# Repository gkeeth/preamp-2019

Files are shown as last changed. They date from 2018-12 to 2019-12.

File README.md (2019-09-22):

# preamp-2019

Balanced input & output preamplifier with volume and balance controls.

Based on preamps designed by Doug Self (see Small Signal Audio Design by Douglas Self)

The preamp is split over several PCBs, with a kicad project for each:
1. balanced_amplifier: balanced amplifier with volume/balance controls
2. power_supply: power supplies for
    - positive analog rail
    - negative analog rail
    - digital/relay rail
3. input_output_board: board with input/output jacks and relays to select the desired input
4. front_panel_board: board with input selection switch and headphone/main output switch
5. headphone_amp: a very basic headphone amplifier that converts the balanced
   output of the balanced_amplifier board to an unbalanced signal, and buffers it

This work is licensed under a [Creative Commons Attribution-ShareAlike 4.0
International License][cc-by-sa].

[][cc-by-sa]

[cc-by-sa]: http://creativecommons.org/licenses/by-sa/4.0/
[cc-by-sa-image]: https://licensebuttons.net/l/by-sa/4.0/88x31.png
[cc-by-sa-shield]: https://img.shields.io/badge/License-CC%20BY--SA%204.0-lightgrey.svg

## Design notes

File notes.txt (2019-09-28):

enclosure: consider Hammond 1441-16BK3CWW
enclosure: Hammond 1444-24
dimensions: 12" x 8" x 3"
necessary parts:
 - enclosure (1444-24)
 - bottom plate (1434-22)
 - screws (1421J6)
 - feet (1421T6CL)

transformer: Triad VPT30-830
dimensions: 74mm D x 34mm H
15VAC parallel / 30VAC series, 25VA max

power switch: consider E-switch RC1083BBLKBLKFF0
4.7mm faston/0.187"

power filter/inlet: consider Schaffner FN9260-6-06
faston 6.3mm/0.25"

input selection switch: https://www.digikey.com/product-detail/en/c-k/A10405RNCQ/CKN11161-ND/3751691
8pos, adjustable stop, 45deg throw: https://www.digikey.com/products/en?keywords=a12505rncq

input jacks: NCJ6FA-H-0
output jacks: NC3MAH

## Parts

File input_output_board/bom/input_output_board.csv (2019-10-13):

Source: | /home/graham/Projects/preamp-2019/input_output_board/input_output_board.sch
Date: | Sun 13 Oct 2019 07:21:07 PM EDT
Tool: | Eeschema 5.1.4
Generator: | /usr/share/kicad/plugins/bom_csv_grouped_by_value.py
Component Count: | 19
Individual Components:
Item | Qty | Reference(s) | Value | LibPart | Footprint | Datasheet | Distributor | Distributor PN | Manufacturer | Manufacturer PN | URL | Unit Price
 |  | D1 | MRA4004T3G | Device:D | Diode_SMD:D_SMA | http://www.onsemi.com/pub_link/Collateral/MRA4003T3-D.PDF | Digikey | MRA4004T3GOSCT-ND | On Semiconductor | MRA4004T3G | https://www.digikey.com/products/en/discrete-semiconductor-products/diodes-rectifiers-single/280?k=MRA4004T3G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 | 0.29
 |  | D2 | MRA4004T3G | Device:D | Diode_SMD:D_SMA | http://www.onsemi.com/pub_link/Collateral/MRA4003T3-D.PDF | Digikey | MRA4004T3GOSCT-ND | On Semiconductor | MRA4004T3G | https://www.digikey.com/products/en/discrete-semiconductor-products/diodes-rectifiers-single/280?k=MRA4004T3G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 | 0.29
 |  | D3 | MRA4004T3G | Device:D | Diode_SMD:D_SMA | http://www.onsemi.com/pub_link/Collateral/MRA4003T3-D.PDF | Digikey | MRA4004T3GOSCT-ND | On Semiconductor | MRA4004T3G | https://www.digikey.com/products/en/discrete-semiconductor-products/diodes-rectifiers-single/280?k=MRA4004T3G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 | 0.29
 |  | D4 | MRA4004T3G | Device:D | Diode_SMD:D_SMA | http://www.onsemi.com/pub_link/Collateral/MRA4003T3-D.PDF | Digikey | MRA4004T3GOSCT-ND | On Semiconductor | MRA4004T3G | https://www.digikey.com/products/en/discrete-semiconductor-products/diodes-rectifiers-single/280?k=MRA4004T3G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 | 0.29
 |  | D5 | MRA4004T3G | Device:D | Diode_SMD:D_SMA | http://www.onsemi.com/pub_link/Collateral/MRA4003T3-D.PDF | Digikey | MRA4004T3GOSCT-ND | On Semiconductor | MRA4004T3G | https://www.digikey.com/products/en/discrete-semiconductor-products/diodes-rectifiers-single/280?k=MRA4004T3G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 | 0.29
 |  | J1 | Neutrik_NCJ6FA-H-0 | Connector_gkeeth:Neutrik_NCJ6FA-H-0 | Connector_Audio_project:Jack_XLR-6.35mm_Neutrik_NCJ6FA-H-0_Horizontal | https://www.neutrik.us/en-us/product/ncj6fa-h-0 | Mouser | 568-NCJ6FA-H-0 | Neutrik | NCJ6FA-H-0 | https://www.mouser.com/ProductDetail/Neutrik/NCJ6FA-H-0?qs=sGAEpiMZZMv0W4pxf2HiVz0kF5fvPbmUN84Qkb8AgIM%3D | 2.14
 |  | J2 | Neutrik_NCJ6FA-H-0 | Connector_gkeeth:Neutrik_NCJ6FA-H-0 | Connector_Audio_project:Jack_XLR-6.35mm_Neutrik_NCJ6FA-H-0_Horizontal | https://www.neutrik.us/en-us/product/ncj6fa-h-0 | Mouser | 568-NCJ6FA-H-0 | Neutrik | NCJ6FA-H-0 | https://www.mouser.com/ProductDetail/Neutrik/NCJ6FA-H-0?qs=sGAEpiMZZMv0W4pxf2HiVz0kF5fvPbmUN84Qkb8AgIM%3D | 2.14
 |  | J3 | Neutrik_NCJ6FA-H-0 | Connector_gkeeth:Neutrik_NCJ6FA-H-0 | Connector_Audio_project:Jack_XLR-6.35mm_Neutrik_NCJ6FA-H-0_Horizontal | https://www.neutrik.us/en-us/product/ncj6fa-h-0 | Mouser | 568-NCJ6FA-H-0 | Neutrik | NCJ6FA-H-0 | https://www.mouser.com/ProductDetail/Neutrik/NCJ6FA-H-0?qs=sGAEpiMZZMv0W4pxf2HiVz0kF5fvPbmUN84Qkb8AgIM%3D | 2.14
 |  | J4 | Neutrik_NCJ6FA-H-0 | Connector_gkeeth:Neutrik_NCJ6FA-H-0 | Connector_Audio_project:Jack_XLR-6.35mm_Neutrik_NCJ6FA-H-0_Horizontal | https://www.neutrik.us/en-us/product/ncj6fa-h-0 | Mouser | 568-NCJ6FA-H-0 | Neutrik | NCJ6FA-H-0 | https://www.mouser.com/ProductDetail/Neutrik/NCJ6FA-H-0?qs=sGAEpiMZZMv0W4pxf2HiVz0kF5fvPbmUN84Qkb8AgIM%3D | 2.14
 |  | J5 | Neutrik_NC3MAH | Connector_gkeeth:Neutrik_NC3MAH | Connector_Audio_project:Jack_XLR_Neutrik_NC3MAH_Horizontal | https://www.neutrik.us/en-us/product/nc3mah | Mouser | 568-NC3MAH | Neutrik | NC3MAH | https://www.mouser.com/ProductDetail/Neutrik/NC3MAH | 1.25
 |  | J6 | Conn_02x05_Odd_Even | Connector_Generic:Conn_02x05_Odd_Even | Connector_Molex_C-Grid:Molex_C-Grid_70246-1001_2x05_P2.54mm_Vertical | https://www.molex.com/pdm_docs/sd/702461001_sd.pdf | Digikey | WM9219-ND | Molex | 0702461001 | https://www.digikey.com/products/en?keywords=70246-1001 | 1.70
 |  | J7 | Molex_SL_01x02_Male | Connector_gkeeth:Molex_SL_01x02_Male | Connector_Molex_SL:Molex_SL_A-70553-0001_1x02_P2.54mm_Horizontal | https://www.molex.com/pdm_docs/sd/705430001_sd.pdf | Digikey | WM4900-ND | Molex | 0705430001 | https://www.digikey.com/products/en?keywords=70553-0001 | 0.74
 |  | J8 | Molex_SL_01x02_Male | Connector_gkeeth:Molex_SL_01x02_Male | Connector_Molex_SL:Molex_SL_A-70553-0001_1x02_P2.54mm_Horizontal | https://www.molex.com/pdm_docs/sd/705430001_sd.pdf | Digikey | WM4900-ND | Molex | 0705430001 | https://www.digikey.com/products/en?keywords=70553-0001 | 0.74
 |  | J9 | Molex_SL_01x02_Male | Connector_gkeeth:Molex_SL_01x02_Male | Connector_Molex_SL:Molex_SL_A-70553-0001_1x02_P2.54mm_Horizontal | https://www.molex.com/pdm_docs/sd/705430001_sd.pdf | Digikey | WM4900-ND | Molex | 0705430001 | https://www.digikey.com/products/en?keywords=70553-0001 | 0.74
 |  | K1 | G6S-2 | Relay:G6S-2 | Relay_SMD:Relay_DPDT_Omron_G6S-2F | http://omronfs.omron.com/en_US/ecb/products/pdf/en-g6s.pdf | Digikey | Z889-ND | Omron | G6S-2F DC12 | https://www.digikey.com/product-detail/en/omron-electronics-inc-emc-div/G6S-2F-DC12/Z889-ND/27491 | 3.64
 |  | K2 | G6S-2 | Relay:G6S-2 | Relay_SMD:Relay_DPDT_Omron_G6S-2F | http://omronfs.omron.com/en_US/ecb/products/pdf/en-g6s.pdf | Digikey | Z889-ND | Omron | G6S-2F DC12 | https://www.digikey.com/product-detail/en/omron-electronics-inc-emc-div/G6S-2F-DC12/Z889-ND/27491 | 3.64
 |  | K3 | G6S-2 | Relay:G6S-2 | Relay_SMD:Relay_DPDT_Omron_G6S-2F | http://omronfs.omron.com/en_US/ecb/products/pdf/en-g6s.pdf | Digikey | Z889-ND | Omron | G6S-2F DC12 | https://www.digikey.com/product-detail/en/omron-electronics-inc-emc-div/G6S-2F-DC12/Z889-ND/27491 | 3.64
 |  | K4 | G6S-2 | Relay:G6S-2 | Relay_SMD:Relay_DPDT_Omron_G6S-2F | http://omronfs.omron.com/en_US/ecb/products/pdf/en-g6s.pdf | Digikey | Z889-ND | Omron | G6S-2F DC12 | https://www.digikey.com/product-detail/en/omron-electronics-inc-emc-div/G6S-2F-DC12/Z889-ND/27491 | 3.64
 |  | K5 | G6S-2 | Relay:G6S-2 | Relay_SMD:Relay_DPDT_Omron_G6S-2F | http://omronfs.omron.com/en_US/ecb/products/pdf/en-g6s.pdf | Digikey | Z889-ND | Omron | G6S-2F DC12 | https://www.digikey.com/product-detail/en/omron-electronics-inc-emc-div/G6S-2F-DC12/Z889-ND/27491 | 3.64
Collated Components:
Item | Qty | Reference(s) | Value | LibPart | Footprint | Datasheet | Distributor | Distributor PN | Manufacturer | Manufacturer PN | URL | Unit Price
1 | 5 | D1, D2, D3, D4, D5 | MRA4004T3G | Device:D | Diode_SMD:D_SMA | http://www.onsemi.com/pub_link/Collateral/MRA4003T3-D.PDF | Digikey | MRA4004T3GOSCT-ND | On Semiconductor | MRA4004T3G | https://www.digikey.com/products/en/discrete-semiconductor-products/diodes-rectifiers-single/280?k=MRA4004T3G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 | 0.29
2 | 4 | J1, J2, J3, J4 | Neutrik_NCJ6FA-H-0 | Connector_gkeeth:Neutrik_NCJ6FA-H-0 | Connector_Audio_project:Jack_XLR-6.35mm_Neutrik_NCJ6FA-H-0_Horizontal | https://www.neutrik.us/en-us/product/ncj6fa-h-0 | Mouser | 568-NCJ6FA-H-0 | Neutrik | NCJ6FA-H-0 | https://www.mouser.com/ProductDetail/Neutrik/NCJ6FA-H-0?qs=sGAEpiMZZMv0W4pxf2HiVz0kF5fvPbmUN84Qkb8AgIM%3D | 2.14
3 | 1 | J5 | Neutrik_NC3MAH | Connector_gkeeth:Neutrik_NC3MAH | Connector_Audio_project:Jack_XLR_Neutrik_NC3MAH_Horizontal | https://www.neutrik.us/en-us/product/nc3mah | Mouser | 568-NC3MAH | Neutrik | NC3MAH | https://www.mouser.com/ProductDetail/Neutrik/NC3MAH | 1.25
4 | 1 | J6 | Conn_02x05_Odd_Even | Connector_Generic:Conn_02x05_Odd_Even | Connector_Molex_C-Grid:Molex_C-Grid_70246-1001_2x05_P2.54mm_Vertical | https://www.molex.com/pdm_docs/sd/702461001_sd.pdf | Digikey | WM9219-ND | Molex | 0702461001 | https://www.digikey.com/products/en?keywords=70246-1001 | 1.70
5 | 3 | J7, J8, J9 | Molex_SL_01x02_Male | Connector_gkeeth:Molex_SL_01x02_Male | Connector_Molex_SL:Molex_SL_A-70553-0001_1x02_P2.54mm_Horizontal | https://www.molex.com/pdm_docs/sd/705430001_sd.pdf | Digikey | WM4900-ND | Molex | 0705430001 | https://www.digikey.com/products/en?keywords=70553-0001 | 0.74
6 | 5 | K1, K2, K3, K4, K5 | G6S-2 | Relay:G6S-2 | Relay_SMD:Relay_DPDT_Omron_G6S-2F | http://omronfs.omron.com/en_US/ecb/products/pdf/en-g6s.pdf | Digikey | Z889-ND | Omron | G6S-2F DC12 | https://www.digikey.com/product-detail/en/omron-electronics-inc-emc-div/G6S-2F-DC12/Z889-ND/27491 | 3.64

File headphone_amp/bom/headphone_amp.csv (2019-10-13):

Source: | /home/graham/Projects/preamp-2019/headphone_amp/headphone_amp.sch
Date: | Sun 13 Oct 2019 07:17:30 PM EDT
Tool: | Eeschema 5.1.4
Generator: | /usr/share/kicad/plugins/bom_csv_grouped_by_value.py
Component Count: | 41
Individual Components:
Item | Qty | Reference(s) | Value | LibPart | Footprint | Datasheet | Dielectric | Distributor | Distributor PN | Manufacturer | Manufacturer PN | URL | Unit Price | Voltage Rating
 |  | C1 | 22p | Device:C | Capacitor_SMD:C_0603_1608Metric_Pad1.05x0.95mm_HandSolder | ~ | C0G/NP0 | Mouser | 80-C0603C220J5G7411 | KEMET | C0603C220J5GAC7411 | https://www.mouser.com/ProductDetail/80-C0603C220J5G7411 | 0.23
 |  | C2 | 22p | Device:C | Capacitor_SMD:C_0603_1608Metric_Pad1.05x0.95mm_HandSolder | ~ | C0G/NP0 | Mouser | 80-C0603C220J5G7411 | KEMET | C0603C220J5GAC7411 | https://www.mouser.com/ProductDetail/80-C0603C220J5G7411 | 0.23
 |  | C3 | 220u | Device:C | Capacitor_THT:C_Radial_D12.5mm_H20.0mm_P5.00mm | http://nichicon-us.com/english/products/pdfs/e-uvp.pdf | Nonpolarized Electrolytic | Digikey | 493-16138-ND | Nichicon | UVP1V221MHD | https://www.digikey.com/product-detail/en/nichicon/UVP1V221MHD/493-16138-ND/2539596 | 0.87 | 35V
 |  | C4 | 22p | Device:C | Capacitor_SMD:C_0603_1608Metric_Pad1.05x0.95mm_HandSolder | ~ | C0G/NP0 | Mouser | 80-C0603C220J5G7411 | KEMET | C0603C220J5GAC7411 | https://www.mouser.com/ProductDetail/80-C0603C220J5G7411 | 0.23
 |  | C5 | 22p | Device:C | Capacitor_SMD:C_0603_1608Metric_Pad1.05x0.95mm_HandSolder | ~ | C0G/NP0 | Mouser | 80-C0603C220J5G7411 | KEMET | C0603C220J5GAC7411 | https://www.mouser.com/ProductDetail/80-C0603C220J5G7411 | 0.23
 |  | C6 | 220u | Device:C | Capacitor_THT:C_Radial_D12.5mm_H20.0mm_P5.00mm | http://nichicon-us.com/english/products/pdfs/e-uvp.pdf | Nonpolarized Electrolytic | Digikey | 493-16138-ND | Nichicon | UVP1V221MHD | https://www.digikey.com/product-detail/en/nichicon/UVP1V221MHD/493-16138-ND/2539596 | 0.87 | 35V
 |  | C7 | 100n | Device:C | Capacitor_SMD:C_0805_2012Metric_Pad1.15x1.40mm_HandSolder | https://psearch.en.murata.com/capacitor/product/GCM21BR72A104KA37%23.pdf | X7R | Digikey | 490-8051-1-ND | Murata | GCM21BR72A104KA37K | https://www.digikey.com/product-detail/en/murata-electronics-north-america/GCM21BR72A104KA37K/490-8051-1-ND/4380336 | 0.43
 |  | C8 | 100u | Device:CP1 | Capacitor_THT:CP_Radial_D6.3mm_P2.50mm | http://nichicon-us.com/english/products/pdfs/e-uvr.pdf | Electrolytic | Digikey | 493-1081-ND | Nichicon | UVR1V101MED | https://www.digikey.com/product-detail/en/nichicon/UVR1V101MED/493-1081-ND/588822 | 0.26 | 35V
 |  | C9 | 100u | Device:CP1 | Capacitor_THT:CP_Radial_D6.3mm_P2.50mm | http://nichicon-us.com/english/products/pdfs/e-uvr.pdf | Electrolytic | Digikey | 493-1081-ND | Nichicon | UVR1V101MED | https://www.digikey.com/product-detail/en/nichicon/UVR1V101MED/493-1081-ND/588822 | 0.26 | 35V
 |  | D1 | 1N4148WS | Diode:1N4148WS | Diode_SMD:D_SOD-323 | https://www.vishay.com/docs/85751/1n4148ws.pdf |  | Mouser | 512-1N4148WS | ON Semiconductor | 1N4148WS | https://www.mouser.com/ProductDetail/512-1N4148WS | 0.15
 |  | D2 | 1N4148WS | Diode:1N4148WS | Diode_SMD:D_SOD-323 | https://www.vishay.com/docs/85751/1n4148ws.pdf |  | Mouser | 512-1N4148WS | ON Semiconductor | 1N4148WS | https://www.mouser.com/ProductDetail/512-1N4148WS | 0.15
 |  | D3 | 1N4148WS | Diode:1N4148WS | Diode_SMD:D_SOD-323 | https://www.vishay.com/docs/85751/1n4148ws.pdf |  | Mouser | 512-1N4148WS | ON Semiconductor | 1N4148WS | https://www.mouser.com/ProductDetail/512-1N4148WS | 0.15
 |  | D4 | 1N4148WS | Diode:1N4148WS | Diode_SMD:D_SOD-323 | https://www.vishay.com/docs/85751/1n4148ws.pdf |  | Mouser | 512-1N4148WS | ON Semiconductor | 1N4148WS | https://www.mouser.com/ProductDetail/512-1N4148WS | 0.15
 |  | H1 | MountingHole_Pad | Mechanical:MountingHole_Pad | MountingHole:MountingHole_3.2mm_M3_Pad | ~
 |  | H2 | MountingHole_Pad | Mechanical:MountingHole_Pad | MountingHole:MountingHole_3.2mm_M3_Pad | ~
 |  | J1 | Molex_SL_01x02_Male | Connector_gkeeth:Molex_SL_01x02_Male | Connector_Molex_SL:Molex_SL_A-70553-0001_1x02_P2.54mm_Horizontal | https://www.molex.com/pdm_docs/sd/705430001_sd.pdf |  | Mouser | 538-70553-0001 | Molex | 70553-0001 | https://www.mouser.com/ProductDetail/538-70553-0001 | 0.71
 |  | J2 | Molex_SL_01x02_Male | Connector_gkeeth:Molex_SL_01x02_Male | Connector_Molex_SL:Molex_SL_A-70553-0001_1x02_P2.54mm_Horizontal | https://www.molex.com/pdm_docs/sd/705430001_sd.pdf |  | Mouser | 538-70553-0001 | Molex | 70553-0001 | https://www.mouser.com/ProductDetail/538-70553-0001 | 0.71
 |  | J3 | Molex_SL_01x03_Male | Connector_gkeeth:Molex_SL_01x03_Male | Connector_Molex_SL:Molex_SL_A-70553-0002_1x03_P2.54mm_Horizontal | https://www.molex.com/pdm_docs/sd/705430001_sd.pdf |  | Mouser | 538-70553-0002 | Molex | 70553-0002 | https://www.mouser.com/ProductDetail/538-70553-0002 | 1.12
 |  | J4 | Molex_SL_01x03_Male | Connector_gkeeth:Molex_SL_01x03_Male | Connector_Molex_SL:Molex_SL_A-70553-0002_1x03_P2.54mm_Horizontal | https://www.molex.com/pdm_docs/sd/705430001_sd.pdf |  | Mouser | 538-70553-0002 | Molex | 70553-0002 | https://www.mouser.com/ProductDetail/538-70553-0002 | 1.12
 |  | NT1 | Net-Tie_2 | Device:Net-Tie_2 | NetTie:NetTie-2_SMD_Pad2.0mm | ~
 |  | Q1 | PZTA42 | Transistor_BJT:PZTA42 | Package_TO_SOT_SMD:SOT-223-3_TabPin2 | https://www.onsemi.com/pub/Collateral/PZTA42T1-D.PDF |  | Digikey | PZTA42T1GOSCT-ND | ON Semiconductor | PZTA42T1G | https://www.digikey.com/product-detail/en/on-semiconductor/PZTA42T1G/PZTA42T1GOSCT-ND/1139989 | 0.43
 |  | Q2 | PZTA92 | Transistor_BJT:PZTA92 | Package_TO_SOT_SMD:SOT-223-3_TabPin2 | https://www.onsemi.com/pub/Collateral/PZTA92T1-D.PDF |  | Digikey | PZTA92T1GOSCT-ND | ON Semiconductor | PZTA92T1G | https://www.digikey.com/product-detail/en/on-semiconductor/PZTA92T1G/PZTA92T1GOSCT-ND/920290 | 0.44
 |  | Q3 | PZTA42 | Transistor_BJT:PZTA42 | Package_TO_SOT_SMD:SOT-223-3_TabPin2 | https://www.onsemi.com/pub/Collateral/PZTA42T1-D.PDF |  | Digikey | PZTA42T1GOSCT-ND | ON Semiconductor | PZTA42T1G | https://www.digikey.com/product-detail/en/on-semiconductor/PZTA42T1G/PZTA42T1GOSCT-ND/1139989 | 0.43
 |  | Q4 | PZTA92 | Transistor_BJT:PZTA92 | Package_TO_SOT_SMD:SOT-223-3_TabPin2 | https://www.onsemi.com/pub/Collateral/PZTA92T1-D.PDF |  | Digikey | PZTA92T1GOSCT-ND | ON Semiconductor | PZTA92T1G | https://www.digikey.com/product-detail/en/on-semiconductor/PZTA92T1G/PZTA92T1GOSCT-ND/920290 | 0.44
 |  | R1 | 10k | Device:R | Resistor_SMD:R_0603_1608Metric_Pad1.05x0.95mm_HandSolder | http://www.yageo.com/documents/recent/PYu-RT_1-to-0.01_RoHS_L_11.pdf |  | Digikey | YAG2321CT-ND | Yageo | RT0603FRE0710KL | https://www.digikey.com/product-detail/en/yageo/RT0603FRE0710KL/YAG2321CT-ND/5252435 | 0.10
 |  | R2 | 22k | Device:R | Resistor_SMD:R_0603_1608Metric_Pad1.05x0.95mm_HandSolder | http://www.yageo.com/documents/recent/PYu-RT_1-to-0.01_RoHS_L_11.pdf |  | Mouser | 603-RT0603FRE1322KL | Yageo | RT0603FRE1322KL | https://www.mouser.com/ProductDetail/603-RT0603FRE1322KL | 0.19
 |  | R3 | 10k | Device:R | Resistor_SMD:R_0603_1608Metric_Pad1.05x0.95mm_HandSolder | http://www.yageo.com/documents/recent/PYu-RT_1-to-0.01_RoHS_L_11.pdf |  | Digikey | YAG2321CT-ND | Yageo | RT0603FRE0710KL | https://www.digikey.com/product-detail/en/yageo/RT0603FRE0710KL/YAG2321CT-ND/5252435 | 0.10
 |  | R4 | 22k | Device:R | Resistor_SMD:R_0603_1608Metric_Pad1.05x0.95mm_HandSolder | http://www.yageo.com/documents/recent/PYu-RT_1-to-0.01_RoHS_L_11.pdf |  | Mouser | 603-RT0603FRE1322KL | Yageo | RT0603FRE1322KL | https://www.mouser.com/ProductDetail/603-RT0603FRE1322KL | 0.19
 |  | R5 | 4.7k | Device:R | Resistor_SMD:R_0603_1608Metric_Pad1.05x0.95mm_HandSolder | http://www.yageo.com/documents/recent/PYu-RT_1-to-0.01_RoHS_L_11.pdf |  | Mouser | 603-RT0603FRE074K7L | Yageo | RT0603FRE074K7L | https://www.mouser.com/ProductDetail/603-RT0603FRE074K7L | 0.10
 |  | R6 | 10 | Device:R | Resistor_SMD:R_0603_1608Metric_Pad1.05x0.95mm_HandSolder | https://www.seielect.com/Catalog/SEI-rncp.pdf |  | Digikey | RNCP0603FTD10R0CT-ND | Stackpole | RNCP0603FTD10R0 | https://www.digikey.com/product-detail/en/stackpole-electronics-inc/RNCP0603FTD10R0/RNCP0603FTD10R0CT-ND/2240413 | 0.10
 |  | R7 | 10 | Device:R | Resistor_SMD:R_0603_1608Metric_Pad1.05x0.95mm_HandSolder | https://www.seielect.com/Catalog/SEI-rncp.pdf |  | Digikey | RNCP0603FTD10R0CT-ND | Stackpole | RNCP0603FTD10R0 | https://www.digikey.com/product-detail/en/stackpole-electronics-inc/RNCP0603FTD10R0/RNCP0603FTD10R0CT-ND/2240413 | 0.10
 |  | R8 | 22k | Device:R | Resistor_SMD:R_0603_1608Metric_Pad1.05x0.95mm_HandSolder | http://www.yageo.com/documents/recent/PYu-RT_1-to-0.01_RoHS_L_11.pdf |  | Mouser | 603-RT0603FRE1322KL | Yageo | RT0603FRE1322KL | https://www.mouser.com/ProductDetail/603-RT0603FRE1322KL | 0.19
 |  | R9 | 10k | Device:R | Resistor_SMD:R_0603_1608Metric_Pad1.05x0.95mm_HandSolder | http://www.yageo.com/documents/recent/PYu-RT_1-to-0.01_RoHS_L_11.pdf |  | Digikey | YAG2321CT-ND | Yageo | RT0603FRE0710KL | https://www.digikey.com/product-detail/en/yageo/RT0603FRE0710KL/YAG2321CT-ND/5252435 | 0.10
 |  | R10 | 22k | Device:R | Resistor_SMD:R_0603_1608Metric_Pad1.05x0.95mm_HandSolder | http://www.yageo.com/documents/recent/PYu-RT_1-to-0.01_RoHS_L_11.pdf |  | Mouser | 603-RT0603FRE1322KL | Yageo | RT0603FRE1322KL | https://www.mouser.com/ProductDetail/603-RT0603FRE1322KL | 0.19
 |  | R11 | 10k | Device:R | Resistor_SMD:R_0603_1608Metric_Pad1.05x0.95mm_HandSolder | http://www.yageo.com/documents/recent/PYu-RT_1-to-0.01_RoHS_L_11.pdf |  | Digikey | YAG2321CT-ND | Yageo | RT0603FRE0710KL | https://www.digikey.com/product-detail/en/yageo/RT0603FRE0710KL/YAG2321CT-ND/5252435 | 0.10
 |  | R12 | 22k | Device:R | Resistor_SMD:R_0603_1608Metric_Pad1.05x0.95mm_HandSolder | http://www.yageo.com/documents/recent/PYu-RT_1-to-0.01_RoHS_L_11.pdf |  | Mouser | 603-RT0603FRE1322KL | Yageo | RT0603FRE1322KL | https://www.mouser.com/ProductDetail/603-RT0603FRE1322KL | 0.19
 |  | R13 | 4.7k | Device:R | Resistor_SMD:R_0603_1608Metric_Pad1.05x0.95mm_HandSolder | http://www.yageo.com/documents/recent/PYu-RT_1-to-0.01_RoHS_L_11.pdf |  | Mouser | 603-RT0603FRE074K7L | Yageo | RT0603FRE074K7L | https://www.mouser.com/ProductDetail/603-RT0603FRE074K7L | 0.10
 |  | R14 | 10 | Device:R | Resistor_SMD:R_0603_1608Metric_Pad1.05x0.95mm_HandSolder | https://www.seielect.com/Catalog/SEI-rncp.pdf |  | Digikey | RNCP0603FTD10R0CT-ND | Stackpole | RNCP0603FTD10R0 | https://www.digikey.com/product-detail/en/stackpole-electronics-inc/RNCP0603FTD10R0/RNCP0603FTD10R0CT-ND/2240413 | 0.10
 |  | R15 | 10 | Device:R | Resistor_SMD:R_0603_1608Metric_Pad1.05x0.95mm_HandSolder | https://www.seielect.com/Catalog/SEI-rncp.pdf |  | Digikey | RNCP0603FTD10R0CT-ND | Stackpole | RNCP0603FTD10R0 | https://www.digikey.com/product-detail/en/stackpole-electronics-inc/RNCP0603FTD10R0/RNCP0603FTD10R0CT-ND/2240413 | 0.10
 |  | R16 | 22k | Device:R | Resistor_SMD:R_0603_1608Metric_Pad1.05x0.95mm_HandSolder | http://www.yageo.com/documents/recent/PYu-RT_1-to-0.01_RoHS_L_11.pdf |  | Mouser | 603-RT0603FRE1322KL | Yageo | RT0603FRE1322KL | https://www.mouser.com/ProductDetail/603-RT0603FRE1322KL | 0.19
 |  | U1 | NE5532 | Amplifier_Operational:NE5532 | Package_SO:SOIC-8_3.9x4.9mm_P1.27mm | http://www.ti.com/lit/ds/symlink/ne5532.pdf |  | Digikey | NE5532AD8R2GOSCT-ND | ON Semiconductor | NE5532AD8R2G | https://www.digikey.com/products/en?keywords=NE5532AD8R2GOSCT-ND | 0.90
Collated Components:
Item | Qty | Reference(s) | Value | LibPart | Footprint | Datasheet | Dielectric | Distributor | Distributor PN | Manufacturer | Manufacturer PN | URL | Unit Price | Voltage Rating
1 | 4 | C1, C2, C4, C5 | 22p | Device:C | Capacitor_SMD:C_0603_1608Metric_Pad1.05x0.95mm_HandSolder | ~ | C0G/NP0 | Mouser | 80-C0603C220J5G7411 | KEMET | C0603C220J5GAC7411 | https://www.mouser.com/ProductDetail/80-C0603C220J5G7411 | 0.23
2 | 2 | C3, C6 | 220u | Device:C | Capacitor_THT:C_Radial_D12.5mm_H20.0mm_P5.00mm | http://nichicon-us.com/english/products/pdfs/e-uvp.pdf | Nonpolarized Electrolytic | Digikey | 493-16138-ND | Nichicon | UVP1V221MHD | https://www.digikey.com/product-detail/en/nichicon/UVP1V221MHD/493-16138-ND/2539596 | 0.87 | 35V
3 | 1 | C7 | 100n | Device:C | Capacitor_SMD:C_0805_2012Metric_Pad1.15x1.40mm_HandSolder | https://psearch.en.murata.com/capacitor/product/GCM21BR72A104KA37%23.pdf | X7R | Digikey | 490-8051-1-ND | Murata | GCM21BR72A104KA37K | https://www.digikey.com/product-detail/en/murata-electronics-north-america/GCM21BR72A104KA37K/490-8051-1-ND/4380336 | 0.43
4 | 2 | C8, C9 | 100u | Device:CP1 | Capacitor_THT:CP_Radial_D6.3mm_P2.50mm | http://nichicon-us.com/english/products/pdfs/e-uvr.pdf | Electrolytic | Digikey | 493-1081-ND | Nichicon | UVR1V101MED | https://www.digikey.com/product-detail/en/nichicon/UVR1V101MED/493-1081-ND/588822 | 0.26 | 35V
5 | 4 | D1, D2, D3, D4 | 1N4148WS | Diode:1N4148WS | Diode_SMD:D_SOD-323 | https://www.vishay.com/docs/85751/1n4148ws.pdf |  | Mouser | 512-1N4148WS | ON Semiconductor | 1N4148WS | https://www.mouser.com/ProductDetail/512-1N4148WS | 0.15
6 | 2 | H1, H2 | MountingHole_Pad | Mechanical:MountingHole_Pad | MountingHole:MountingHole_3.2mm_M3_Pad | ~
7 | 2 | J1, J2 | Molex_SL_01x02_Male | Connector_gkeeth:Molex_SL_01x02_Male | Connector_Molex_SL:Molex_SL_A-70553-0001_1x02_P2.54mm_Horizontal | https://www.molex.com/pdm_docs/sd/705430001_sd.pdf |  | Mouser | 538-70553-0001 | Molex | 70553-0001 | https://www.mouser.com/ProductDetail/538-70553-0001 | 0.71
8 | 2 | J3, J4 | Molex_SL_01x03_Male | Connector_gkeeth:Molex_SL_01x03_Male | Connector_Molex_SL:Molex_SL_A-70553-0002_1x03_P2.54mm_Horizontal | https://www.molex.com/pdm_docs/sd/705430001_sd.pdf |  | Mouser | 538-70553-0002 | Molex | 70553-0002 | https://www.mouser.com/ProductDetail/538-70553-0002 | 1.12
9 | 1 | NT1 | Net-Tie_2 | Device:Net-Tie_2 | NetTie:NetTie-2_SMD_Pad2.0mm | ~
10 | 2 | Q1, Q3 | PZTA42 | Transistor_BJT:PZTA42 | Package_TO_SOT_SMD:SOT-223-3_TabPin2 | https://www.onsemi.com/pub/Collateral/PZTA42T1-D.PDF |  | Digikey | PZTA42T1GOSCT-ND | ON Semiconductor | PZTA42T1G | https://www.digikey.com/product-detail/en/on-semiconductor/PZTA42T1G/PZTA42T1GOSCT-ND/1139989 | 0.43
11 | 2 | Q2, Q4 | PZTA92 | Transistor_BJT:PZTA92 | Package_TO_SOT_SMD:SOT-223-3_TabPin2 | https://www.onsemi.com/pub/Collateral/PZTA92T1-D.PDF |  | Digikey | PZTA92T1GOSCT-ND | ON Semiconductor | PZTA92T1G | https://www.digikey.com/product-detail/en/on-semiconductor/PZTA92T1G/PZTA92T1GOSCT-ND/920290 | 0.44
12 | 4 | R1, R3, R9, R11 | 10k | Device:R | Resistor_SMD:R_0603_1608Metric_Pad1.05x0.95mm_HandSolder | http://www.yageo.com/documents/recent/PYu-RT_1-to-0.01_RoHS_L_11.pdf |  | Digikey | YAG2321CT-ND | Yageo | RT0603FRE0710KL | https://www.digikey.com/product-detail/en/yageo/RT0603FRE0710KL/YAG2321CT-ND/5252435 | 0.10
13 | 6 | R2, R4, R8, R10, R12, R16 | 22k | Device:R | Resistor_SMD:R_0603_1608Metric_Pad1.05x0.95mm_HandSolder | http://www.yageo.com/documents/recent/PYu-RT_1-to-0.01_RoHS_L_11.pdf |  | Mouser | 603-RT0603FRE1322KL | Yageo | RT0603FRE1322KL | https://www.mouser.com/ProductDetail/603-RT0603FRE1322KL | 0.19
14 | 2 | R5, R13 | 4.7k | Device:R | Resistor_SMD:R_0603_1608Metric_Pad1.05x0.95mm_HandSolder | http://www.yageo.com/documents/recent/PYu-RT_1-to-0.01_RoHS_L_11.pdf |  | Mouser | 603-RT0603FRE074K7L | Yageo | RT0603FRE074K7L | https://www.mouser.com/ProductDetail/603-RT0603FRE074K7L | 0.10
15 | 4 | R6, R7, R14, R15 | 10 | Device:R | Resistor_SMD:R_0603_1608Metric_Pad1.05x0.95mm_HandSolder | https://www.seielect.com/Catalog/SEI-rncp.pdf |  | Digikey | RNCP0603FTD10R0CT-ND | Stackpole | RNCP0603FTD10R0 | https://www.digikey.com/product-detail/en/stackpole-electronics-inc/RNCP0603FTD10R0/RNCP0603FTD10R0CT-ND/2240413 | 0.10
16 | 1 | U1 | NE5532 | Amplifier_Operational:NE5532 | Package_SO:SOIC-8_3.9x4.9mm_P1.27mm | http://www.ti.com/lit/ds/symlink/ne5532.pdf |  | Digikey | NE5532AD8R2GOSCT-ND | ON Semiconductor | NE5532AD8R2G | https://www.digikey.com/products/en?keywords=NE5532AD8R2GOSCT-ND | 0.90

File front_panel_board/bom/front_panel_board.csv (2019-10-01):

Source: | /home/graham/Projects/preamp-2019/front_panel_board/front_panel_board.sch
Date: | Tue 01 Oct 2019 08:37:29 AM EDT
Tool: | Eeschema 5.1.4
Generator: | /usr/share/kicad/plugins/bom_csv_grouped_by_value.py
Component Count: | 10
Individual Components:
Item | Qty | Reference(s) | Value | LibPart | Footprint | Datasheet | Distributor | Distributor PN | Manufacturer | Manufacturer PN | URL | Unit Price
 |  | D1 | LED_ALT | Device:LED_ALT | LED_THT:LED_D5.0mm | http://www.kingbrightusa.com/images/catalog/SPEC/WP7113LGD.pdf | Digikey | 754-1265-ND | Kingbright | WP7113LGD | https://www.digikey.com/product-detail/en/kingbright/WP7113LGD/754-1265-ND/1747664 | 0.48
 |  | J1 | Molex_SL_01x02_Male | Connector_gkeeth:Molex_SL_01x02_Male | Connector_Molex_SL:Molex_SL_A-70543-0001_1x02_P2.54mm_Vertical | https://www.molex.com/pdm_docs/sd/705430001_sd.pdf | Digikey | WM4800-ND | Molex | 0705430001 | https://www.molex.com/pdm_docs/sd/705430001_sd.pdf | 0.84
 |  | J2 | Conn_02x05_Odd_Even | Connector_Generic:Conn_02x05_Odd_Even | Connector_Molex_C-Grid:Molex_C-Grid_70246-1001_2x05_P2.54mm_Vertical | https://www.molex.com/pdm_docs/sd/702461001_sd.pdf | Digikey | WM9219-ND | Molex | 0702461001 | https://www.digikey.com/products/en?keywords=70246-1001 | 1.70
 |  | J3 | Conn_02x05_Odd_Even | Connector_Generic:Conn_02x05_Odd_Even | Connector_Molex_C-Grid:Molex_C-Grid_70246-1001_2x05_P2.54mm_Vertical | https://www.molex.com/pdm_docs/sd/702461001_sd.pdf | Digikey | WM9219-ND | Molex | 0702461001 | https://www.digikey.com/products/en?keywords=70246-1001 | 1.70
 |  | J4 | Molex_SL_01x02_Male | Connector_gkeeth:Molex_SL_01x02_Male | Connector_Molex_SL:Molex_SL_A-70543-0001_1x02_P2.54mm_Vertical | https://www.molex.com/pdm_docs/sd/705430001_sd.pdf | Digikey | WM4800-ND | Molex | 0705430001 | https://www.molex.com/pdm_docs/sd/705430001_sd.pdf | 0.84
 |  | R1 | 270 | Device:R | Resistor_SMD:R_0805_2012Metric_Pad1.15x1.40mm_HandSolder | https://www.mouser.com/datasheet/2/447/PYu-RT_1-to-0.01_RoHS_L_9-1222720.pdf | Mouser | 603-RT0805FRE07270RL | Yageo | RT0805FRE07270RL | https://www.mouser.com/ProductDetail/603-RT0805FRE07270RL | 0.12
 |  | R2 | 270 | Device:R | Resistor_SMD:R_0805_2012Metric_Pad1.15x1.40mm_HandSolder | https://www.mouser.com/datasheet/2/447/PYu-RT_1-to-0.01_RoHS_L_9-1222720.pdf | Mouser | 603-RT0805FRE07270RL | Yageo | RT0805FRE07270RL | https://www.mouser.com/ProductDetail/603-RT0805FRE07270RL | 0.12
 |  | R3 | 6.8k | Device:R | Resistor_SMD:R_0603_1608Metric_Pad1.05x0.95mm_HandSolder | http://www.yageo.com/documents/recent/PYu-RT_1-to-0.01_RoHS_L_9.pdf | Digikey | YAG5968CT-ND | Yageo | YAG5968CT-ND | https://www.digikey.com/product-detail/en/yageo/RT0603FRE076K8L/YAG5968CT-ND/9370998 | 0.10
 |  | SW1 | SW_Rotary8_CK_A125xxxxCxx | Switch_gkeeth:SW_Rotary8_CK_A125xxxxCxx | Button_Switch_THT_gkeeth:SW_Rotary8_CK_A125xxxxCxx | https://www.ckswitches.com/media/1349/arotary.pdf | Mouser | 611-A12505RNCQ | C&K | A12505RNCQ | https://www.mouser.com/ProductDetail/611-A12505RNCQ | 8.05
 |  | SW2 | SW_SPDT | Switch:SW_SPDT | Button_Switch_THT_gkeeth:SW_Toggle_SPDT_NKK_M201xxxx03 | http://www.nkkswitches.com/pdf/MtogglesBushing.pdf | Digikey | 360-1802-ND | NKK | M2012SS1W03 | https://www.digikey.com/product-detail/en/nkk-switches/M2012SS1W03/360-1802-ND/1006881 | 4.75
Collated Components:
Item | Qty | Reference(s) | Value | LibPart | Footprint | Datasheet | Distributor | Distributor PN | Manufacturer | Manufacturer PN | URL | Unit Price
1 | 1 | D1 | LED_ALT | Device:LED_ALT | LED_THT:LED_D5.0mm | http://www.kingbrightusa.com/images/catalog/SPEC/WP7113LGD.pdf | Digikey | 754-1265-ND | Kingbright | WP7113LGD | https://www.digikey.com/product-detail/en/kingbright/WP7113LGD/754-1265-ND/1747664 | 0.48
2 | 2 | J1, J4 | Molex_SL_01x02_Male | Connector_gkeeth:Molex_SL_01x02_Male | Connector_Molex_SL:Molex_SL_A-70543-0001_1x02_P2.54mm_Vertical | https://www.molex.com/pdm_docs/sd/705430001_sd.pdf | Digikey | WM4800-ND | Molex | 0705430001 | https://www.molex.com/pdm_docs/sd/705430001_sd.pdf | 0.84
3 | 2 | J2, J3 | Conn_02x05_Odd_Even | Connector_Generic:Conn_02x05_Odd_Even | Connector_Molex_C-Grid:Molex_C-Grid_70246-1001_2x05_P2.54mm_Vertical | https://www.molex.com/pdm_docs/sd/702461001_sd.pdf | Digikey | WM9219-ND | Molex | 0702461001 | https://www.digikey.com/products/en?keywords=70246-1001 | 1.70
4 | 2 | R1, R2 | 270 | Device:R | Resistor_SMD:R_0805_2012Metric_Pad1.15x1.40mm_HandSolder | https://www.mouser.com/datasheet/2/447/PYu-RT_1-to-0.01_RoHS_L_9-1222720.pdf | Mouser | 603-RT0805FRE07270RL | Yageo | RT0805FRE07270RL | https://www.mouser.com/ProductDetail/603-RT0805FRE07270RL | 0.12
5 | 1 | R3 | 6.8k | Device:R | Resistor_SMD:R_0603_1608Metric_Pad1.05x0.95mm_HandSolder | http://www.yageo.com/documents/recent/PYu-RT_1-to-0.01_RoHS_L_9.pdf | Digikey | YAG5968CT-ND | Yageo | YAG5968CT-ND | https://www.digikey.com/product-detail/en/yageo/RT0603FRE076K8L/YAG5968CT-ND/9370998 | 0.10
6 | 1 | SW1 | SW_Rotary8_CK_A125xxxxCxx | Switch_gkeeth:SW_Rotary8_CK_A125xxxxCxx | Button_Switch_THT_gkeeth:SW_Rotary8_CK_A125xxxxCxx | https://www.ckswitches.com/media/1349/arotary.pdf | Mouser | 611-A12505RNCQ | C&K | A12505RNCQ | https://www.mouser.com/ProductDetail/611-A12505RNCQ | 8.05
7 | 1 | SW2 | SW_SPDT | Switch:SW_SPDT | Button_Switch_THT_gkeeth:SW_Toggle_SPDT_NKK_M201xxxx03 | http://www.nkkswitches.com/pdf/MtogglesBushing.pdf | Digikey | 360-1802-ND | NKK | M2012SS1W03 | https://www.digikey.com/product-detail/en/nkk-switches/M2012SS1W03/360-1802-ND/1006881 | 4.75

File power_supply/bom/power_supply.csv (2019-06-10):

Source: | /home/graham/Projects/preamp-2019/power_supply/power_supply.sch
Date: | Mon 10 Jun 2019 08:08:48 AM EDT
Tool: | Eeschema 5.1.2
Generator: | /usr/share/kicad/plugins/bom_csv_grouped_by_value.py
Component Count: | 56
Individual Components:
Item | Qty | Reference(s) | Value | LibPart | Footprint | Datasheet | Distributor | Distributor PN | Manufacturer | Manufacturer PN | URL | Unit Price
 |  | C1 | 10n | Device:C | Capacitor_THT:C_Rect_L7.2mm_W2.5mm_P5.00mm_FKS2_FKP2_MKS2_MKP2 | https://www.tdk-electronics.tdk.com/inf/20/20/db/fc_2009/B32520_529.pdf | Digikey | 495-1180-ND | EPCOS | B32529C3103J000 | https://www.digikey.com/product-detail/en/B32529C3103J000/495-1180-ND/592757/?itemSeq=288794392 | 0.31
 |  | C2 | 150n | Device:C | Capacitor_THT:C_Rect_L7.5mm_W6.5mm_P5.00mm | https://www.tdk-electronics.tdk.com/inf/20/20/db/fc_2009/B32520_529.pdf | Digikey | 495-2535-ND | EPCOS | B32529C3154K000 | https://www.digikey.com/product-detail/en/B32529C3154K000/495-2535-ND/1089815/?itemSeq=288794403 | 0.63
 |  | C3 | 1000u | Device:CP1 | Capacitor_THT:CP_Radial_D12.5mm_P5.00mm | http://nichicon-us.com/english/products/pdfs/e-uhe.pdf | Digikey | 493-1621-ND | Nichicon | UHE1H102MHD | https://www.digikey.com/product-detail/en/nichicon/UHE1H102MHD/493-1621-ND/589362 | 1.47
 |  | C4 | 1000u | Device:CP1 | Capacitor_THT:CP_Radial_D12.5mm_P5.00mm | http://nichicon-us.com/english/products/pdfs/e-uhe.pdf | Digikey | 493-1621-ND | Nichicon | UHE1H102MHD | https://www.digikey.com/product-detail/en/nichicon/UHE1H102MHD/493-1621-ND/589362 | 1.47
 |  | C5 | 330n | Device:C | Capacitor_SMD:C_0805_2012Metric_Pad1.15x1.40mm_HandSolder | http://www.samsungsem.com/kr/support/product-search/mlcc/CL21B334KBFNNNE.jsp | Digikey | 1276-1123-1-ND | Samsung | CL21B334KBFNNNE | https://www.digikey.com/product-detail/en/samsung-electro-mechanics/CL21B334KBFNNNE/1276-1123-1-ND/3889209 | 0.19
 |  | C6 | 22u | Device:CP1 | Capacitor_THT:CP_Radial_D5.0mm_P2.00mm | http://nichicon-us.com/english/products/pdfs/e-uhe.pdf | Digikey | 493-1603-ND | Nichicon | UHE1H220MDD | https://www.digikey.com/product-detail/en/nichicon/UHE1H220MDD/493-1603-ND/589344 | 0.33
 |  | C7 | 100n | Device:C | Capacitor_SMD:C_0805_2012Metric_Pad1.15x1.40mm_HandSolder | ~
 |  | C8 | 1u | Device:CP1 | Capacitor_THT:CP_Radial_D4.0mm_P1.50mm | http://nichicon-us.com/english/products/pdfs/e-umt.pdf | Digikey | 493-10286-1-ND | Nichicon | UMT1H010MDD1TP | https://www.digikey.com/product-detail/en/nichicon/UMT1H010MDD1TP/493-10286-1-ND/4312545 | 0.27
 |  | C9 | 100u | Device:CP1 | Capacitor_THT:CP_Radial_D6.3mm_P2.50mm | http://nichicon-us.com/english/products/pdfs/e-uvz.pdf | Digikey | 493-13488-1-ND | Nichicon | UVZ1V101MED1TD | https://www.digikey.com/product-detail/en/nichicon/UVZ1V101MED1TD/493-13488-1-ND/4342199 | 0.33
 |  | C10 | 100u | Device:CP1 | Capacitor_THT:CP_Radial_D6.3mm_P2.50mm | http://nichicon-us.com/english/products/pdfs/e-uvz.pdf | Digikey | 493-13488-1-ND | Nichicon | UVZ1V101MED1TD | https://www.digikey.com/product-detail/en/nichicon/UVZ1V101MED1TD/493-13488-1-ND/4342199 | 0.33
 |  | C11 | 330n | Device:C | Capacitor_SMD:C_0805_2012Metric_Pad1.15x1.40mm_HandSolder | http://www.samsungsem.com/kr/support/product-search/mlcc/CL21B334KBFNNNE.jsp | Digikey | 1276-1123-1-ND | Samsung | CL21B334KBFNNNE | https://www.digikey.com/product-detail/en/samsung-electro-mechanics/CL21B334KBFNNNE/1276-1123-1-ND/3889209 | 0.19
 |  | C12 | 100n | Device:C | Capacitor_SMD:C_0805_2012Metric_Pad1.15x1.40mm_HandSolder | ~
 |  | C13 | 100u | Device:CP1 | Capacitor_THT:CP_Radial_D6.3mm_P2.50mm | http://nichicon-us.com/english/products/pdfs/e-uvz.pdf | Digikey | 493-13488-1-ND | Nichicon | UVZ1V101MED1TD | https://www.digikey.com/product-detail/en/nichicon/UVZ1V101MED1TD/493-13488-1-ND/4342199 | 0.33
 |  | D1 | MRA4004T3G | Diode:MRA4004T3G | Diode_SMD:D_SMA | http://www.onsemi.com/pub_link/Collateral/MRA4003T3-D.PDF | Digikey | MRA4004T3GOSCT-ND | On Semiconductor | MRA4004T3G | https://www.digikey.com/products/en/discrete-semiconductor-products/diodes-rectifiers-single/280?k=MRA4004T3G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 | 0.29
 |  | D2 | MRA4004T3G | Diode:MRA4004T3G | Diode_SMD:D_SMA | http://www.onsemi.com/pub_link/Collateral/MRA4003T3-D.PDF | Digikey | MRA4004T3GOSCT-ND | On Semiconductor | MRA4004T3G | https://www.digikey.com/products/en/discrete-semiconductor-products/diodes-rectifiers-single/280?k=MRA4004T3G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 | 0.29
 |  | D3 | MRA4004T3G | Diode:MRA4004T3G | Diode_SMD:D_SMA | http://www.onsemi.com/pub_link/Collateral/MRA4003T3-D.PDF | Digikey | MRA4004T3GOSCT-ND | On Semiconductor | MRA4004T3G | https://www.digikey.com/products/en/discrete-semiconductor-products/diodes-rectifiers-single/280?k=MRA4004T3G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 | 0.29
 |  | D4 | MRA4004T3G | Diode:MRA4004T3G | Diode_SMD:D_SMA | http://www.onsemi.com/pub_link/Collateral/MRA4003T3-D.PDF | Digikey | MRA4004T3GOSCT-ND | On Semiconductor | MRA4004T3G | https://www.digikey.com/products/en/discrete-semiconductor-products/diodes-rectifiers-single/280?k=MRA4004T3G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 | 0.29
 |  | D5 | MRA4004T3G | Diode:MRA4004T3G | Diode_SMD:D_SMA | http://www.onsemi.com/pub_link/Collateral/MRA4003T3-D.PDF | Digikey | MRA4004T3GOSCT-ND | On Semiconductor | MRA4004T3G | https://www.digikey.com/products/en/discrete-semiconductor-products/diodes-rectifiers-single/280?k=MRA4004T3G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 | 0.29
 |  | D6 | MRA4004T3G | Diode:MRA4004T3G | Diode_SMD:D_SMA | http://www.onsemi.com/pub_link/Collateral/MRA4003T3-D.PDF | Digikey | MRA4004T3GOSCT-ND | On Semiconductor | MRA4004T3G | https://www.digikey.com/products/en/discrete-semiconductor-products/diodes-rectifiers-single/280?k=MRA4004T3G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 | 0.29
 |  | D7 | MRA4004T3G | Diode:MRA4004T3G | Diode_SMD:D_SMA | http://www.onsemi.com/pub_link/Collateral/MRA4003T3-D.PDF | Digikey | MRA4004T3GOSCT-ND | On Semiconductor | MRA4004T3G | https://www.digikey.com/products/en/discrete-semiconductor-products/diodes-rectifiers-single/280?k=MRA4004T3G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 | 0.29
 |  | D8 | MRA4004T3G | Diode:MRA4004T3G | Diode_SMD:D_SMA | http://www.onsemi.com/pub_link/Collateral/MRA4003T3-D.PDF | Digikey | MRA4004T3GOSCT-ND | On Semiconductor | MRA4004T3G | https://www.digikey.com/products/en/discrete-semiconductor-products/diodes-rectifiers-single/280?k=MRA4004T3G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 | 0.29
 |  | D9 | LED | Device:LED_ALT | LED_SMD:LED_0603_1608Metric | http://optoelectronics.liteon.com/upload/download/DS22-2000-223/LTST-C191KRKT.PDF | Digikey | 160-1447-1-ND | Lite-On | LTST-C191KRKT | https://www.digikey.com/product-detail/en/lite-on-inc/LTST-C191KRKT/160-1447-1-ND/386836 | 0.29
 |  | D10 | LED | Device:LED_ALT | LED_SMD:LED_0603_1608Metric | http://optoelectronics.liteon.com/upload/download/DS22-2000-223/LTST-C191KRKT.PDF | Digikey | 160-1447-1-ND | Lite-On | LTST-C191KRKT | https://www.digikey.com/product-detail/en/lite-on-inc/LTST-C191KRKT/160-1447-1-ND/386836 | 0.29
 |  | D11 | MRA4004T3G | Diode:MRA4004T3G | Diode_SMD:D_SMA | http://www.onsemi.com/pub_link/Collateral/MRA4003T3-D.PDF | Digikey | MRA4004T3GOSCT-ND | On Semiconductor | MRA4004T3G | https://www.digikey.com/products/en/discrete-semiconductor-products/diodes-rectifiers-single/280?k=MRA4004T3G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 | 0.29
 |  | D12 | MRA4004T3G | Diode:MRA4004T3G | Diode_SMD:D_SMA | http://www.onsemi.com/pub_link/Collateral/MRA4003T3-D.PDF | Digikey | MRA4004T3GOSCT-ND | On Semiconductor | MRA4004T3G | https://www.digikey.com/products/en/discrete-semiconductor-products/diodes-rectifiers-single/280?k=MRA4004T3G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 | 0.29
 |  | F1 | 300mA | Device:Fuse | Fuse:Fuseholder_Cylinder-5x20mm_Schurter_0031_8201_Horizontal_Open | ~
 |  | F2 | 300mA | Device:Fuse | Fuse:Fuseholder_Cylinder-5x20mm_Schurter_0031_8201_Horizontal_Open | ~
 |  | H1 | MountingHole_Pad | Mechanical:MountingHole_Pad | MountingHole:MountingHole_4.5mm_Pad | ~
 |  | H2 | MountingHole_Pad | Mechanical:MountingHole_Pad | MountingHole:MountingHole_4.5mm_Pad | ~
 |  | H3 | MountingHole_Pad | Mechanical:MountingHole_Pad | MountingHole:MountingHole_4.5mm_Pad | ~
 |  | H4 | MountingHole_Pad | Mechanical:MountingHole_Pad | MountingHole:MountingHole_4.5mm_Pad | ~
 |  | HS1 | Wakefield-Vette 287-1AB | Mechanical:Heatsink_Pad | Heatsink_gkeeth:Heatsink_Wakefield-Vette_287-1AB_T0-220_Vertical | ~
 |  | HS2 | Wakefield-Vette 287-1AB | Mechanical:Heatsink_Pad | Heatsink_gkeeth:Heatsink_Wakefield-Vette_287-1AB_T0-220_Vertical | ~
 |  | HS3 | Wakefield-Vette 287-1AB | Mechanical:Heatsink_Pad | Heatsink_gkeeth:Heatsink_Wakefield-Vette_287-1AB_T0-220_Vertical | ~
 |  | J1 | Conn_01x04_Male | Connector:Conn_01x04_Male | Connector_Molex_KK-396:Molex_KK-396_A-41791-0004_1x04_P3.96mm_Vertical | ~
 |  | J2 | Conn_01x03_Male | Connector:Conn_01x03_Male | Connector_Molex_SL:Molex_SL_A-70543-0002_1x03_P2.54mm_Vertical | ~
 |  | J3 | Conn_01x03_Male | Connector:Conn_01x03_Male | Connector_Molex_SL:Molex_SL_A-70543-0002_1x03_P2.54mm_Vertical | ~
 |  | J4 | Conn_01x03_Male | Connector:Conn_01x03_Male | Connector_Molex_SL:Molex_SL_A-70543-0002_1x03_P2.54mm_Vertical | ~
 |  | J5 | Conn_01x02_Male | Connector:Conn_01x02_Male | Connector_Molex_SL:Molex_SL_A-70543-0001_1x02_P2.54mm_Vertical | ~
 |  | J6 | Conn_01x02_Male | Connector:Conn_01x02_Male | Connector_Molex_SL:Molex_SL_A-70543-0001_1x02_P2.54mm_Vertical | ~
 |  | JP1 | Jumper_NC_Small | Device:Jumper_NC_Small | Connector_PinHeader_2.54mm:PinHeader_1x02_P2.54mm_Vertical | ~
 |  | JP2 | Jumper_NC_Small | Device:Jumper_NC_Small | Connector_PinHeader_2.54mm:PinHeader_1x02_P2.54mm_Vertical | ~
 |  | JP3 | Jumper_NC_Small | Device:Jumper_NC_Small | Connector_PinHeader_2.54mm:PinHeader_1x02_P2.54mm_Vertical | ~
 |  | JP4 | Jumper_NC_Small | Device:Jumper_NC_Small | Connector_PinHeader_2.54mm:PinHeader_1x02_P2.54mm_Vertical | ~
 |  | JP5 | Jumper_NC_Small | Device:Jumper_NC_Small | Connector_PinHeader_2.54mm:PinHeader_1x02_P2.54mm_Vertical | ~
 |  | JP6 | Jumper_NC_Small | Device:Jumper_NC_Small | Connector_PinHeader_2.54mm:PinHeader_1x02_P2.54mm_Vertical | ~
 |  | R1 | 100 | Device:R | Resistor_SMD:R_1206_3216Metric_Pad1.42x1.75mm_HandSolder | ~
 |  | R2 | 10k | Device:R | Resistor_SMD:R_0603_1608Metric_Pad1.05x0.95mm_HandSolder | ~
 |  | R3 | 10k | Device:R | Resistor_SMD:R_0603_1608Metric_Pad1.05x0.95mm_HandSolder | ~
 |  | R4 | 100k | Device:R | Capacitor_SMD:C_0603_1608Metric_Pad1.05x0.95mm_HandSolder | ~
 |  | R5 | 100k | Device:R | Capacitor_SMD:C_0603_1608Metric_Pad1.05x0.95mm_HandSolder | ~
 |  | R6 | 100k | Device:R | Capacitor_SMD:C_0603_1608Metric_Pad1.05x0.95mm_HandSolder | ~
 |  | R7 | 1k | Device:R | Resistor_SMD:R_0603_1608Metric_Pad1.05x0.95mm_HandSolder | ~
 |  | U1 | LM7815_TO220 | Regulator_Linear:LM7815_TO220 | Package_TO_SOT_THT:TO-220-3_Vertical | http://www.fairchildsemi.com/ds/LM/LM7805.pdf
 |  | U2 | LM7915_TO220 | Regulator_Linear:LM7915_TO220 | Package_TO_SOT_THT:TO-220-3_Vertical | http://www.fairchildsemi.com/ds/LM/LM7905.pdf
 |  | U3 | LM7815_TO220 | Regulator_Linear:LM7815_TO220 | Package_TO_SOT_THT:TO-220-3_Vertical | http://www.fairchildsemi.com/ds/LM/LM7805.pdf
Collated Components:
Item | Qty | Reference(s) | Value | LibPart | Footprint | Datasheet | Distributor | Distributor PN | Manufacturer | Manufacturer PN | URL | Unit Price
1 | 1 | C1 | 10n | Device:C | Capacitor_THT:C_Rect_L7.2mm_W2.5mm_P5.00mm_FKS2_FKP2_MKS2_MKP2 | https://www.tdk-electronics.tdk.com/inf/20/20/db/fc_2009/B32520_529.pdf | Digikey | 495-1180-ND | EPCOS | B32529C3103J000 | https://www.digikey.com/product-detail/en/B32529C3103J000/495-1180-ND/592757/?itemSeq=288794392 | 0.31
2 | 1 | C2 | 150n | Device:C | Capacitor_THT:C_Rect_L7.5mm_W6.5mm_P5.00mm | https://www.tdk-electronics.tdk.com/inf/20/20/db/fc_2009/B32520_529.pdf | Digikey | 495-2535-ND | EPCOS | B32529C3154K000 | https://www.digikey.com/product-detail/en/B32529C3154K000/495-2535-ND/1089815/?itemSeq=288794403 | 0.63
3 | 2 | C3, C4 | 1000u | Device:CP1 | Capacitor_THT:CP_Radial_D12.5mm_P5.00mm | http://nichicon-us.com/english/products/pdfs/e-uhe.pdf | Digikey | 493-1621-ND | Nichicon | UHE1H102MHD | https://www.digikey.com/product-detail/en/nichicon/UHE1H102MHD/493-1621-ND/589362 | 1.47
4 | 2 | C5, C11 | 330n | Device:C | Capacitor_SMD:C_0805_2012Metric_Pad1.15x1.40mm_HandSolder | http://www.samsungsem.com/kr/support/product-search/mlcc/CL21B334KBFNNNE.jsp | Digikey | 1276-1123-1-ND | Samsung | CL21B334KBFNNNE | https://www.digikey.com/product-detail/en/samsung-electro-mechanics/CL21B334KBFNNNE/1276-1123-1-ND/3889209 | 0.19
5 | 1 | C6 | 22u | Device:CP1 | Capacitor_THT:CP_Radial_D5.0mm_P2.00mm | http://nichicon-us.com/english/products/pdfs/e-uhe.pdf | Digikey | 493-1603-ND | Nichicon | UHE1H220MDD | https://www.digikey.com/product-detail/en/nichicon/UHE1H220MDD/493-1603-ND/589344 | 0.33
6 | 2 | C7, C12 | 100n | Device:C | Capacitor_SMD:C_0805_2012Metric_Pad1.15x1.40mm_HandSolder | ~
7 | 1 | C8 | 1u | Device:CP1 | Capacitor_THT:CP_Radial_D4.0mm_P1.50mm | http://nichicon-us.com/english/products/pdfs/e-umt.pdf | Digikey | 493-10286-1-ND | Nichicon | UMT1H010MDD1TP | https://www.digikey.com/product-detail/en/nichicon/UMT1H010MDD1TP/493-10286-1-ND/4312545 | 0.27
8 | 3 | C9, C10, C13 | 100u | Device:CP1 | Capacitor_THT:CP_Radial_D6.3mm_P2.50mm | http://nichicon-us.com/english/products/pdfs/e-uvz.pdf | Digikey | 493-13488-1-ND | Nichicon | UVZ1V101MED1TD | https://www.digikey.com/product-detail/en/nichicon/UVZ1V101MED1TD/493-13488-1-ND/4342199 | 0.33
9 | 10 | D1, D2, D3, D4, D5, D6, D7, D8, D11, D12 | MRA4004T3G | Diode:MRA4004T3G | Diode_SMD:D_SMA | http://www.onsemi.com/pub_link/Collateral/MRA4003T3-D.PDF | Digikey | MRA4004T3GOSCT-ND | On Semiconductor | MRA4004T3G | https://www.digikey.com/products/en/discrete-semiconductor-products/diodes-rectifiers-single/280?k=MRA4004T3G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 | 0.29
10 | 2 | D9, D10 | LED | Device:LED_ALT | LED_SMD:LED_0603_1608Metric | http://optoelectronics.liteon.com/upload/download/DS22-2000-223/LTST-C191KRKT.PDF | Digikey | 160-1447-1-ND | Lite-On | LTST-C191KRKT | https://www.digikey.com/product-detail/en/lite-on-inc/LTST-C191KRKT/160-1447-1-ND/386836 | 0.29
11 | 2 | F1, F2 | 300mA | Device:Fuse | Fuse:Fuseholder_Cylinder-5x20mm_Schurter_0031_8201_Horizontal_Open | ~
12 | 4 | H1, H2, H3, H4 | MountingHole_Pad | Mechanical:MountingHole_Pad | MountingHole:MountingHole_4.5mm_Pad | ~
13 | 3 | HS1, HS2, HS3 | Wakefield-Vette 287-1AB | Mechanical:Heatsink_Pad | Heatsink_gkeeth:Heatsink_Wakefield-Vette_287-1AB_T0-220_Vertical | ~
14 | 1 | J1 | Conn_01x04_Male | Connector:Conn_01x04_Male | Connector_Molex_KK-396:Molex_KK-396_A-41791-0004_1x04_P3.96mm_Vertical | ~
15 | 3 | J2, J3, J4 | Conn_01x03_Male | Connector:Conn_01x03_Male | Connector_Molex_SL:Molex_SL_A-70543-0002_1x03_P2.54mm_Vertical | ~
16 | 2 | J5, J6 | Conn_01x02_Male | Connector:Conn_01x02_Male | Connector_Molex_SL:Molex_SL_A-70543-0001_1x02_P2.54mm_Vertical | ~
17 | 6 | JP1, JP2, JP3, JP4, JP5, JP6 | Jumper_NC_Small | Device:Jumper_NC_Small | Connector_PinHeader_2.54mm:PinHeader_1x02_P2.54mm_Vertical | ~
18 | 1 | R1 | 100 | Device:R | Resistor_SMD:R_1206_3216Metric_Pad1.42x1.75mm_HandSolder | ~
19 | 2 | R2, R3 | 10k | Device:R | Resistor_SMD:R_0603_1608Metric_Pad1.05x0.95mm_HandSolder | ~
20 | 3 | R4, R5, R6 | 100k | Device:R | Capacitor_SMD:C_0603_1608Metric_Pad1.05x0.95mm_HandSolder | ~
21 | 1 | R7 | 1k | Device:R | Resistor_SMD:R_0603_1608Metric_Pad1.05x0.95mm_HandSolder | ~
22 | 2 | U1, U3 | LM7815_TO220 | Regulator_Linear:LM7815_TO220 | Package_TO_SOT_THT:TO-220-3_Vertical | http://www.fairchildsemi.com/ds/LM/LM7805.pdf
23 | 1 | U2 | LM7915_TO220 | Regulator_Linear:LM7915_TO220 | Package_TO_SOT_THT:TO-220-3_Vertical | http://www.fairchildsemi.com/ds/LM/LM7905.pdf

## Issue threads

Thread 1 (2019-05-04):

Doug Self Preamp

forart, 2019-05-04:
Hi there, sorry for the "issue" bu I don't know how to keep in touch with you.

This project is really interesting, even if - to me - would be great to have a tube-enabled preamp (such as [Freya by Sciit](https://www.schiit.com/products/freya))...

I do also suggest you to keep an eye on [Doug Self Preamp from Linear Audio #5](https://www.diyaudio.com/forums/analog-line-level/280458-doug-self-preamp-linear-audio-5-a.html) 3AD @ diyAudio to obtain more hints on build.

Last but not least, consider an adequate open license for your work.

Marco

gkeeth, 2019-06-06:
Hi Marco,

Thanks for reaching out! I'm really sorry it took me so long to get back to you.

Thanks for the link. I'm reading through the thread and will keep an eye out for construction ideas.

Thanks for the prodding on licensing! I planned to release it with an open source license but hadn't decided on which license to use, until you brought it up. I just decided on a CC-BY-SA license and will update the project accordingly.

Closed 2019-09-22.

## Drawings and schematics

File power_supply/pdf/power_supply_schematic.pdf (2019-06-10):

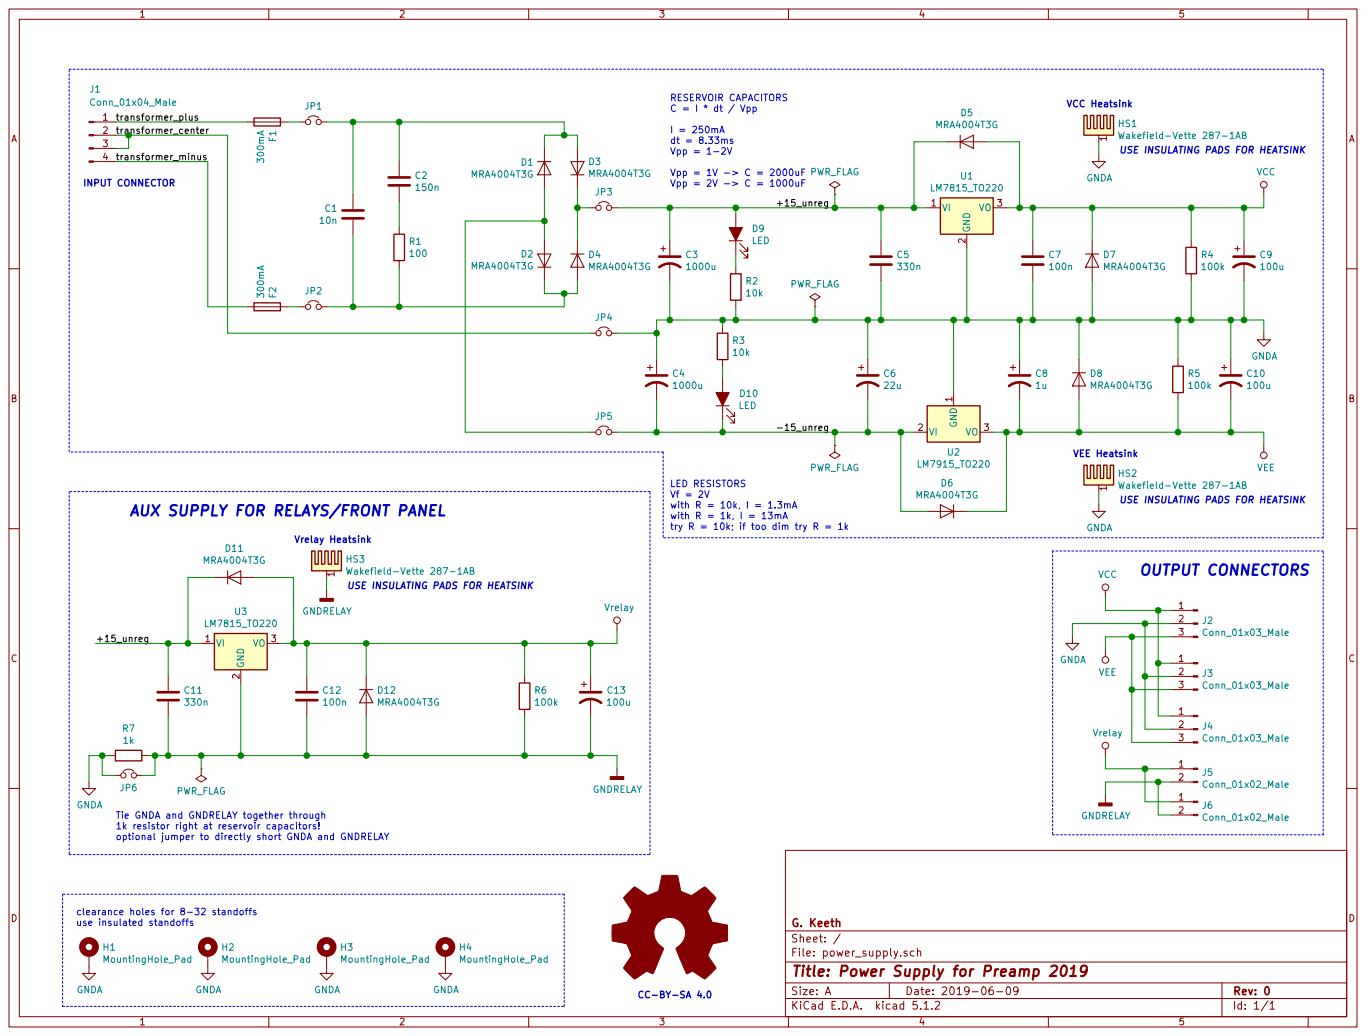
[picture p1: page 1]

RESERVOIR CAPACITORS C = I * dt / Vpp
-15_unregPWR_FLAG

VCC Heatsink VEE Heatsink Vrelay Heatsink

USE INSULATING PADS FOR HEATSINK

J5Conn_01x02_Male AUX SUPPLY FOR RELAYS/FRONT PANEL

optional jumper to directly short GNDA and GNDRELAY R7

Tie GNDA and GNDRELAY together through
1k resistor right at reservoir capacitors!

clearance holes for 8-32 standoffs use insulated standoffs

File: power_supply.sch Sheet: / G. Keeth

Id: 1/1 Title: Power Supply for Preamp 2019

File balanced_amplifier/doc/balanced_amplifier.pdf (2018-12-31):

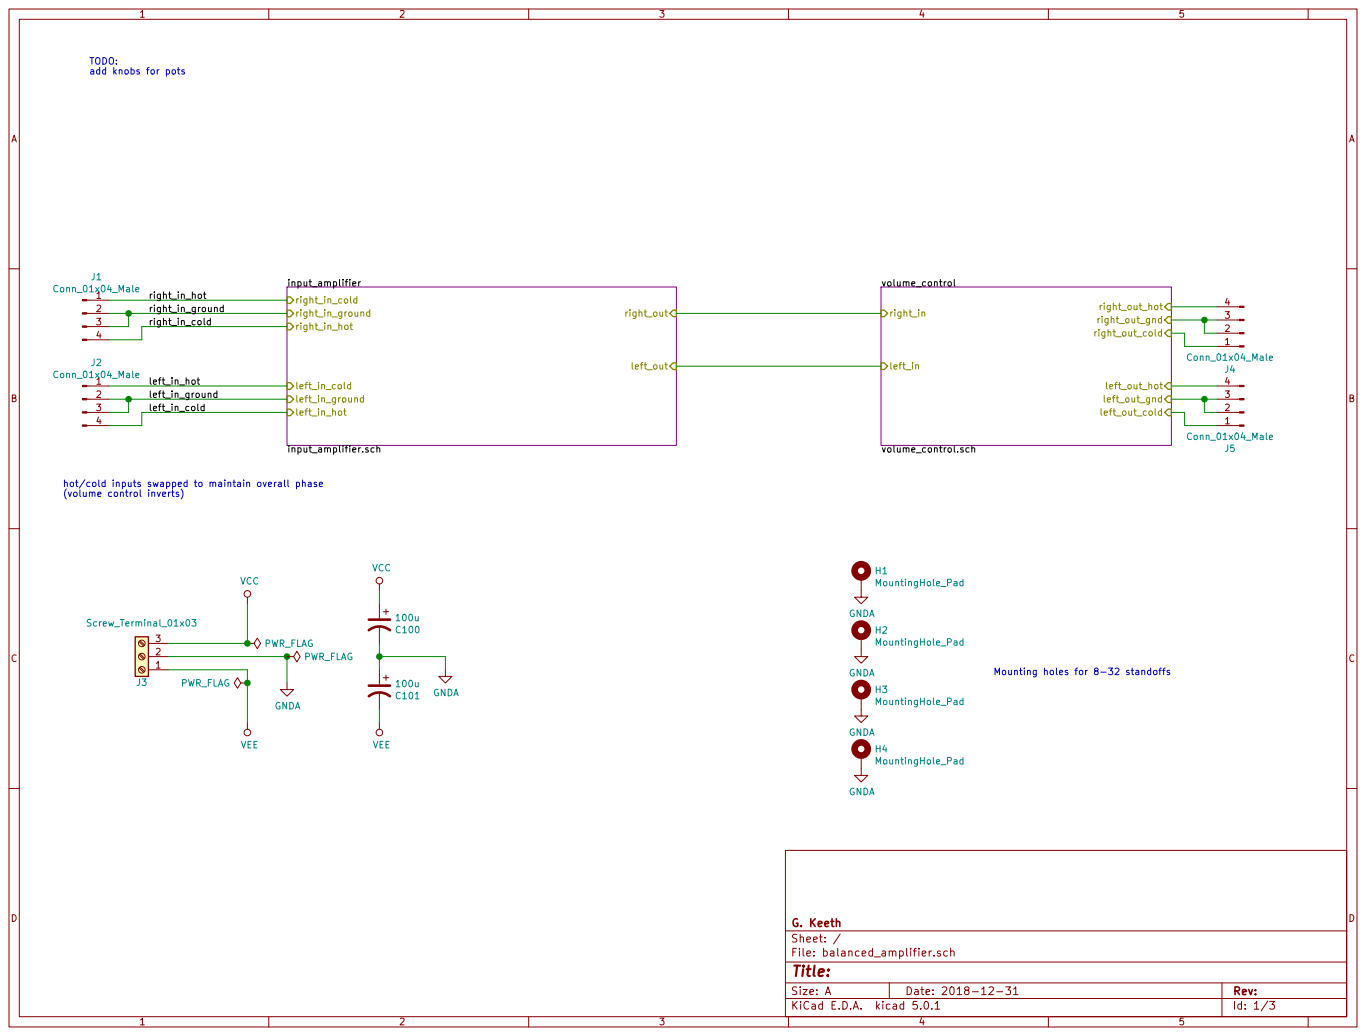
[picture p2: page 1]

TODO: add knobs for pots

hot/cold inputs swapped to maintain overall phase

File: balanced_amplifier.sch Sheet: / G. Keeth

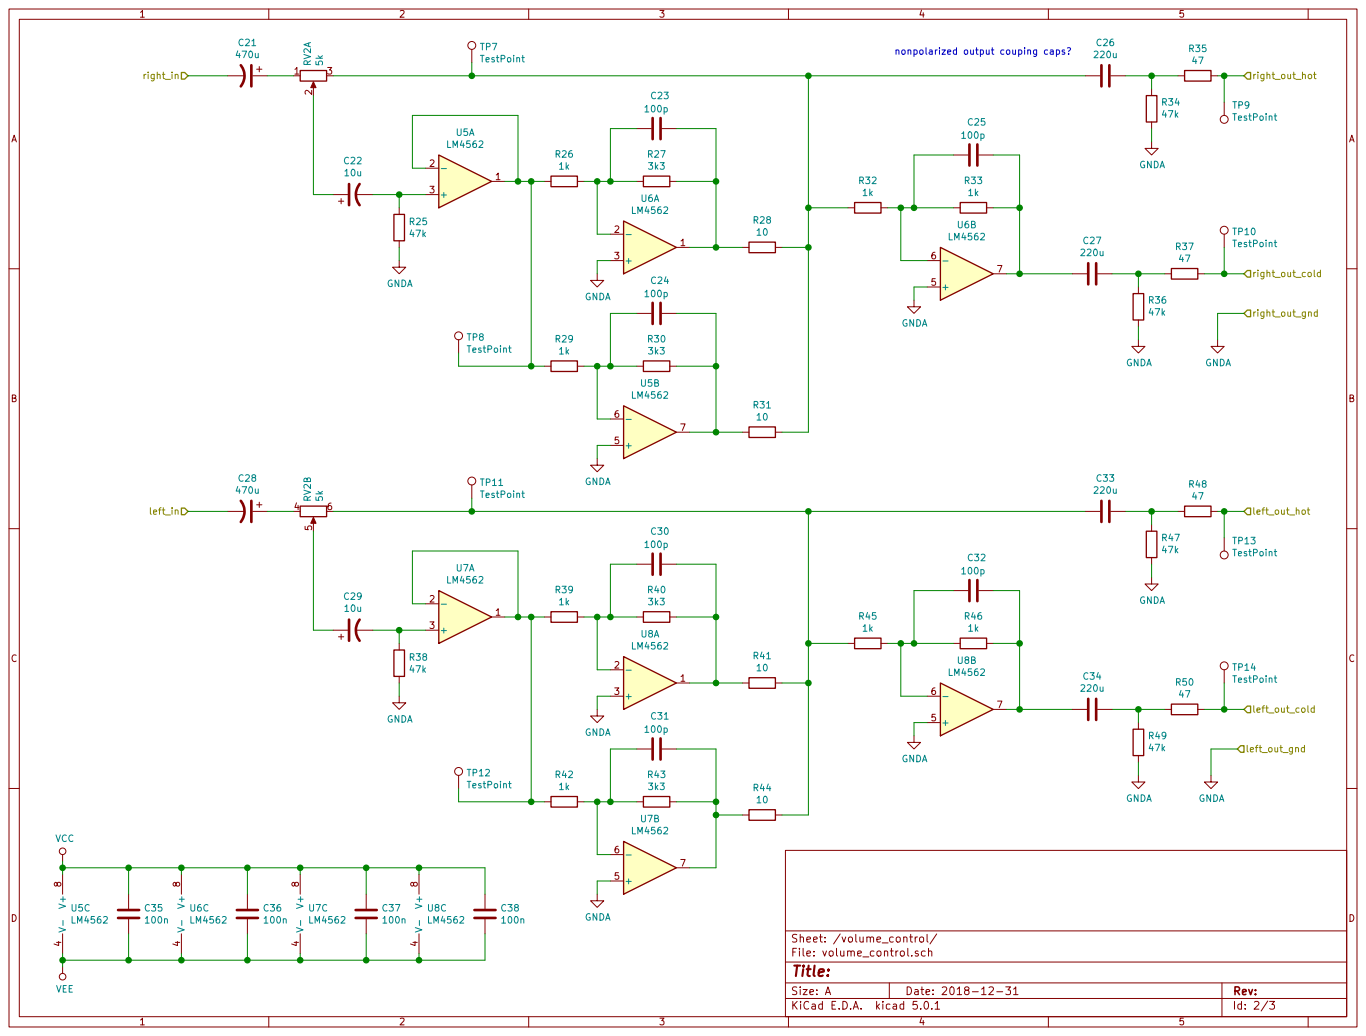
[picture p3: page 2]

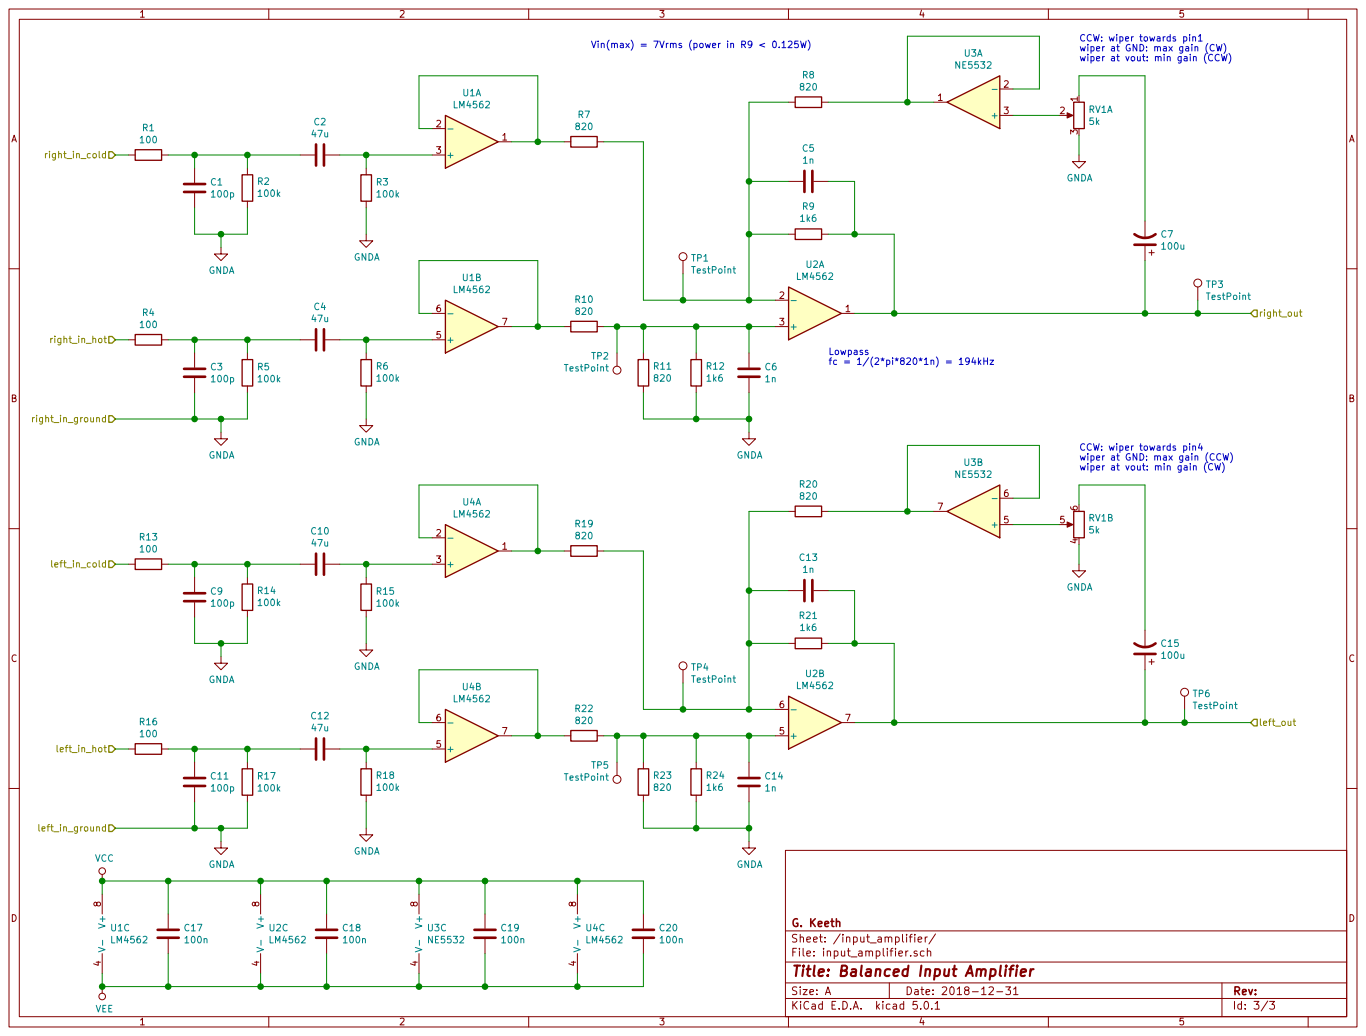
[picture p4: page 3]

TP1 TestPoint TP4 TestPoint TP2 TestPoint TP5 TestPoint

CCW: wiper towards pin1
wiper at GND: max gain (CW)
wiper at vout: min gain (CCW) GNDA CCW: wiper towards pin4

wiper at GND: max gain (CCW)
wiper at vout: min gain (CW) GNDA

File: input_amplifier.sch
Id: 3/3 Title: Balanced Input Amplifier

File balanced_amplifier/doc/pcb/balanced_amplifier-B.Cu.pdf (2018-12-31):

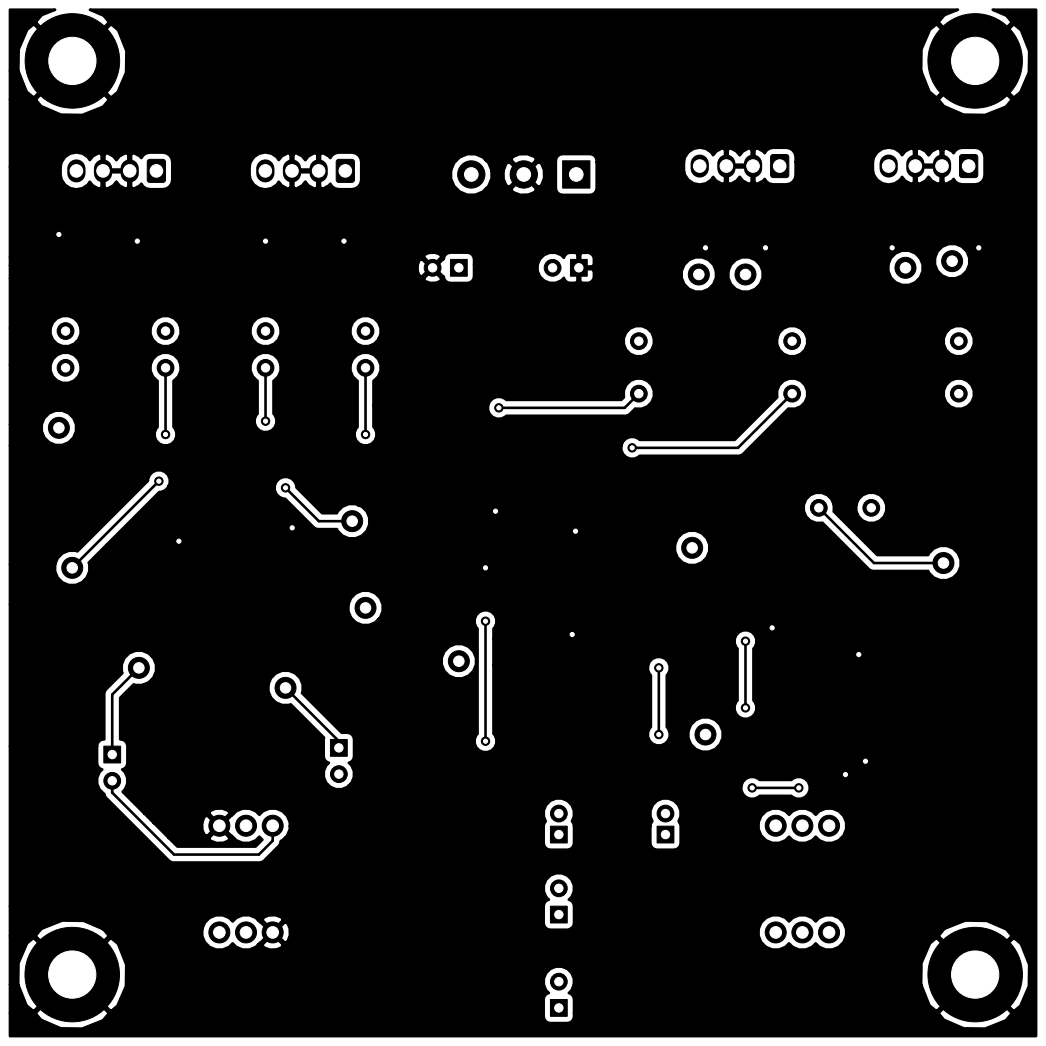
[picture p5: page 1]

File: balanced_amplifier.kicad_pcb Sheet:
Id: 1/1 Title: preamp-2019: Balanced Amplifier board

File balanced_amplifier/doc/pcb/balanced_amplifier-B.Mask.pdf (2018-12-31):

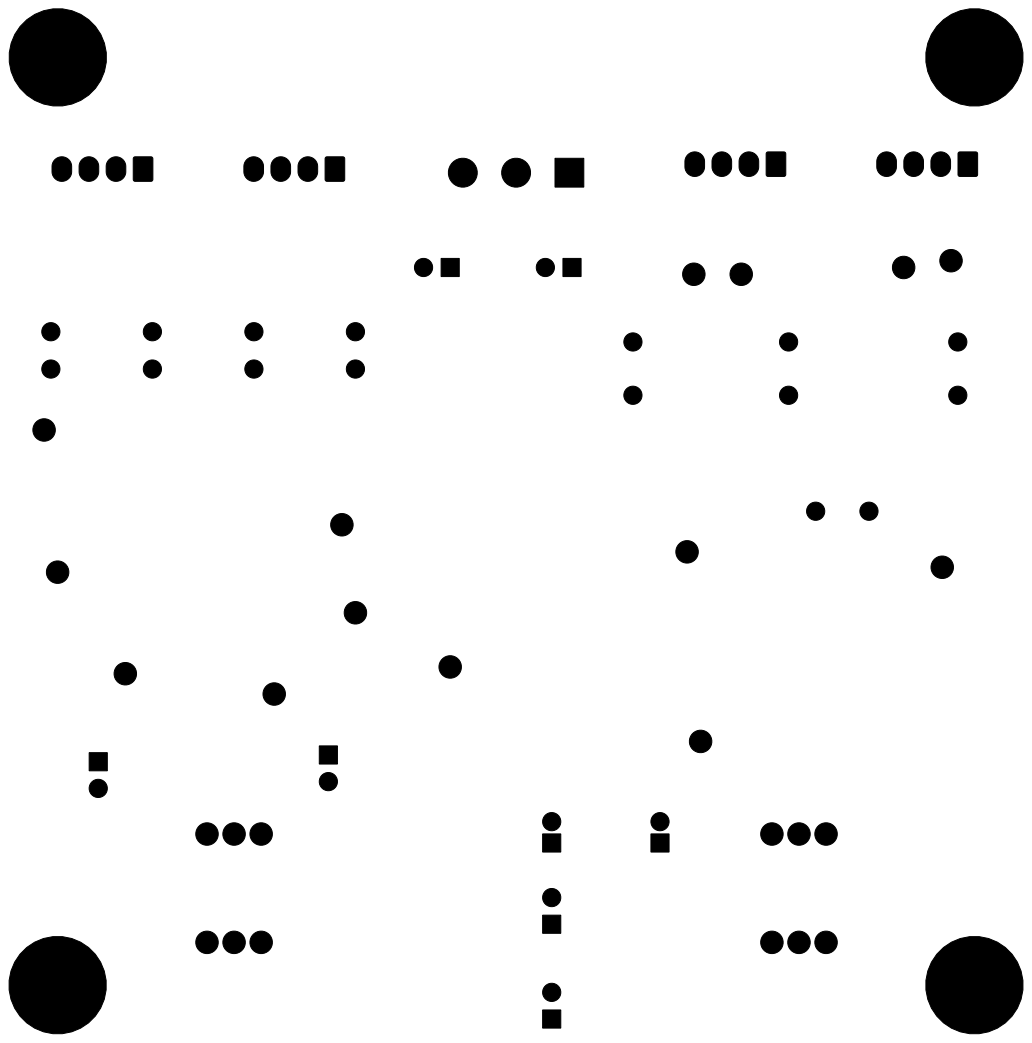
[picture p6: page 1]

File: balanced_amplifier.kicad_pcb Sheet:
Id: 1/1 Title: preamp-2019: Balanced Amplifier board

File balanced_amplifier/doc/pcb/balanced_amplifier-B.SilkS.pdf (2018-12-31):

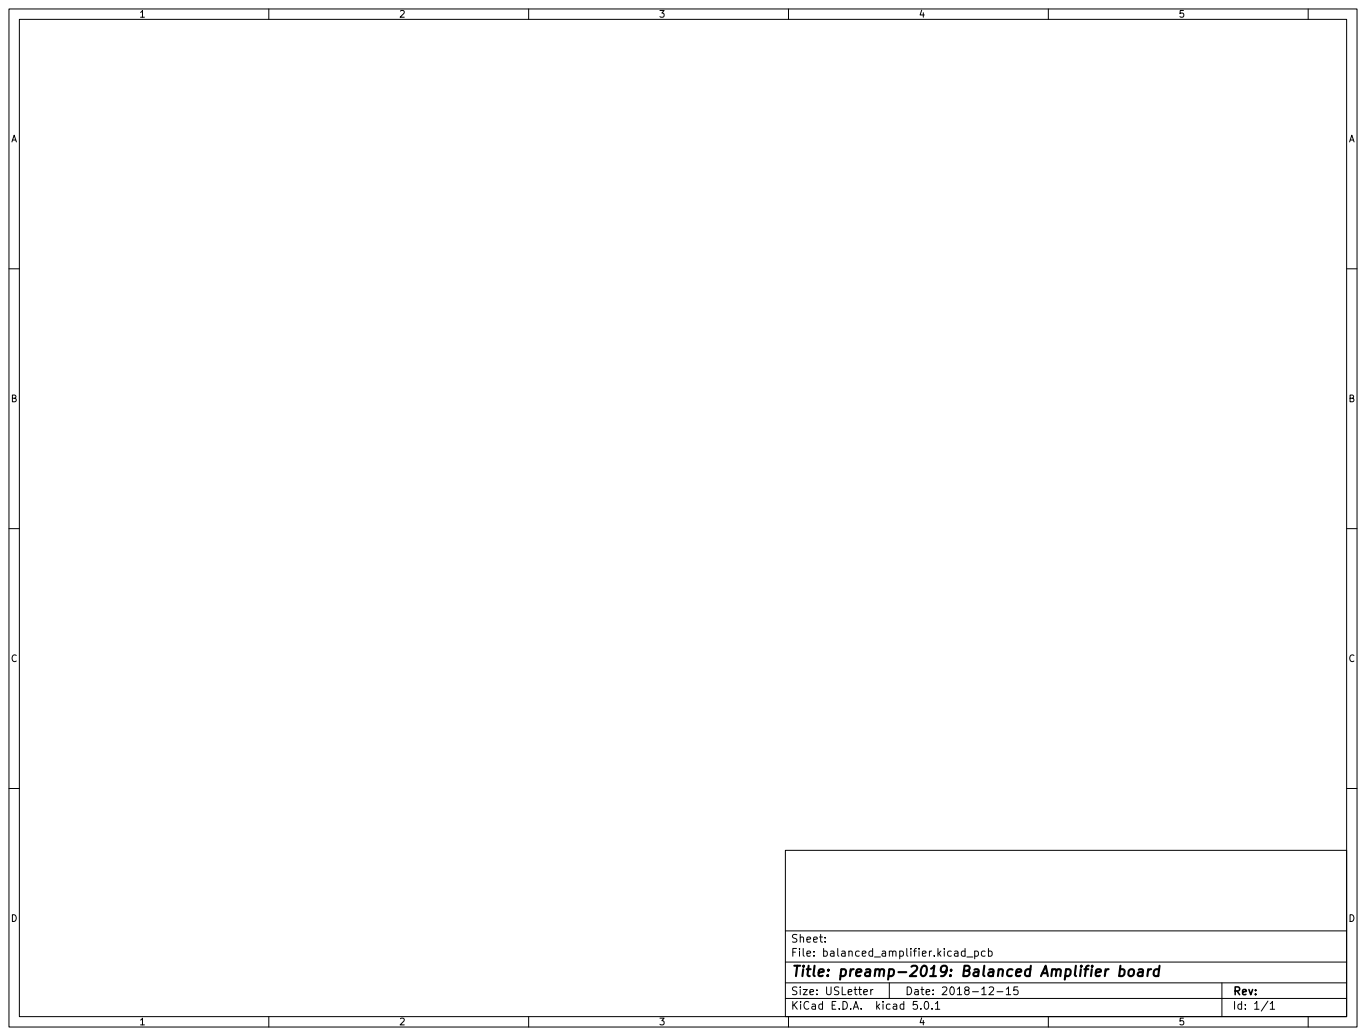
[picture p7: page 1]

File: balanced_amplifier.kicad_pcb Sheet:
Id: 1/1 Title: preamp-2019: Balanced Amplifier board

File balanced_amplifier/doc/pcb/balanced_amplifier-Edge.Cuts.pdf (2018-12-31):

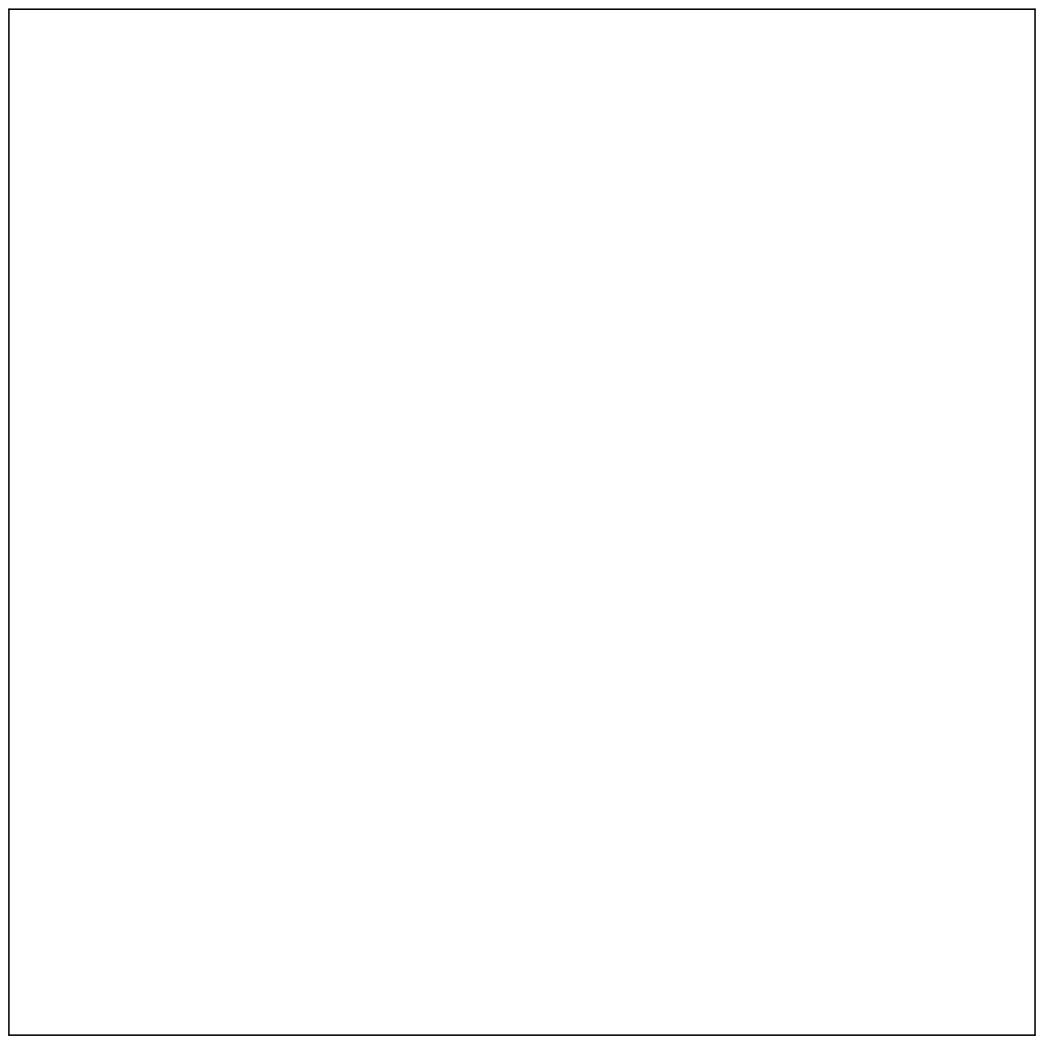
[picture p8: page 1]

File: balanced_amplifier.kicad_pcb Sheet:
Id: 1/1 Title: preamp-2019: Balanced Amplifier board

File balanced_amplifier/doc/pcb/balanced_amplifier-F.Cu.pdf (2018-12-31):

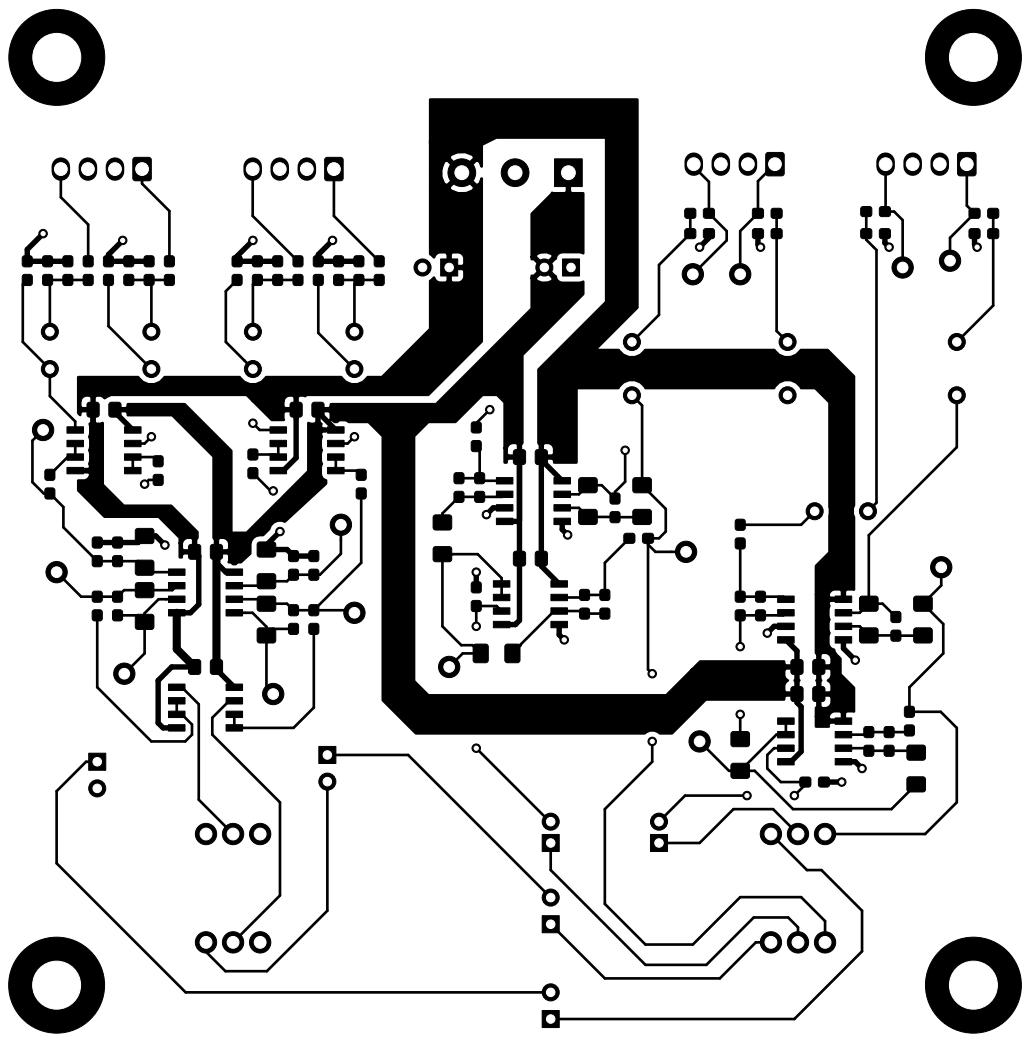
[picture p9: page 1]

File: balanced_amplifier.kicad_pcb Sheet:
Id: 1/1 Title: preamp-2019: Balanced Amplifier board

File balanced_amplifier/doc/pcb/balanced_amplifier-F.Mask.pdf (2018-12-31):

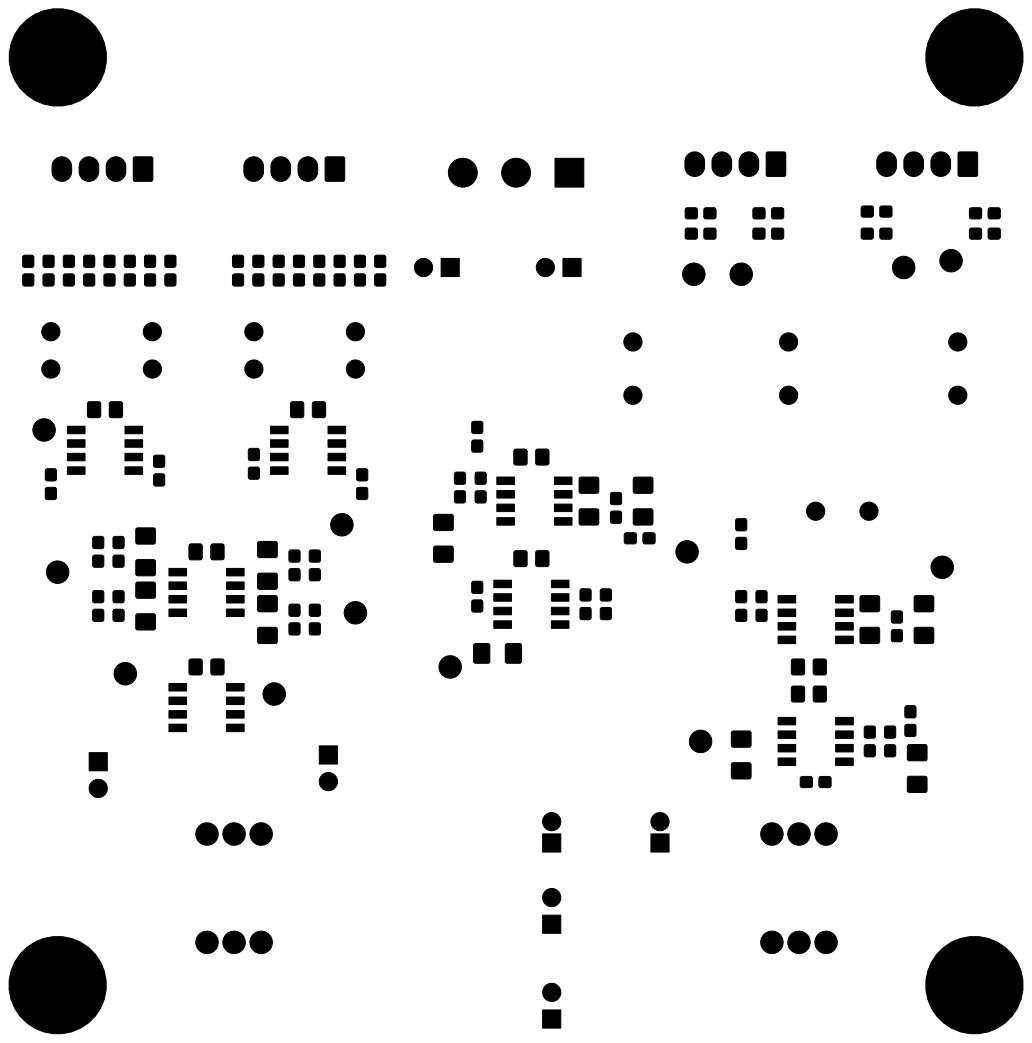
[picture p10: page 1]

File: balanced_amplifier.kicad_pcb Sheet:
Id: 1/1 Title: preamp-2019: Balanced Amplifier board

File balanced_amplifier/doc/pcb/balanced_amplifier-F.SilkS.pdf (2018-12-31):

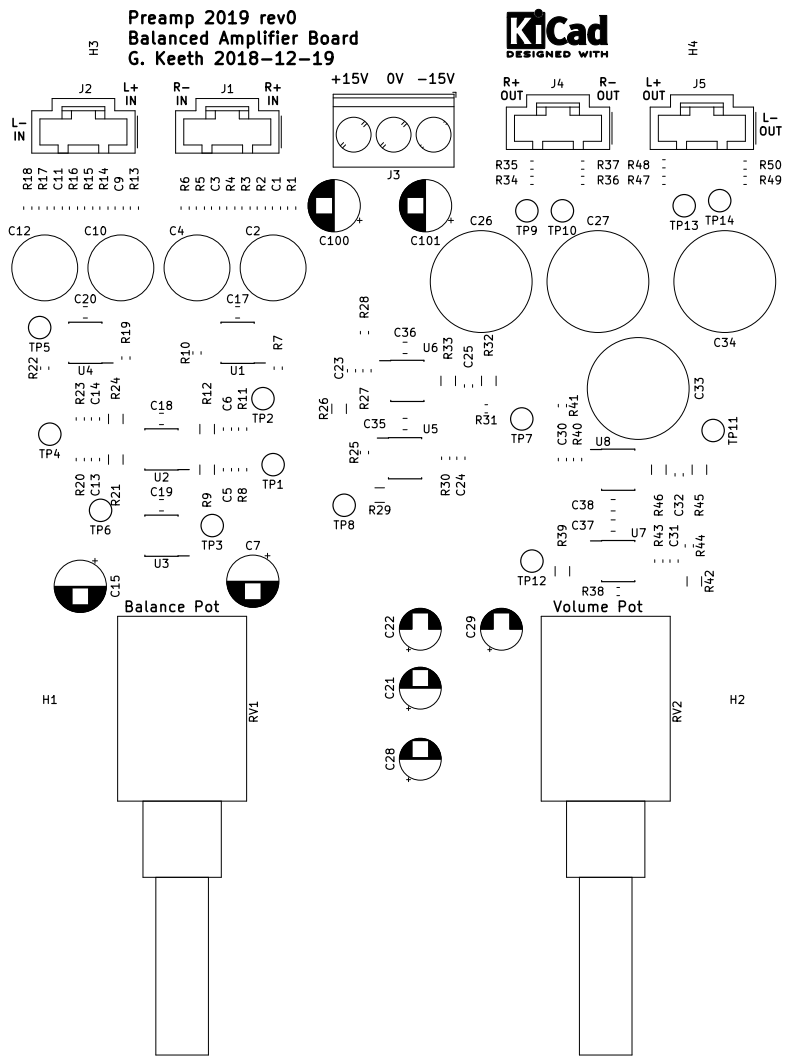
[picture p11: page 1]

Id: 1/1 Title: preamp-2019: Balanced Amplifier board

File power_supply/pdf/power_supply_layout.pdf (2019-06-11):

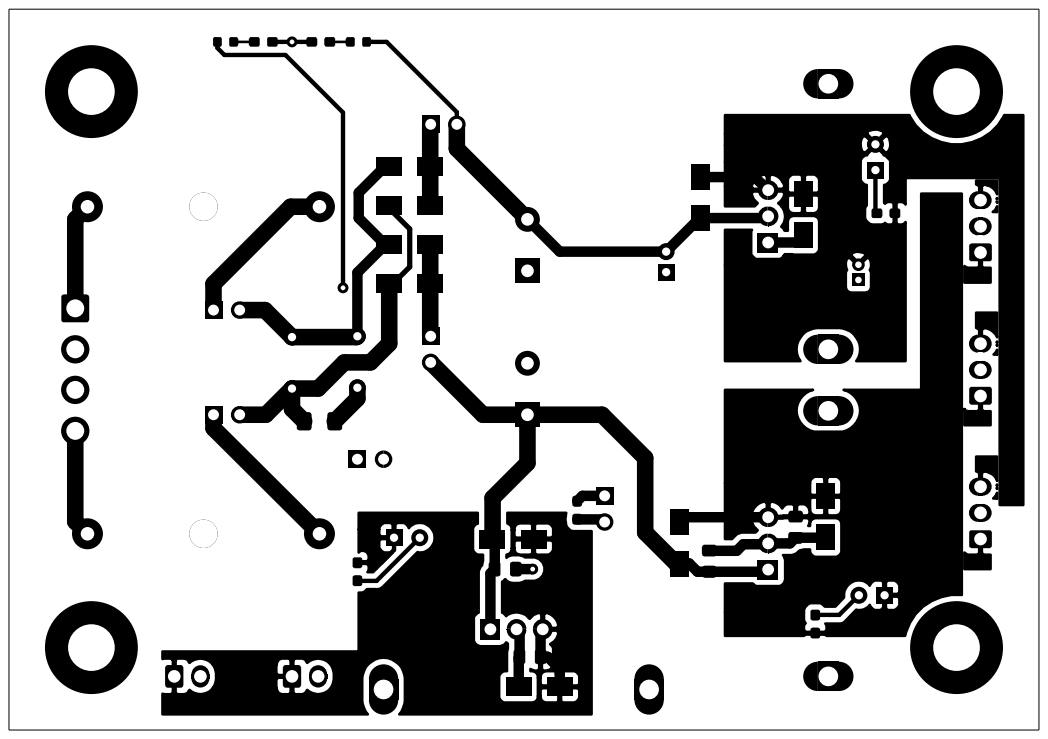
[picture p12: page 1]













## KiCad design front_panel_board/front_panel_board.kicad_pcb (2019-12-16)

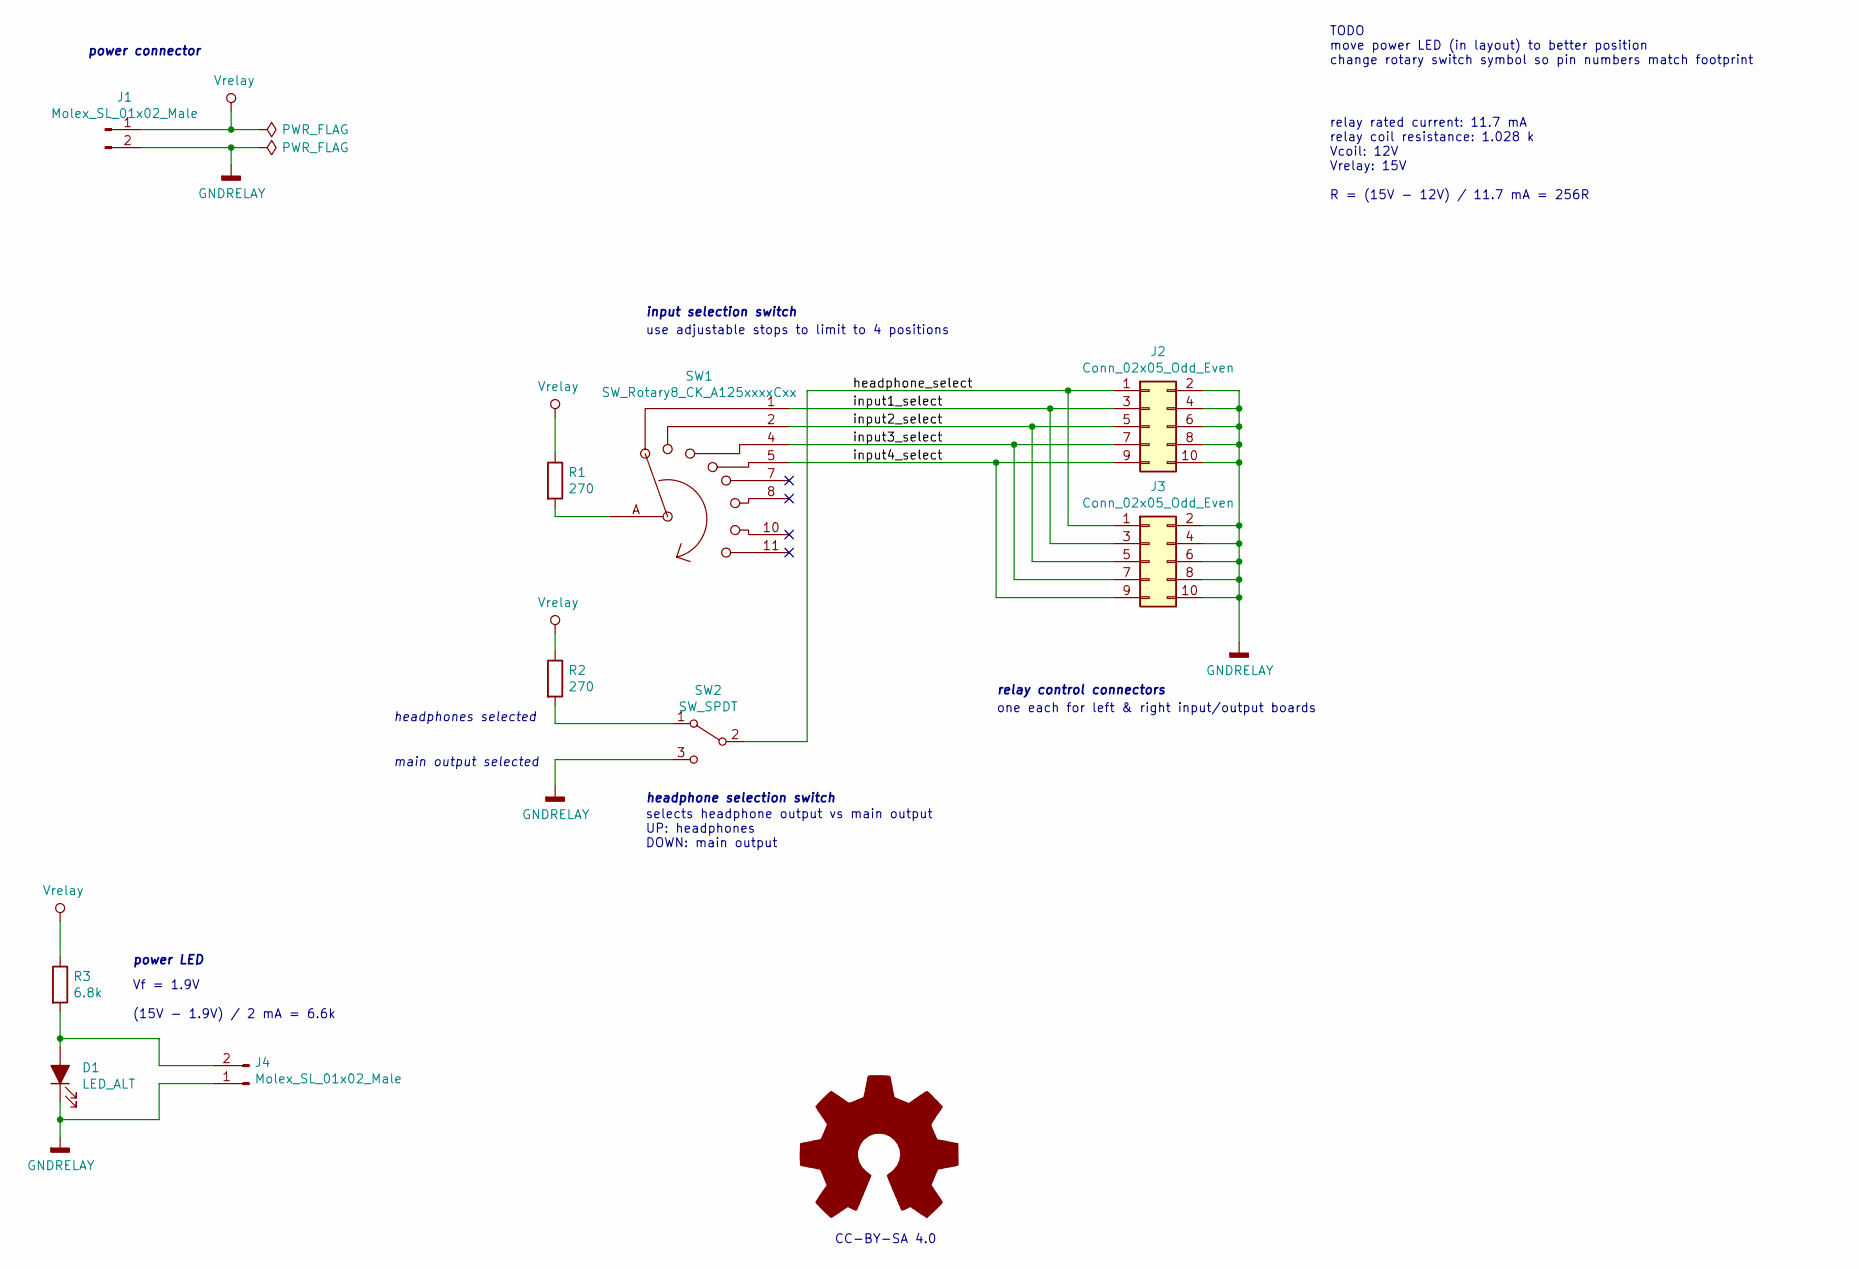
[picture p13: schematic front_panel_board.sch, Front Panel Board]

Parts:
D1: LED_ALT; LED_D5.0mm; Manufacturer PN WP7113LGD
J1, J4: Molex_SL_01x02_Male; Molex_SL_A-70543-0001_1x02_P2.54mm_Vertical; Manufacturer PN 0705430001
J2, J3: Conn_02x05_Odd_Even; Molex_C-Grid_70246-1001_2x05_P2.54mm_Vertical; Manufacturer PN 0702461001
R1, R2: 270; R_0805_2012Metric_Pad1.15x1.40mm_HandSolder; Manufacturer PN RT0805FRE07270RL
R3: 6.8k; R_0603_1608Metric_Pad1.05x0.95mm_HandSolder; Manufacturer PN YAG5968CT-ND
SW1: SW_Rotary8_CK_A125xxxxCxx; Manufacturer PN A12505RNCQ
SW2: SW_SPDT; SW_Toggle_SPDT_NKK_M201xxxx03; Manufacturer PN M2012SS1W03

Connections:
/headphone_select: J2.1, J3.1, SW2.2 (B)
/input1_select: J2.3, J3.3, SW1.1
/input2_select: J2.5, J3.5, SW1.2
/input3_select: J2.7, J3.7, SW1.4
/input4_select: J2.9, J3.9, SW1.5
GNDRELAY: D1.1 (K), J1.2, J2.2, J2.4, J2.6, J2.8, J2.10, J3.2, J3.4, J3.6, J3.8, J3.10, J4.1, SW2.3 (C)
unnamed: D1.2 (A), J4.2, R3.2
unnamed: R1.2, SW1.A
unnamed: R2.2, SW2.1 (A)
Vrelay: J1.1, R1.1, R2.1, R3.1

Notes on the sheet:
selects headphone output vs main output UP: headphones DOWN: main output
headphone selection switch
input selection switch
power connector
power LED
use adjustable stops to limit to 4 positions
relay rated current: 11.7 mA relay coil resistance: 1.028 k Vcoil: 12V Vrelay: 15V R = (15V - 12V) / 11.7 mA = 256R
Vf = 1.9V (15V - 1.9V) / 2 mA = 6.6k
TODO move power LED (in layout) to better position change rotary switch symbol so pin numbers match footprint
CC-BY-SA 4.0
relay control connectors
one each for left & right input/output boards
headphones selected
main output selected

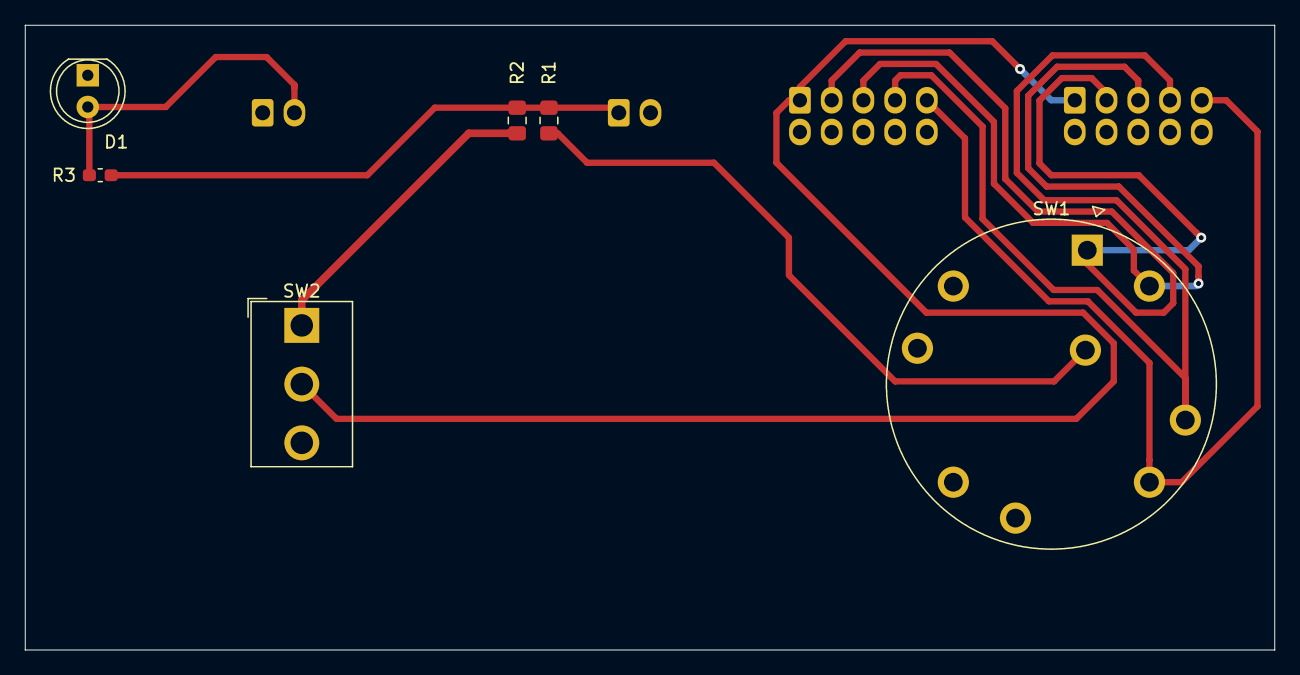
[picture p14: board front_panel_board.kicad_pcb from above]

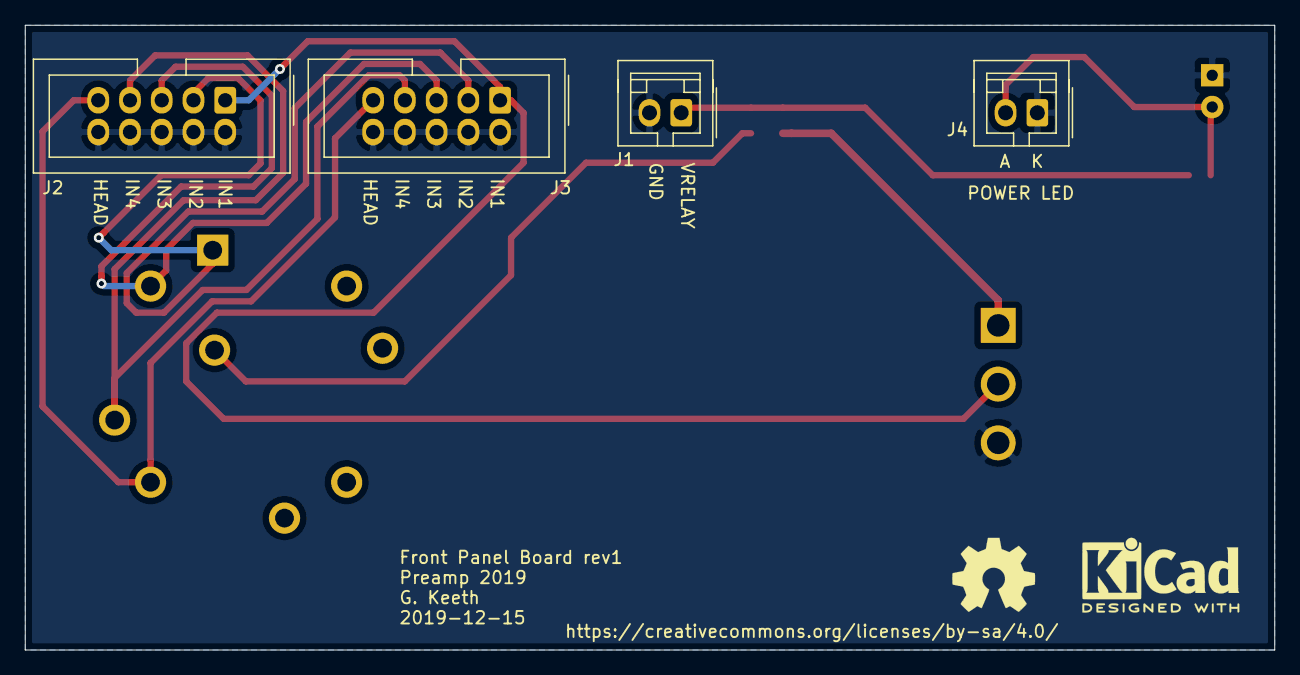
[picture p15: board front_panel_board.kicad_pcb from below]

Board: 2 copper layers, 100.0 x 50.0 mm, 10 parts (4 on the bottom side), 10 nets.

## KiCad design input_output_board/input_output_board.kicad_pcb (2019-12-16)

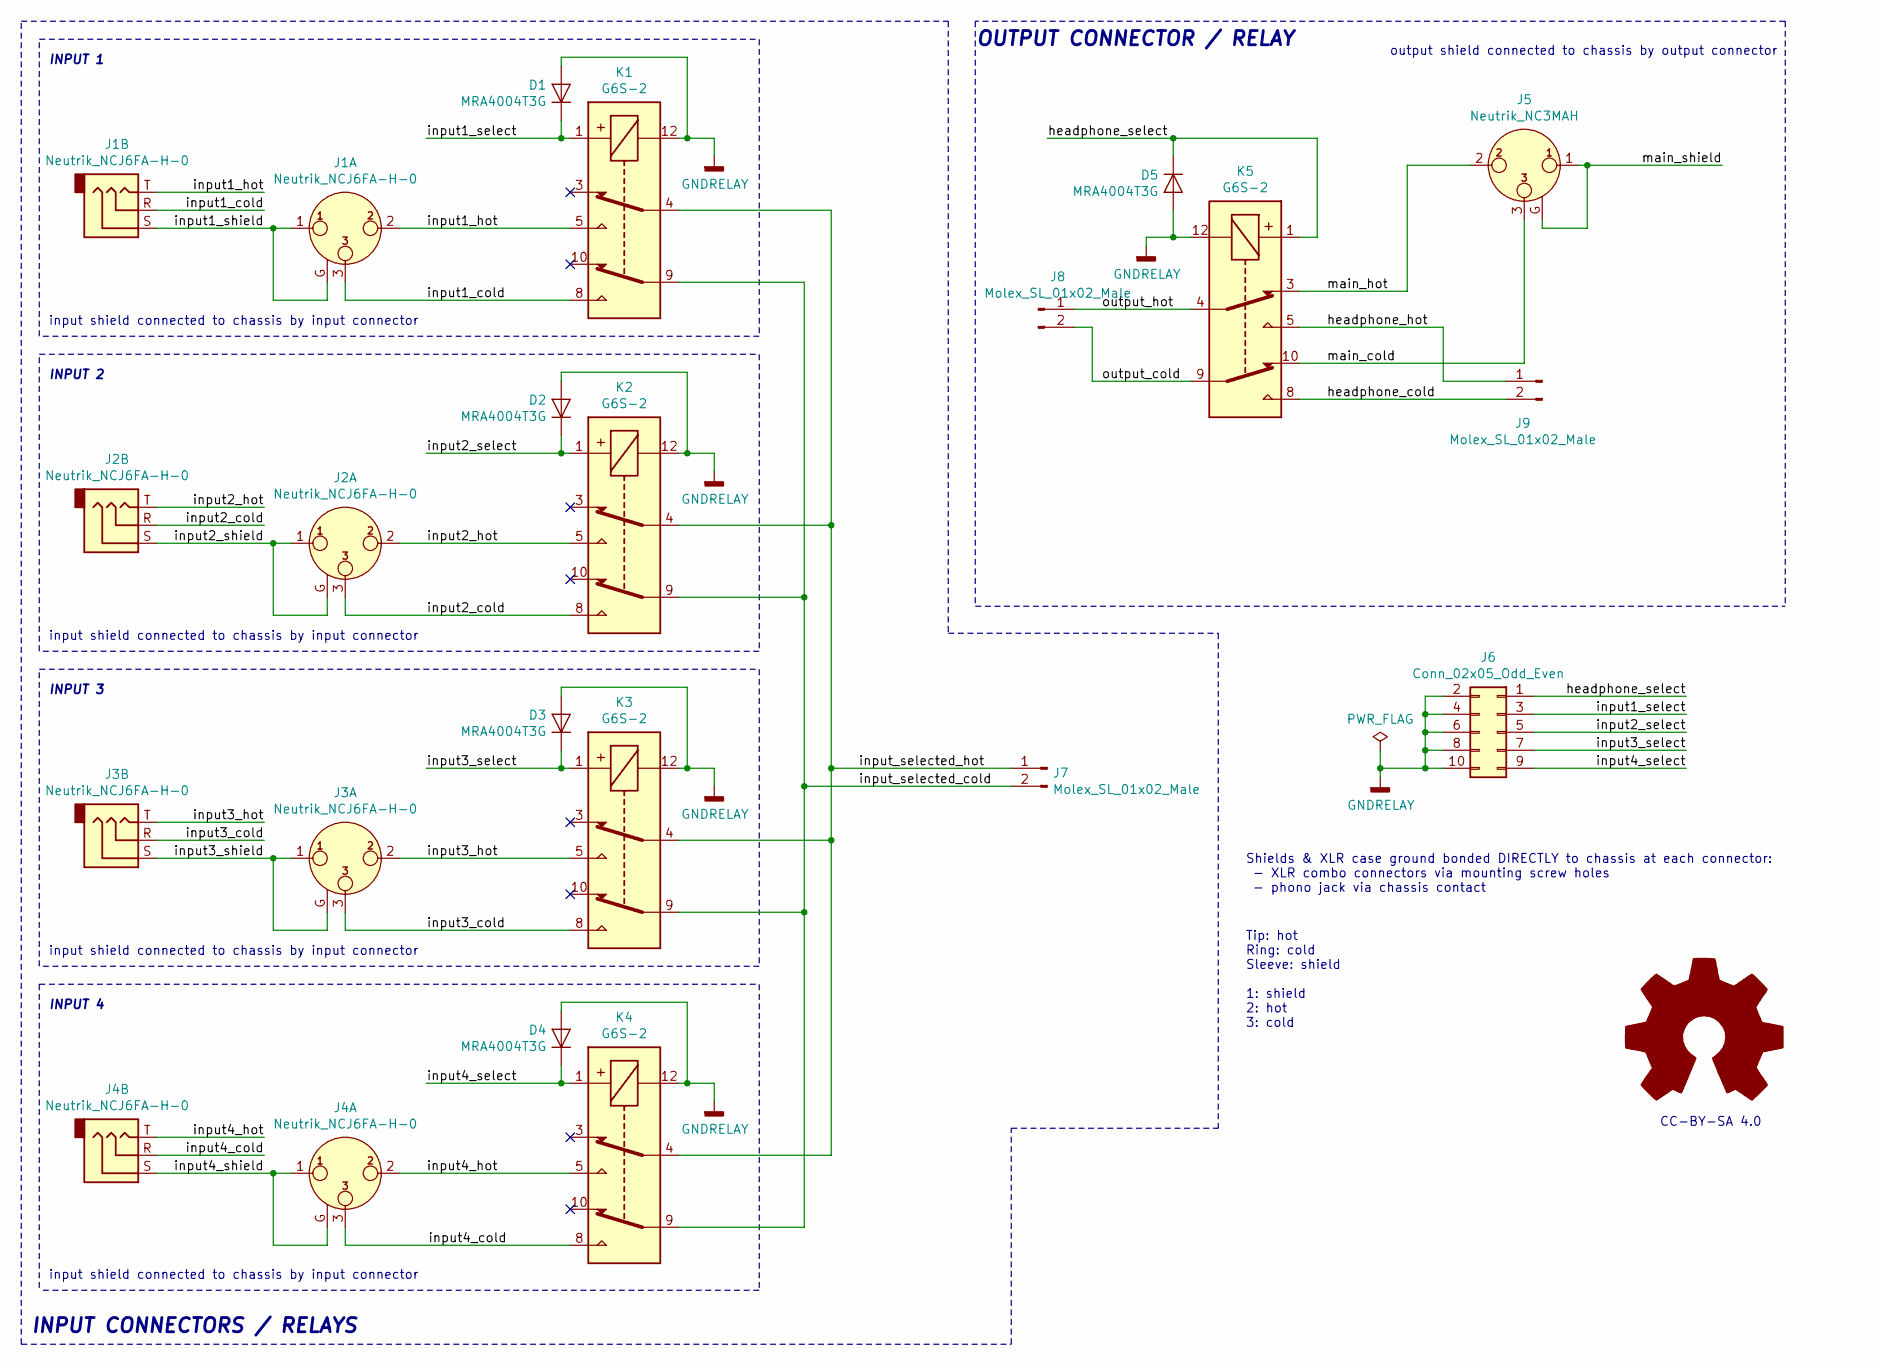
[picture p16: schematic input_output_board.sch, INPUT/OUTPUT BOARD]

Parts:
D1, D2, D3, D4, D5: MRA4004T3G; D_SMA; Manufacturer PN MRA4004T3G
J1, J2, J3, J4: Neutrik_NCJ6FA-H-0; Jack_XLR-6.35mm_Neutrik_NCJ6FA-H-0_Horizontal; Manufacturer PN NCJ6FA-H-0
J5: Neutrik_NC3MAH; Jack_XLR_Neutrik_NC3MAH_Horizontal; Manufacturer PN NC3MAH
J6: Conn_02x05_Odd_Even; Molex_C-Grid_70247-10xx_2x05_P2.54mm_Horizontal; Manufacturer PN 0702461001
J7, J8, J9: Molex_SL_01x02_Male; Molex_SL_A-70553-0001_1x02_P2.54mm_Horizontal; Manufacturer PN 0705430001
K1, K2, K3, K4, K5: G6S-2; Relay_DPDT_Omron_G6S-2F; Manufacturer PN G6S-2F DC12

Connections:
/headphone_cold: J9.2, K5.8
/headphone_hot: J9.1, K5.5
/headphone_select: D5.1 (K), J6.1, K5.1
/input1_cold: J1.3, J1.R, K1.8
/input1_hot: J1.2, J1.T, K1.5
/input1_select: D1.1 (K), J6.3, K1.1
/input1_shield: J1.1, J1.G, J1.S
/input2_cold: J2.3, J2.R, K2.8
/input2_hot: J2.2, J2.T, K2.5
/input2_select: D2.1 (K), J6.5, K2.1
/input2_shield: J2.1, J2.G, J2.S
/input3_cold: J3.3, J3.R, K3.8
/input3_hot: J3.2, J3.T, K3.5
/input3_select: D3.1 (K), J6.7, K3.1
/input3_shield: J3.1, J3.G, J3.S
/input4_cold: J4.3, J4.R, K4.8
/input4_hot: J4.2, J4.T, K4.5
/input4_select: D4.1 (K), J6.9, K4.1
/input4_shield: J4.1, J4.G, J4.S
/input_selected_cold: J7.2, K1.9, K2.9, K3.9, K4.9
/input_selected_hot: J7.1, K1.4, K2.4, K3.4, K4.4
/main_cold: J5.3, K5.10
/main_hot: J5.2, K5.3
/main_shield: J5.1, J5.G
/output_cold: J8.2, K5.9
/output_hot: J8.1, K5.4
GNDRELAY: D1.2 (A), D2.2 (A), D3.2 (A), D4.2 (A), D5.2 (A), J6.2, J6.4, J6.6, J6.8, J6.10, K1.12, K2.12, K3.12, K4.12, K5.12

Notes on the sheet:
Tip: hot Ring: cold Sleeve: shield 1: shield 2: hot 3: cold
Shields & XLR case ground bonded DIRECTLY to chassis at each connector: - XLR combo connectors via mounting screw holes - phono jack via chassis contact
INPUT CONNECTORS / RELAYS
INPUT 1
INPUT 2
INPUT 3
INPUT 4
CC-BY-SA 4.0
input shield connected to chassis by input connector
output shield connected to chassis by output connector
OUTPUT CONNECTOR / RELAY

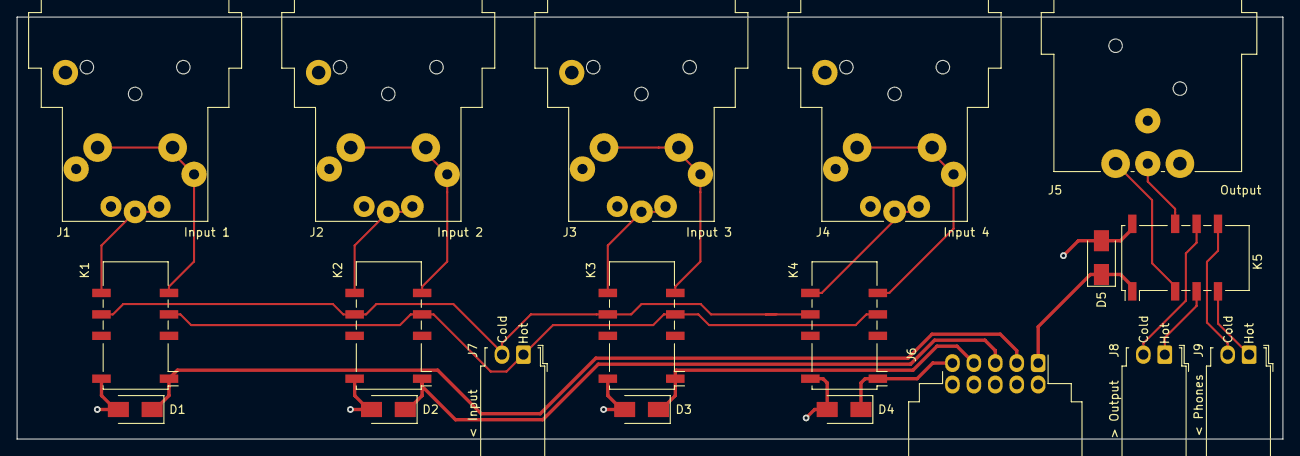
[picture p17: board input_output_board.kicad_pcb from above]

Board: 2 copper layers, 150.0 x 50.0 mm, 19 parts (0 on the bottom side), 27 nets.

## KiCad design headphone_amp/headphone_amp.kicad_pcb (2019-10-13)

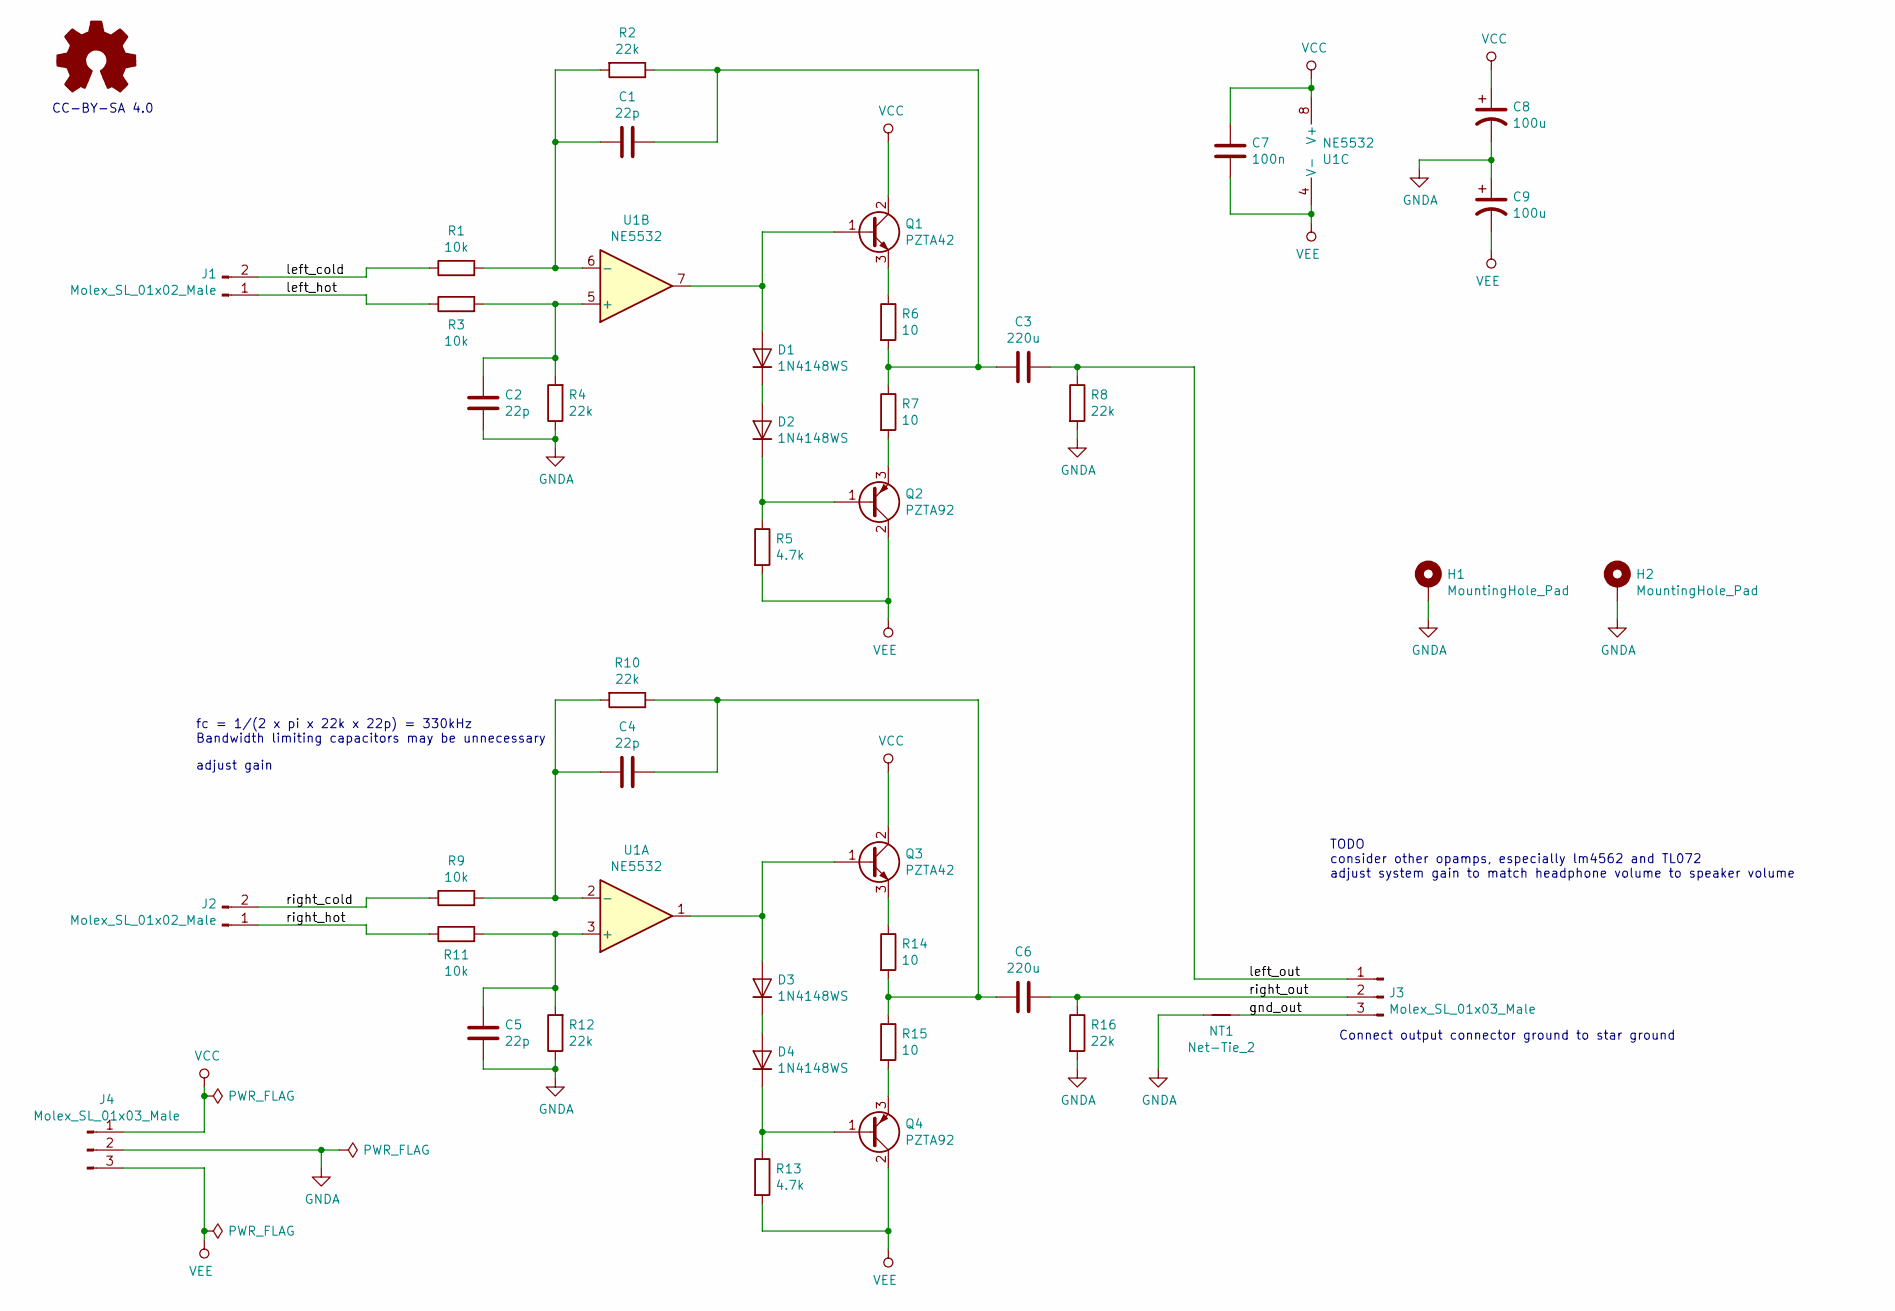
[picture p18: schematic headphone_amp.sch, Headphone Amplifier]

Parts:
C1, C2, C4, C5: 22p; C_0603_1608Metric_Pad1.05x0.95mm_HandSolder; Manufacturer PN C0603C220J5GAC7411
C3, C6: 220u; C_Radial_D12.5mm_H20.0mm_P5.00mm; Voltage Rating 35V; Manufacturer PN UVP1V221MHD
C7: 100n; C_0805_2012Metric_Pad1.15x1.40mm_HandSolder; Manufacturer PN GCM21BR72A104KA37K
C8, C9: 100u; CP_Radial_D6.3mm_P2.50mm; Voltage Rating 35V; Manufacturer PN UVR1V101MED
D1, D2, D3, D4: 1N4148WS; D_SOD-323; Manufacturer PN 1N4148WS
H1, H2: MountingHole_Pad; MountingHole_3.2mm_M3_Pad
J1, J2: Molex_SL_01x02_Male; Molex_SL_A-70553-0001_1x02_P2.54mm_Horizontal; Manufacturer PN 70553-0001
J3, J4: Molex_SL_01x03_Male; Molex_SL_A-70553-0002_1x03_P2.54mm_Horizontal; Manufacturer PN 70553-0002
NT1: Net-Tie_2; NetTie-2_SMD_Pad2.0mm
Q1, Q3: PZTA42; SOT-223-3_TabPin2; Manufacturer PN PZTA42T1G
Q2, Q4: PZTA92; SOT-223-3_TabPin2; Manufacturer PN PZTA92T1G
R1, R3, R9, R11: 10k; R_0603_1608Metric_Pad1.05x0.95mm_HandSolder; Manufacturer PN RT0603FRE0710KL
R2, R4, R8, R10, R12, R16: 22k; R_0603_1608Metric_Pad1.05x0.95mm_HandSolder; Manufacturer PN RT0603FRE1322KL
R5, R13: 4.7k; R_0603_1608Metric_Pad1.05x0.95mm_HandSolder; Manufacturer PN RT0603FRE074K7L
R6, R7, R14, R15: 10; R_0603_1608Metric_Pad1.05x0.95mm_HandSolder; Manufacturer PN RNCP0603FTD10R0
U1: NE5532; SOIC-8_3.9x4.9mm_P1.27mm; Manufacturer PN NE5532AD8R2G

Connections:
/gnd_out: J3.3, NT1.2
/left_cold: J1.2, R1.1
/left_hot: J1.1, R3.1
/left_out: C3.1, J3.1, R8.1
/right_cold: J2.2, R9.1
/right_hot: J2.1, R11.1
/right_out: C6.1, J3.2, R16.1
GNDA: C2.2, C5.2, C8.2, C9.1, H1.1, H2.1, J4.2, NT1.1, R4.1, R8.2, R12.1, R16.2
unnamed: C1.1, C3.2, R2.1, R6.2, R7.1
unnamed: C1.2, R1.2, R2.2, U1.6 (-)
unnamed: C2.1, R3.2, R4.2, U1.5 (+)
unnamed: C4.1, C6.2, R10.1, R14.2, R15.1
unnamed: C4.2, R9.2, R10.2, U1.2 (-)
unnamed: C5.1, R11.2, R12.2, U1.3 (+)
unnamed: D1.1 (K), D2.2 (A)
unnamed: D1.2 (A), Q1.1 (B), U1.7
unnamed: D2.1 (K), Q2.1 (B), R5.1
unnamed: D3.1 (K), D4.2 (A)
unnamed: D3.2 (A), Q3.1 (B), U1.1
unnamed: D4.1 (K), Q4.1 (B), R13.1
unnamed: Q1.3 (E), R6.1
unnamed: Q2.3 (E), R7.2
unnamed: Q3.3 (E), R14.1
unnamed: Q4.3 (E), R15.2
VCC: C7.1, C8.1, J4.1, Q1.2 (C), Q3.2 (C), U1.8 (V+)
VEE: C7.2, C9.2, J4.3, Q2.2 (C), Q4.2 (C), R5.2, R13.2, U1.4 (V-)

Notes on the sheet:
TODO consider other opamps, especially lm4562 and TL072 adjust system gain to match headphone volume to speaker volume
CC-BY-SA 4.0
fc = 1/(2 x pi x 22k x 22p) = 330kHz Bandwidth limiting capacitors may be unnecessary
Connect output connector ground to star ground
adjust gain

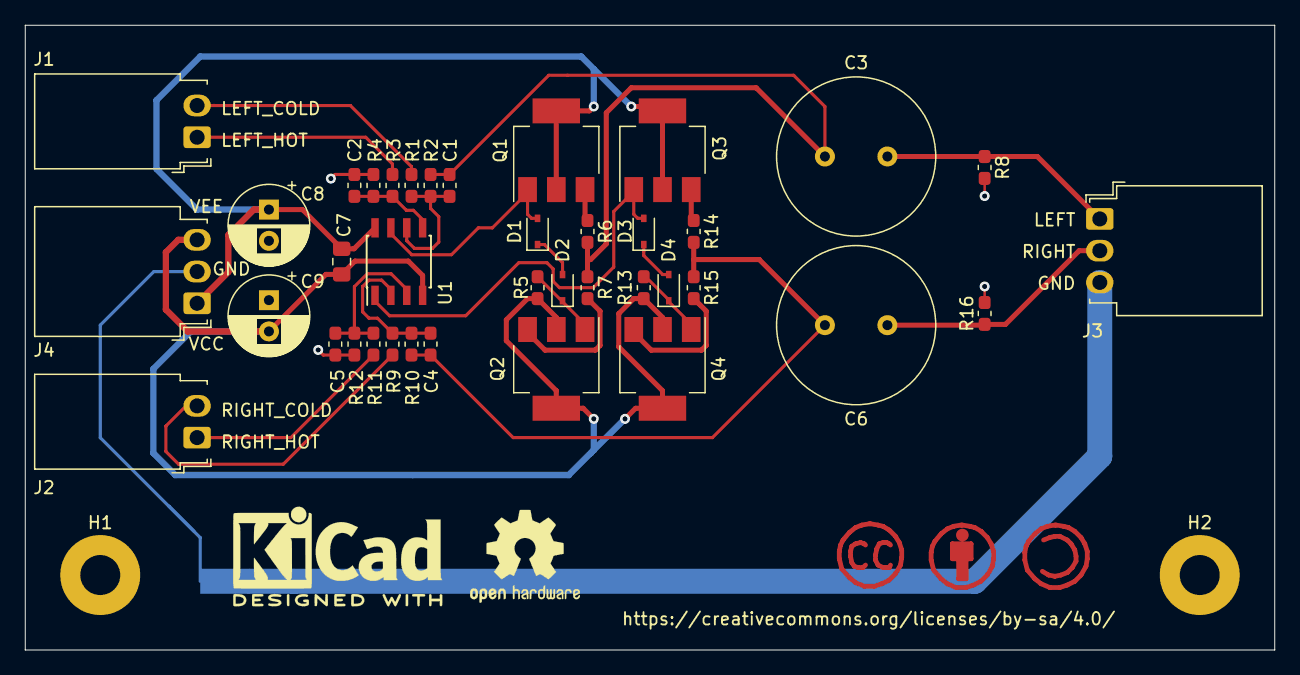
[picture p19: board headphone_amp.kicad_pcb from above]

Board: 2 copper layers, 100.0 x 50.0 mm, 41 parts (1 on the bottom side), 26 nets.

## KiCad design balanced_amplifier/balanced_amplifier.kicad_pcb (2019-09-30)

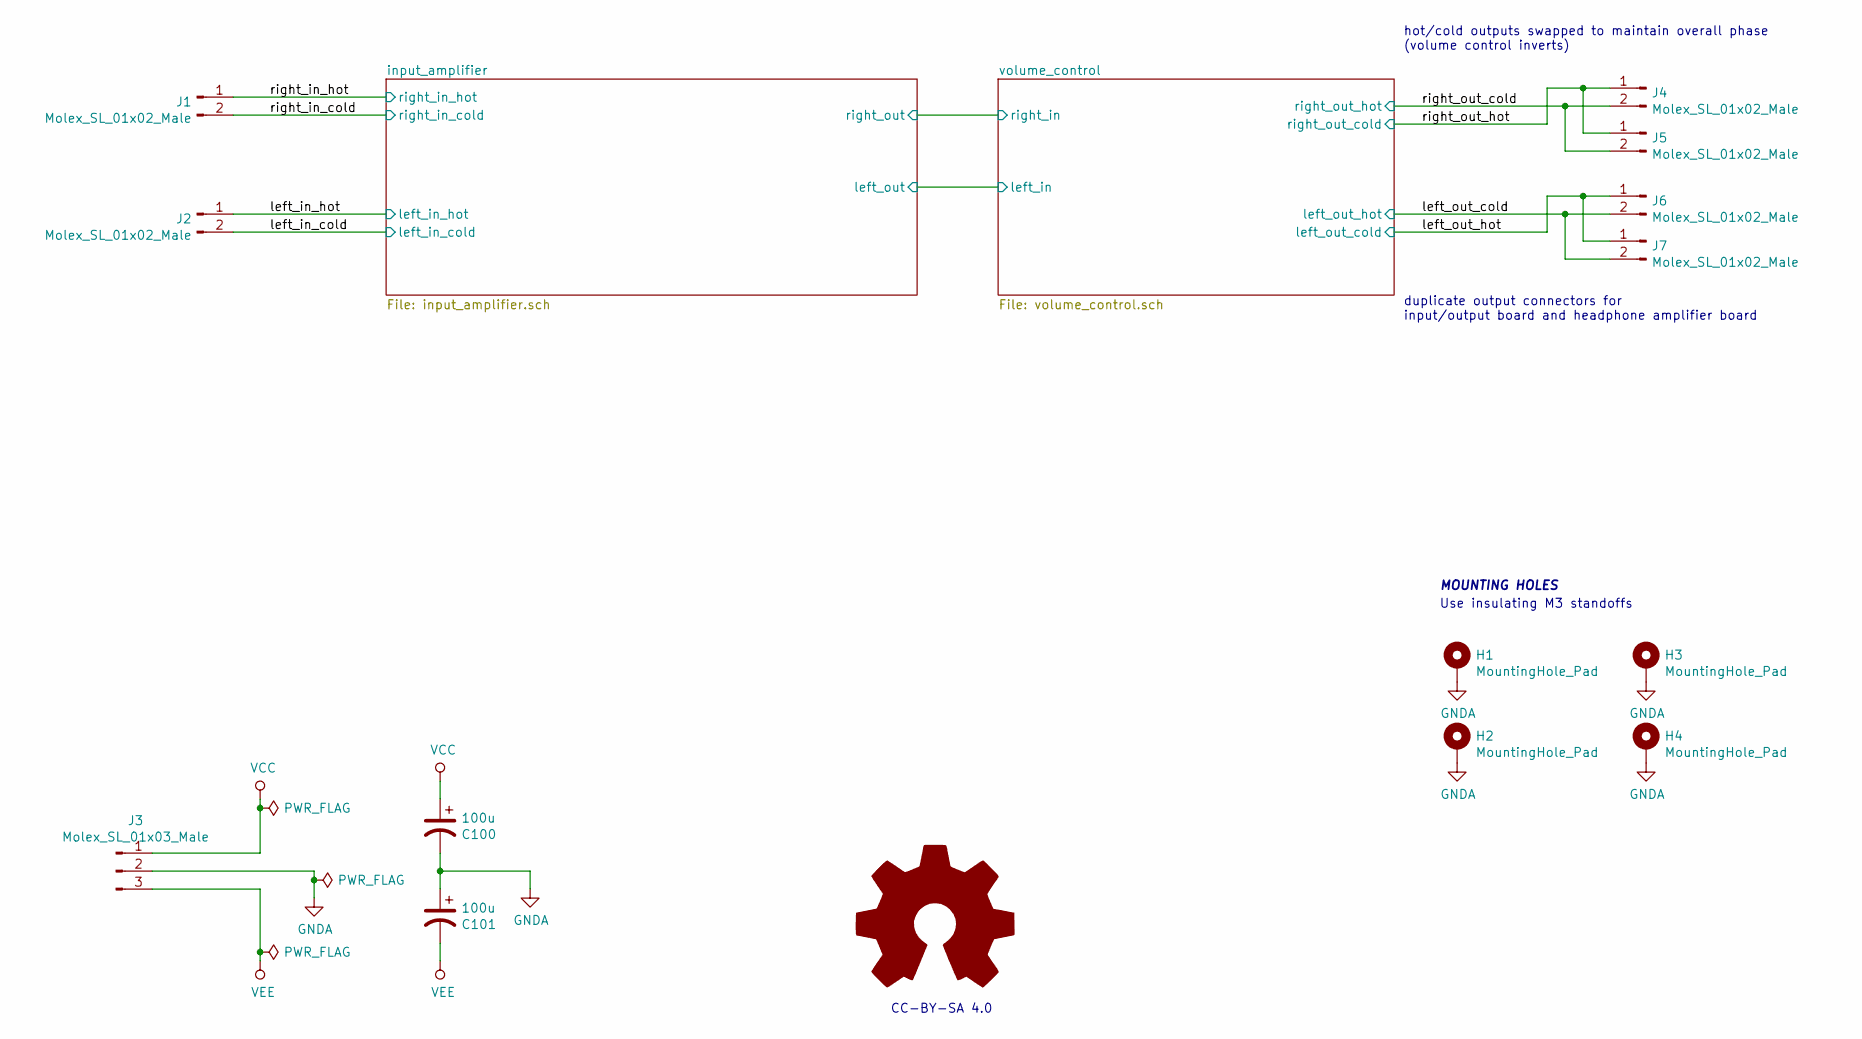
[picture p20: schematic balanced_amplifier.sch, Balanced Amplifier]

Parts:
C100, C101: 100u; CP_Radial_D6.3mm_P2.50mm; Voltage Rating 35V; Manufacturer PN UVR1V101MED
H1, H2, H3, H4: MountingHole_Pad; MountingHole_3.2mm_M3_Pad
J1, J2, J4, J5, J6, J7: Molex_SL_01x02_Male; Molex_SL_A-70543-0001_1x02_P2.54mm_Vertical; Manufacturer PN 0705430001
J3: Molex_SL_01x03_Male; Molex_SL_A-70543-0002_1x03_P2.54mm_Vertical; Manufacturer PN 0705430002

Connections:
/left_in_cold: J2.2; also elsewhere on the board
/left_in_hot: J2.1; also elsewhere on the board
/left_out_cold: J6.2, J7.2; also elsewhere on the board
/left_out_hot: J6.1, J7.1; also elsewhere on the board
/right_in_cold: J1.2; also elsewhere on the board
/right_in_hot: J1.1; also elsewhere on the board
/right_out_cold: J4.2, J5.2; also elsewhere on the board
/right_out_hot: J4.1, J5.1; also elsewhere on the board
GNDA: C100.2, C101.1, H1.1, H2.1, H3.1, H4.1, J3.2; also elsewhere on the board
VCC: C100.1, J3.1; also elsewhere on the board
VEE: C101.2, J3.3; also elsewhere on the board

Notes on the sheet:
hot/cold outputs swapped to maintain overall phase (volume control inverts)
Use insulating M3 standoffs
duplicate output connectors for input/output board and headphone amplifier board
MOUNTING HOLES
CC-BY-SA 4.0

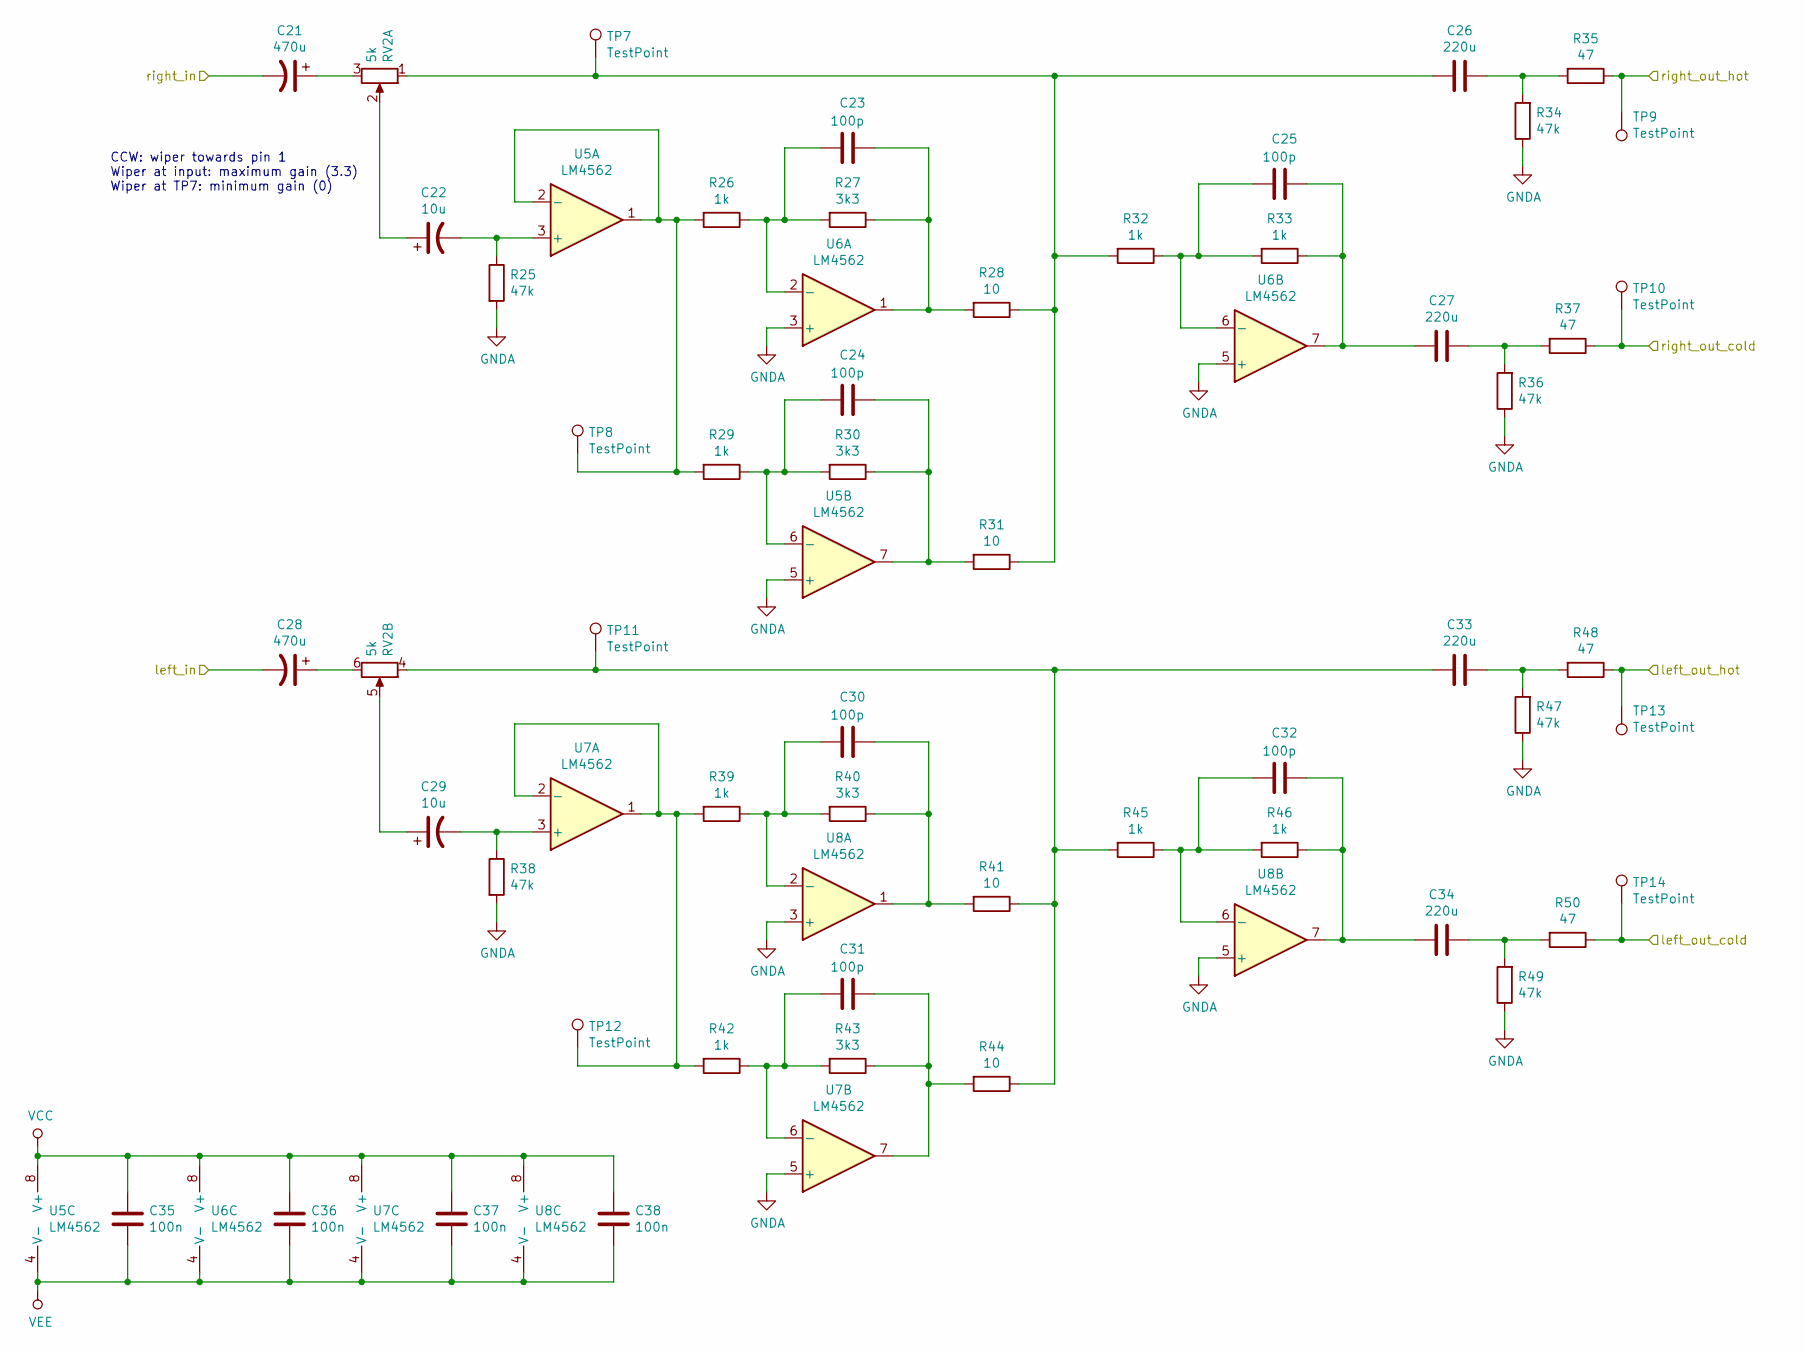
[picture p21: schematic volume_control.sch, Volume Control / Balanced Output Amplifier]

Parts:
C21, C28: 470u; CP_Radial_D10.0mm_P5.00mm; Voltage Rating 35V; Manufacturer PN UVR1V471MPD
C22, C29: 10u; CP_Radial_D5.0mm_P2.00mm; Voltage Rating 35V; Manufacturer PN UVR1V100MDD
C23, C24, C25, C30, C31, C32: 100p; C_0603_1608Metric_Pad1.05x0.95mm_HandSolder; Manufacturer PN CC0603JRNPO9BN101
C26, C27, C33, C34: 220u; C_Radial_D12.5mm_H20.0mm_P5.00mm; Voltage Rating 35V; Manufacturer PN UVP1V221MHD
C35, C36, C37, C38: 100n; C_0805_2012Metric_Pad1.15x1.40mm_HandSolder; Manufacturer PN GCM21BR72A104KA37K
R25, R34, R36, R38, R47, R49: 47k; R_0603_1608Metric_Pad1.05x0.95mm_HandSolder; Manufacturer PN RT0603FRE0747KL
R26, R29, R32, R33, R39, R42, R45, R46: 1k; R_1206_3216Metric_Pad1.42x1.75mm_HandSolder; Manufacturer PN RT1206FRE071KL
R27, R30, R40, R43: 3k3; R_0603_1608Metric_Pad1.05x0.95mm_HandSolder; Manufacturer PN RT0603FRE073K3L
R28, R31, R41, R44: 10; R_0603_1608Metric_Pad1.05x0.95mm_HandSolder; Manufacturer PN RNCP0603FTD10R0
R35, R37, R48, R50: 47; R_0603_1608Metric_Pad1.05x0.95mm_HandSolder; Manufacturer PN RT0603DRE0747RL
RV2: 5k; Potentiometer_Bourns_91A2x-x28-xxx_Dual_Horizontal; Manufacturer PN 91A2A-B28-B13/B13L
TP7, TP8, TP9, TP10, TP11, TP12, TP13, TP14: TestPoint; TestPoint_Keystone_5000-5004_Miniature; Manufacturer PN 5002
U5, U6, U7, U8: LM4562; SOIC-8_3.9x4.9mm_P1.27mm; Manufacturer PN LM4562MAX/NOPB

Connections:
/left_out_cold: R48.1, TP13.1; also elsewhere on the board
/left_out_hot: R50.1, TP14.1; also elsewhere on the board
/right_out_cold: R35.1, TP9.1; also elsewhere on the board
/right_out_hot: R37.1, TP10.1; also elsewhere on the board
/volume_control/left_in: C28.2; also elsewhere on the board
/volume_control/right_in: C21.2; also elsewhere on the board
GNDA: R25.2, R34.1, R36.1, R38.2, R47.1, R49.1, U5.5 (+), U6.3 (+), U6.5 (+), U7.5 (+), U8.3 (+), U8.5 (+); also elsewhere on the board
unnamed: C21.1, RV2.3
unnamed: C22.1, RV2.2
unnamed: C22.2, R25.1, U5.3 (+)
unnamed: C23.1, R27.1, R28.2, U6.1
unnamed: C23.2, R26.1, R27.2, U6.2 (-)
unnamed: C24.1, R30.1, R31.2, U5.7
unnamed: C24.2, R29.1, R30.2, U5.6 (-)
unnamed: C25.1, C27.2, R33.1, U6.7
unnamed: C25.2, R32.1, R33.2, U6.6 (-)
unnamed: C26.1, R34.2, R35.2
unnamed: C26.2, R28.1, R31.1, R32.2, RV2.1, TP7.1
unnamed: C27.1, R36.2, R37.2
unnamed: C28.1, RV2.6
unnamed: C29.1, RV2.5
unnamed: C29.2, R38.1, U7.3 (+)
unnamed: C30.1, R40.1, R41.2, U8.1
unnamed: C30.2, R39.1, R40.2, U8.2 (-)
unnamed: C31.1, R43.1, R44.2, U7.7
unnamed: C31.2, R42.1, R43.2, U7.6 (-)
unnamed: C32.1, C34.2, R46.1, U8.7
unnamed: C32.2, R45.1, R46.2, U8.6 (-)
unnamed: C33.1, R47.2, R48.2
unnamed: C33.2, R41.1, R44.1, R45.2, RV2.4, TP11.1
unnamed: C34.1, R49.2, R50.2
unnamed: R26.2, R29.2, TP8.1, U5.1, U5.2 (-)
unnamed: R39.2, R42.2, TP12.1, U7.1, U7.2 (-)
VCC: C35.1, C36.1, C37.1, C38.1, U5.8 (V+), U6.8 (V+), U7.8 (V+), U8.8 (V+); also elsewhere on the board
VEE: C35.2, C36.2, C37.2, C38.2, U5.4 (V-), U6.4 (V-), U7.4 (V-), U8.4 (V-); also elsewhere on the board

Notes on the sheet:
CCW: wiper towards pin 1 Wiper at input: maximum gain (3.3) Wiper at TP7: minimum gain (0)

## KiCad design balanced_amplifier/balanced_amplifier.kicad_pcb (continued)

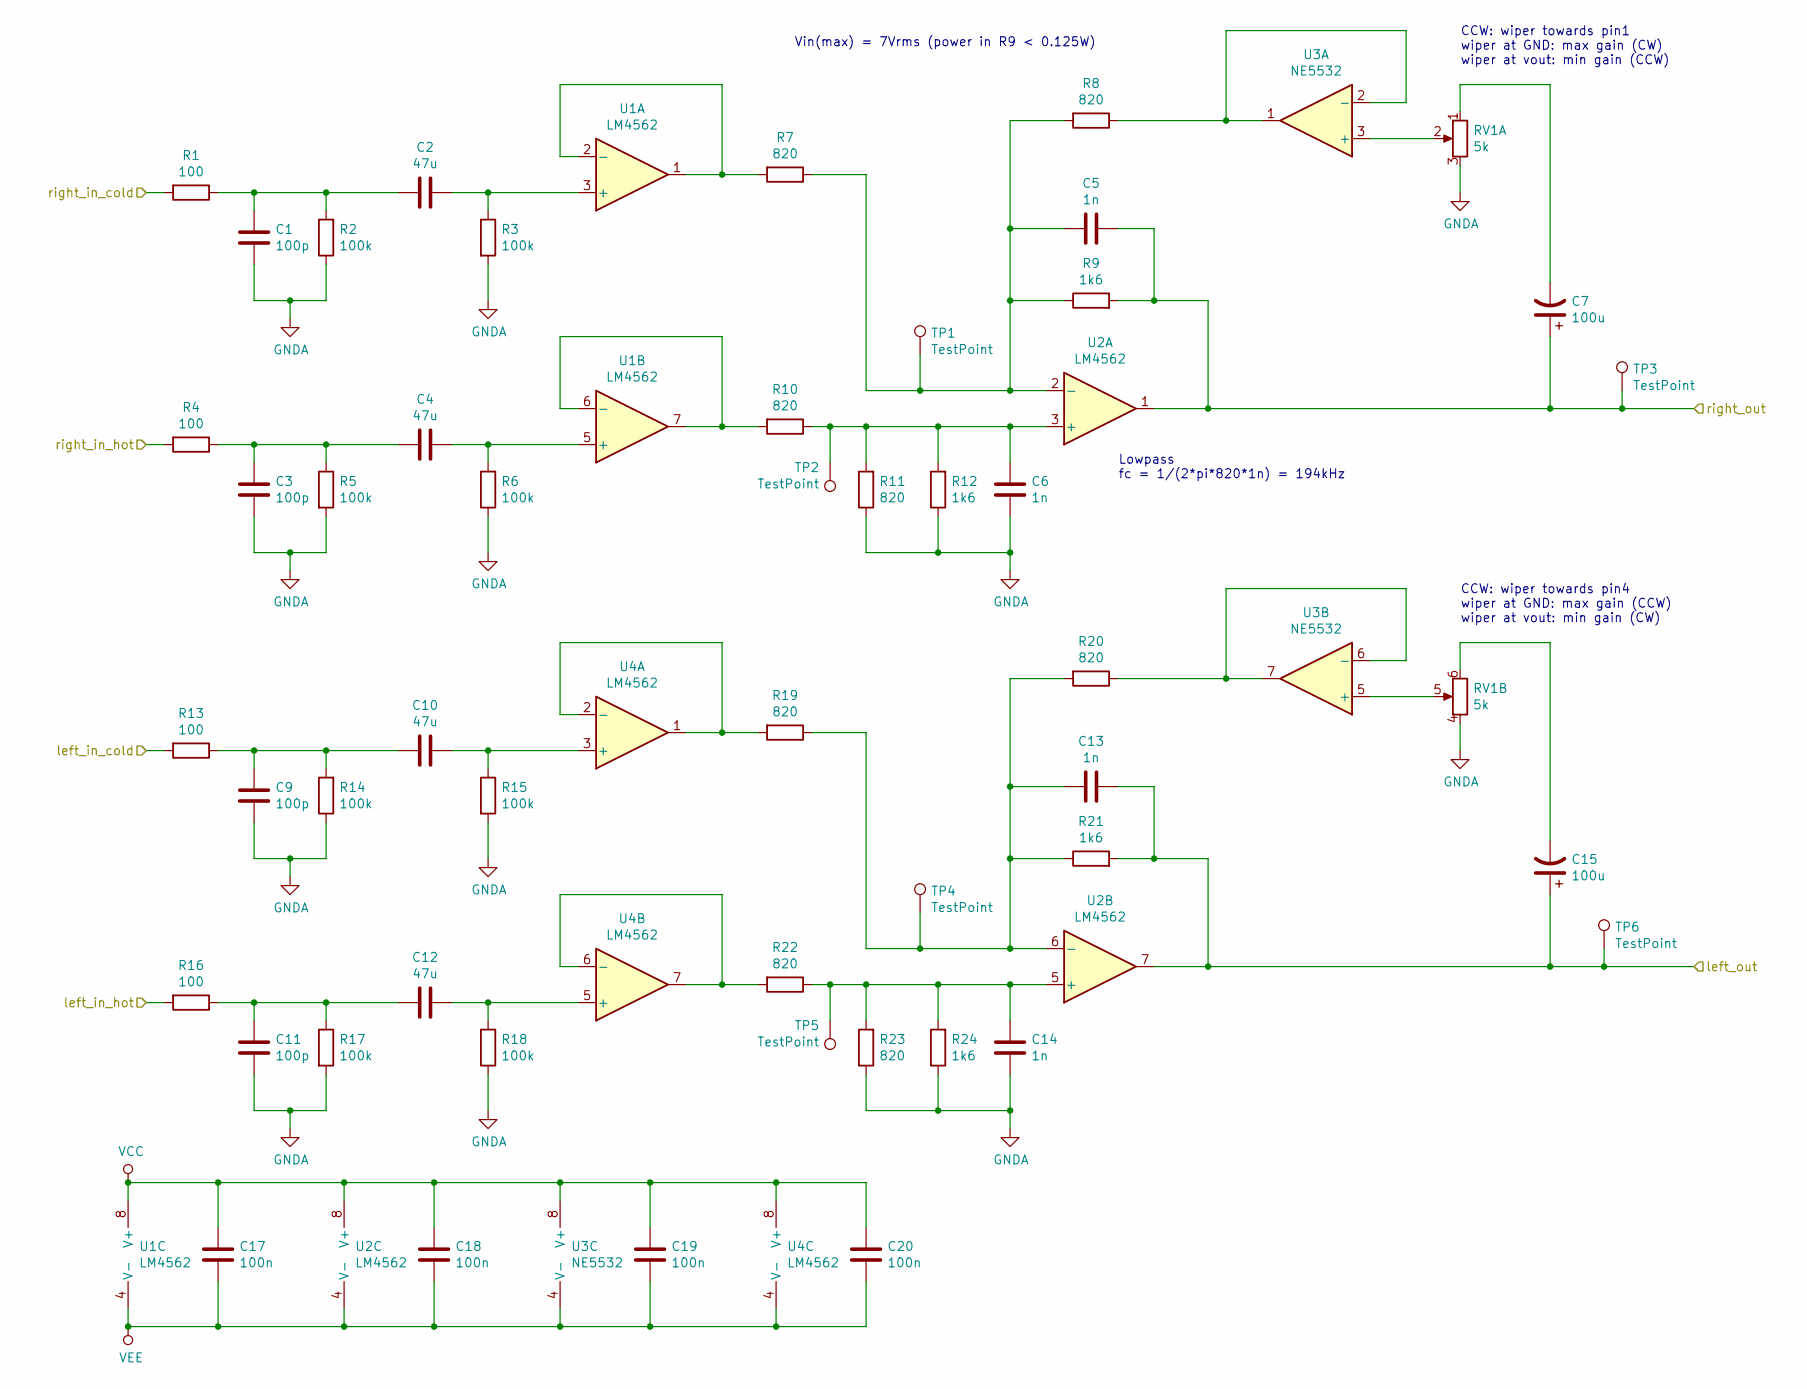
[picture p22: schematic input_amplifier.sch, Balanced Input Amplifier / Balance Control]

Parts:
C1, C3, C9, C11: 100p; C_0603_1608Metric_Pad1.05x0.95mm_HandSolder; Manufacturer PN CC0603JRNPO9BN101
C2, C4, C10, C12: 47u; C_Radial_D8.0mm_H11.5mm_P3.50mm; Voltage Rating 35V; Manufacturer PN UVP1V470MPD
C5, C6, C13, C14: 1n; C_0603_1608Metric_Pad1.05x0.95mm_HandSolder; Manufacturer PN GRM1885C1H102FA01J
C7, C15: 100u; CP_Radial_D6.3mm_P2.50mm; Voltage Rating 35V; Manufacturer PN UVR1V101MED
C17, C18, C19, C20: 100n; C_0805_2012Metric_Pad1.15x1.40mm_HandSolder; Manufacturer PN GCM21BR72A104KA37K
R1, R4, R13, R16: 100; R_0603_1608Metric_Pad1.05x0.95mm_HandSolder; Manufacturer PN RT0603FRE07100RL
R2, R3, R5, R6, R14, R15, R17, R18: 100k; R_0603_1608Metric_Pad1.05x0.95mm_HandSolder; Manufacturer PN AT0603DRD07100KL
R7, R8, R10, R11, R19, R20, R22, R23: 820; R_0603_1608Metric_Pad1.05x0.95mm_HandSolder; Manufacturer PN ERA-3AEB821V
R9, R12, R21, R24: 1k6; R_1206_3216Metric_Pad1.42x1.75mm_HandSolder; Manufacturer PN ERA-8AEB162V
RV1: 5k; Potentiometer_Bourns_91A2x-x28-xxx_Dual_Horizontal; Manufacturer PN 91A2A-B28-B13/B13L
TP1, TP2, TP3, TP4, TP5, TP6: TestPoint; TestPoint_Keystone_5000-5004_Miniature; Manufacturer PN 5002
U1, U2, U4: LM4562; SOIC-8_3.9x4.9mm_P1.27mm; Manufacturer PN LM4562MAX/NOPB
U3: NE5532; SOIC-8_3.9x4.9mm_P1.27mm; Manufacturer PN NE5532AD8R2G

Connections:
/left_in_cold: R13.2; also elsewhere on the board
/left_in_hot: R16.2; also elsewhere on the board
/right_in_cold: R1.2; also elsewhere on the board
/right_in_hot: R4.2; also elsewhere on the board
/volume_control/left_in: C13.1, C15.1, R21.2, TP6.1, U2.7; also elsewhere on the board
/volume_control/right_in: C5.1, C7.1, R9.2, TP3.1, U2.1; also elsewhere on the board
GNDA: C1.2, C3.2, C6.2, C9.2, C11.2, C14.2, R2.1, R3.2, R5.2, R6.1, R11.1, R12.1, R14.1, R15.2, R17.2, R18.1, R23.1, R24.1, RV1.3, RV1.4; also elsewhere on the board
unnamed: C1.1, C2.2, R1.1, R2.2
unnamed: C2.1, R3.1, U1.3 (+)
unnamed: C3.1, C4.2, R4.1, R5.1
unnamed: C4.1, R6.2, U1.5 (+)
unnamed: C5.2, R7.1, R8.2, R9.1, TP1.1, U2.2 (-)
unnamed: C6.1, R10.1, R11.2, R12.2, TP2.1, U2.3 (+)
unnamed: C7.2, RV1.1
unnamed: C10.1, R15.1, U4.3 (+)
unnamed: C9.1, C10.2, R13.1, R14.2
unnamed: C11.1, C12.2, R16.1, R17.1
unnamed: C12.1, R18.2, U4.5 (+)
unnamed: C13.2, R19.1, R20.2, R21.1, TP4.1, U2.6 (-)
unnamed: C14.1, R22.1, R23.2, R24.2, TP5.1, U2.5 (+)
unnamed: C15.2, RV1.6
unnamed: R7.2, U1.1, U1.2 (-)
unnamed: R8.1, U3.1, U3.2 (-)
unnamed: R10.2, U1.6 (-), U1.7
unnamed: R19.2, U4.1, U4.2 (-)
unnamed: R20.1, U3.6 (-), U3.7
unnamed: R22.2, U4.6 (-), U4.7
unnamed: RV1.2, U3.3 (+)
unnamed: RV1.5, U3.5 (+)
VCC: C17.1, C18.1, C19.1, C20.1, U1.8 (V+), U2.8 (V+), U3.8 (V+), U4.8 (V+); also elsewhere on the board
VEE: C17.2, C18.2, C19.2, C20.2, U1.4 (V-), U2.4 (V-), U3.4 (V-), U4.4 (V-); also elsewhere on the board

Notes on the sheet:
Lowpass fc = 1/(2*pi*820*1n) = 194kHz
CCW: wiper towards pin1 wiper at GND: max gain (CW) wiper at vout: min gain (CCW)
CCW: wiper towards pin4 wiper at GND: max gain (CCW) wiper at vout: min gain (CW)
Vin(max) = 7Vrms (power in R9 < 0.125W)

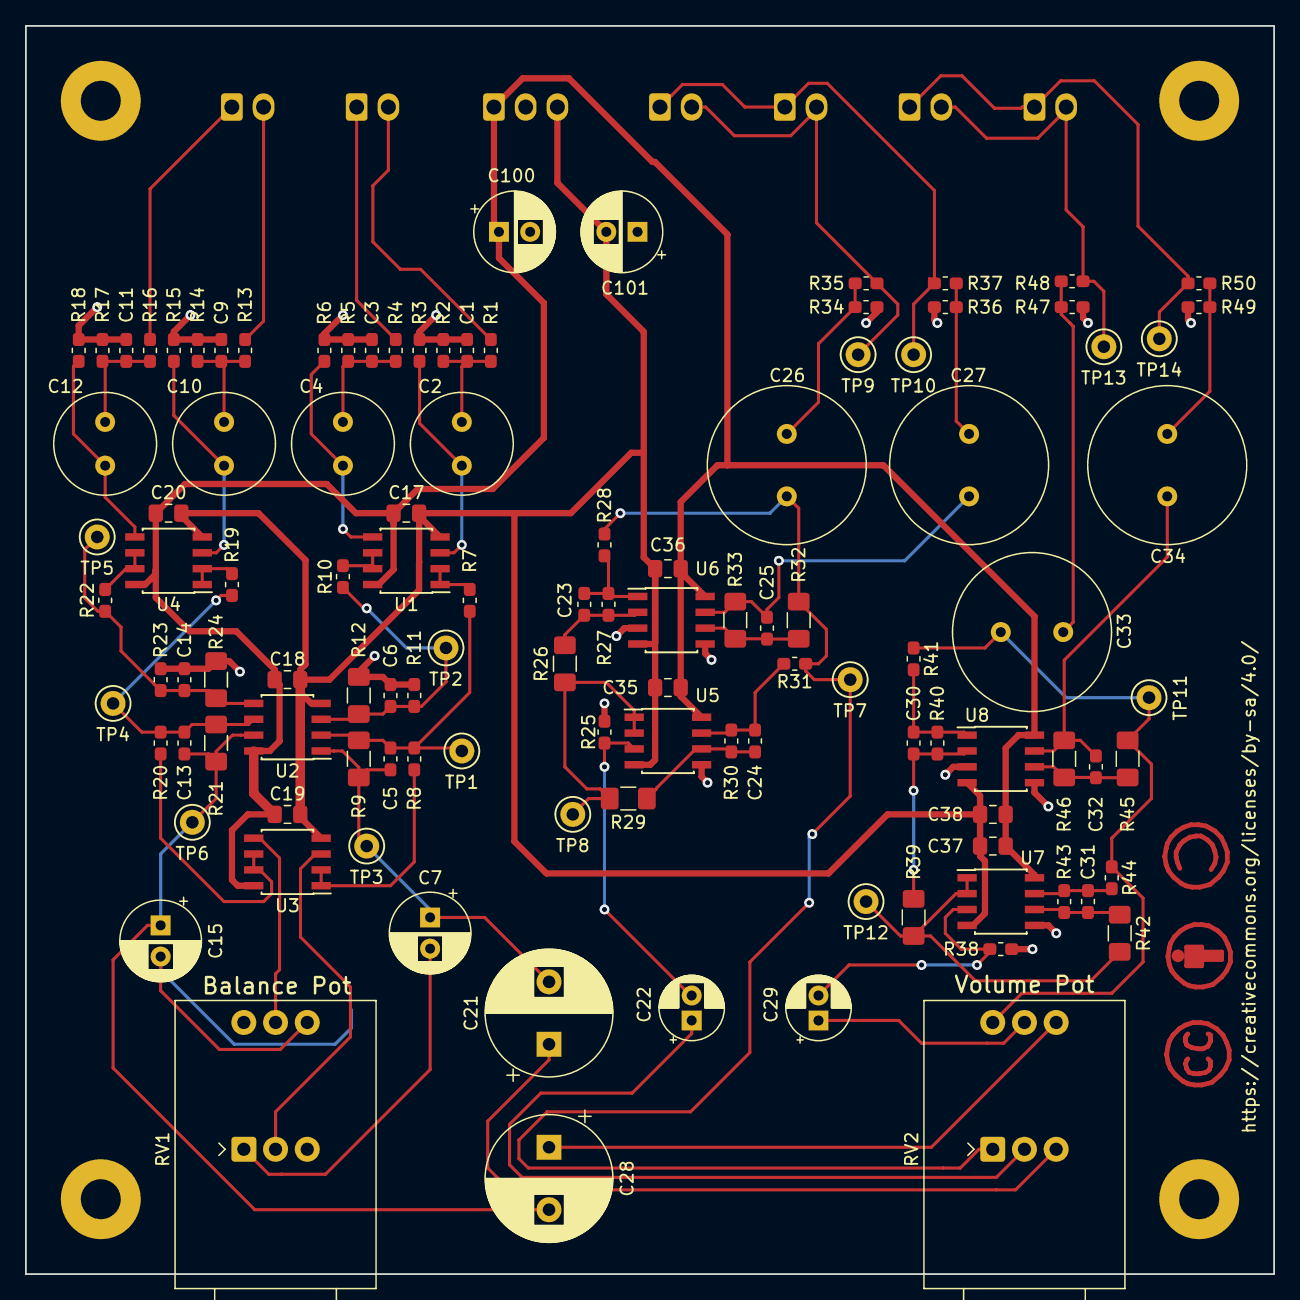
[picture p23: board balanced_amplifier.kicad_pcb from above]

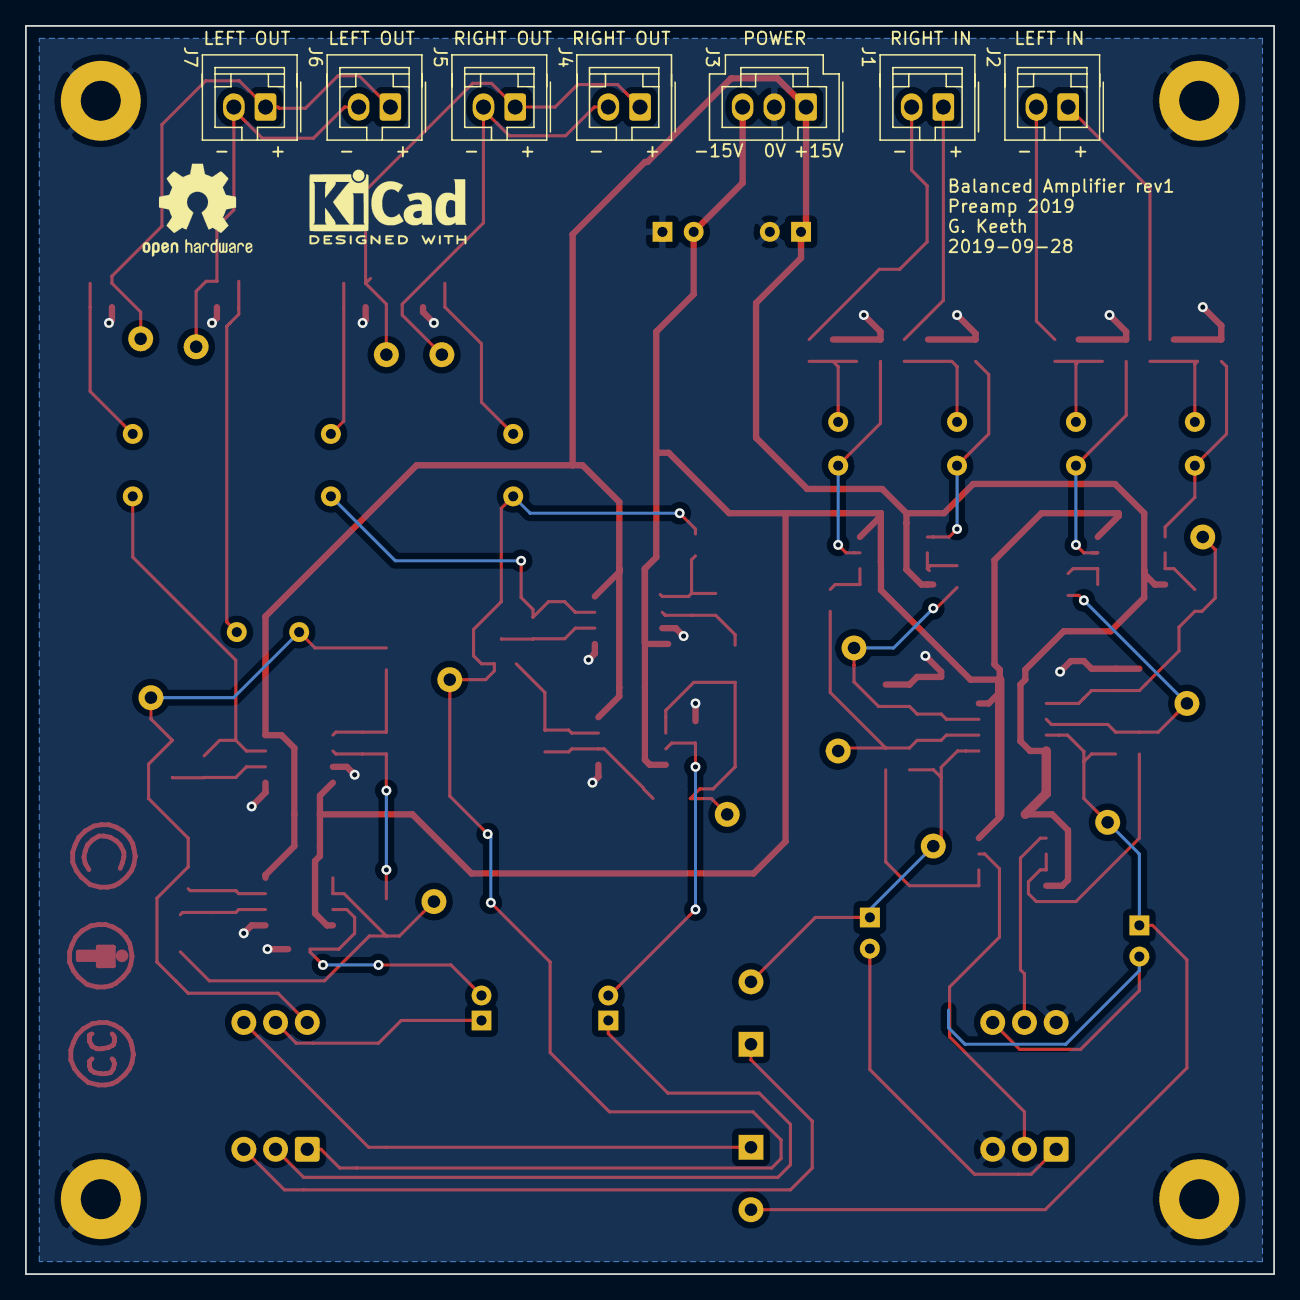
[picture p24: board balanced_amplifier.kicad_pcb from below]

Board: 2 copper layers, 100.0 x 100.0 mm, 123 parts (7 on the bottom side), 61 nets.

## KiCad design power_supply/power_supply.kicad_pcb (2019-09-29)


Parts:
C1: 10n; C_Rect_L7.2mm_W2.5mm_P5.00mm_FKS2_FKP2_MKS2_MKP2; Manufacturer PN B32529C3103J000
C2: 150n; C_Rect_L7.5mm_W6.5mm_P5.00mm; Manufacturer PN B32529C3154K000
C3, C4: 1000u; CP_Radial_D12.5mm_P5.00mm; Manufacturer PN UHE1H102MHD
C5, C11: 330n; C_0805_2012Metric_Pad1.15x1.40mm_HandSolder; Manufacturer PN CL21B334KBFNNNE
C6: 22u; CP_Radial_D5.0mm_P2.00mm; Manufacturer PN UHE1H220MDD
C7, C12: 100n; C_0805_2012Metric_Pad1.15x1.40mm_HandSolder; Manufacturer PN CL21B104MBCNNNC
C8: 1u; CP_Radial_D4.0mm_P1.50mm; Manufacturer PN UMT1H010MDD1TP
C9, C10, C13: 100u; CP_Radial_D6.3mm_P2.50mm; Manufacturer PN UVZ1V101MED1TD
D1, D2, D3, D4, D5, D6, D7, D8, D11, D12: MRA4004T3G; D_SMA; Manufacturer PN MRA4004T3G
D9, D10: LED; LED_0603_1608Metric; Manufacturer PN LTST-C191KRKT
F1, F2: 300mA; Fuseholder_Cylinder-5x20mm_Schurter_0031_8201_Horizontal_Op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; Manufacturer PN 0031.8201
H1, H2, H3, H4: MountingHole_Pad; MountingHole_3.2mm_M3_Pad
HS1, HS2, HS3: Wakefield-Vette 287-1AB; Heatsink_Wakefield-Vette_287-1AB_TO-220_Vertical; Manufacturer PN 287-1ABE
J1: Conn_01x04_Male; Molex_KK-396_A-41791-0004_1x04_P3.96mm_Vertical; Manufacturer PN 026614040
J2, J3, J4: Conn_01x03_Male; Molex_SL_A-70543-0002_1x03_P2.54mm_Vertical; Manufacturer PN 705430002
J5, J6: Conn_01x02_Male; Molex_SL_A-70543-0001_1x02_P2.54mm_Vertical; Manufacturer PN 705430001
JP1, JP2, JP3, JP4, JP5, JP6: Jumper_NC_Small; PinHeader_1x02_P2.54mm_Vertical
R1: 100; R_1206_3216Metric_Pad1.42x1.75mm_HandSolder; Manufacturer PN RT1206FRE07100RL
R2, R3: 10k; R_0603_1608Metric_Pad1.05x0.95mm_HandSolder; Manufacturer PN RT0603FRE0710KL
R4, R5, R6: 100k; R_0603_1608Metric_Pad1.05x0.95mm_HandSolder; Manufacturer PN RT0603FRE07100KL
R7: 1k; R_0603_1608Metric_Pad1.05x0.95mm_HandSolder; Manufacturer PN RT0603FRE071KL
U1, U3: LM7815_TO220; TO-220-3_Vertical; Manufacturer PN L7815ABV
U2: LM7915_TO220; TO-220-3_Vertical; Manufacturer PN L7915ACV

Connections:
/+15_unreg: C3.1, C5.1, C11.1, D5.1 (K), D9.2 (A), D11.1 (K), JP3.2, U1.1 (VI), U3.1 (VI)
/-15_unreg: C4.2, C6.2, D6.2 (A), D10.1 (K), JP5.2, U2.2 (VI)
/transformer_center: J1.2, J1.3, JP4.1
/transformer_minus: F2.2, J1.4
/transformer_plus: F1.2, J1.1
GNDA: C3.2, C4.1, C5.2, C6.1, C7.2, C8.1, C9.2, C10.1, D7.2 (A), D8.1 (K), H1.1, H2.1, H3.1, H4.1, HS1.1, HS2.1, J2.2, J3.2, J4.2, JP4.2, JP6.1, R2.2, R3.1, R4.2, R5.1, R7.2, U1.2 (GND), U2.1 (GND)
GNDRELAY: C11.2, C12.2, C13.2, D12.2 (A), HS3.1, J5.2, J6.2, JP6.2, R6.2, R7.1, U3.2 (GND)
unnamed: C1.1, C2.1, D1.1 (K), D3.2 (A), JP1.2
unnamed: C1.2, D2.1 (K), D4.2 (A), JP2.2, R1.2
unnamed: C2.2, R1.1
unnamed: D1.2 (A), D2.2 (A), JP5.1
unnamed: D3.1 (K), D4.1 (K), JP3.1
unnamed: D9.1 (K), R2.1
unnamed: D10.2 (A), R3.2
unnamed: F1.1, JP1.1
unnamed: F2.1, JP2.1
VCC: C7.1, C9.1, D5.2 (A), D7.1 (K), J2.1, J3.1, J4.1, R4.1, U1.3 (VO)
VEE: C8.2, C10.2, D6.1 (K), D8.2 (A), J2.3, J3.3, J4.3, R5.2, U2.3 (VO)
Vrelay: C12.1, C13.1, D11.2 (A), D12.1 (K), J5.1, J6.1, R6.1, U3.3 (VO)

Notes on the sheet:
LED RESISTORS Vf = 2V with R = 10k, I = 1.3mA with R = 1k, I = 13mA try R = 10k; if too dim try R = 1k
RESERVOIR CAPACITORS C = I * dt / Vpp I = 250mA dt = 8.33ms Vpp = 1-2V Vpp = 1V -> C = 2000uF Vpp = 2V -> C = 1000uF
clearance holes for M3 standoffs use insulated standoffs
OUTPUT CONNECTORS
INPUT CONNECTOR
USE INSULATING PADS FOR HEATSINK
Tie GNDA and GNDRELAY together through 1k resistor right at reservoir capacitors! optional jumper to directly short GNDA and GNDRELAY
AUX SUPPLY FOR RELAYS/FRONT PANEL
VCC Heatsink
VEE Heatsink
Vrelay Heatsink
CC-BY-SA 4.0


Board: 2 copper layers, 100.0 x 70.0 mm, 56 parts (0 on the bottom side), 19 nets.

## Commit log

2018-11-17 Update output coupling cap to be nonpolarized and add specific part details
    [volume_control.sch]
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2018-11-19 Add connectors to root sheet. Connector footprints may need to be changed
    [balanced_amplifier.sch]
2018-11-20 swap hot and cold inputs to preserve overall phase
    [balanced_amplifier.sch]
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2018-12-15 Initial import of netlist to pcb. Missing footprints for nonpolarized electrolytics
    [balanced_amplifier.kicad_pcb]
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2019-01-11 Update PCB to fix rev0 issues
    - update C21/C28 footprint, re-route
    - swap pin 1/3, 4/6 on RV2 (volume pot) so turning CW increases volume
    [balanced_amplifier.kicad_pcb]
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2019-03-26 Update power supply schematic
    add jumpers for measuring current
    remove redundant capacitors
    wire LEDs
    [power_supply.sch]
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2019-03-28 add note to change input bypass cap on 7915 to larger electrolytic
    [power_supply.sch]
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2019-03-31 update capacitors: add second pair of reservoir caps (DNP) and change input cap to 7915
    [power_supply.sch]
2019-03-31 Update power supply layout & schematic
    - Update snubber capacitor circuit details
    - add heatsinks & mounting holes to schematic (footprints incorrect or
    missing)
    - initial component placement in layout
    [power_supply.kicad_pcb, power_supply.sch]
2019-03-31 update footprints for mounting holes (8-32 clearance)
    [power_supply.sch]
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2019-04-07 add aux (relay/front panel power supply) to schematics/pcb. Also cleanup DRC violations in schematic
    [power_supply.kicad_pcb, power_supply.sch]
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2019-04-16 Update testpoint footprints on balanced amp board (revert 3dmodel to library default)
    [balanced_amplifier.kicad_pcb]
2019-04-16 update footprints to library defaults (3dmodel paths point to default 3dmodel paths)
    [balanced_amplifier.kicad_pcb]
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2019-04-21 update balanced amplifier todo -- which ground to connect mounting holes to?
    [balanced_amplifier.sch]
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2019-04-25 re-save input output board schematic to fix schematic corruption (KiCad 5.1.1 bug, fixed in 5.1.2)
    [input_output_board.sch]
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2019-04-27 fix input_selected net wiring in schematic
    [input_output_board.sch]
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2019-04-27 update relay footprints with fixed numbering
    [input_output_board.kicad_pcb]
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2019-04-28 fix DRC error and move board on page. NOTE: several items left in TODO
    [input_output_board.kicad_pcb]
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2019-05-02 draw initial schematic for front panel board. Resistor sizing and component selection still todo
    [front_panel_board.sch]
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2019-05-11 update chassis grounding in input/output board because jacks connect directly to chassis
    [input_output_board.kicad_pcb, input_output_board.sch]
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2019-05-12 add footprint for toggle switch and do inital layout (exact switch/LED placement tbd)
    [front_panel_board.kicad_pcb, front_panel_board.sch]
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2019-06-08 remove second set of reservoir caps (deemed unnecessary for ripple and take up too much space)
    [power_supply.sch]
2019-06-08 remove extra reservoir caps from layout and move remaining once to new location
    [power_supply.kicad_pcb]
2019-06-08 redesign input/output capacitors for regulators and add bleeder resistors on output caps
    [power_supply.sch]
2019-06-08 correct silkscreen text for jumper JP6 based on schematic reannotation
    [power_supply.kicad_pcb]
2019-06-09 finish basic routing. still need to thicken input traces, check TO-220 dims, and place labels/silkscreen decorations
    [power_supply.kicad_pcb]
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2019-06-10 resize board slightly (to metric dims) and add project/license info to pcb
    [front_panel_board.kicad_pcb]
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2019-06-10 add bom for power supply. Some component fields empty (not all parts mapped to actual MFNs)
    [power_supply.csv]
2019-06-10 update balanced amplifier TODO and swap power connector for molex SL
    [balanced_amplifier.sch]
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2019-06-11 change footprints for R4-6 to a resistor 0603 instead of capacitor 0603
    [power_supply.sch]
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2019-06-11 update gerbers and layout pdf with R4-6 footprint correction and new project rev
    [power_supply-B_Cu.gbr, power_supply-B_Mask.gbr, power_supply-B_SilkS.gbr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]
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2019-06-17 remove shield from internal audio connectors, change internal audio connectors to 1x2, and split input shields into four separate nets (one for each input)
    [input_output_board.kicad_pcb, input_output_board.sch]
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2019-06-21 add license info to schematics & layouts, including made with kicad logo, as well as project info to silkscreen
    [balanced_amplifier.kicad_pcb, balanced_amplifier.sch, front_panel_board.sch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]
2019-06-22 add jumpers to schematic to optionally bypass output relay. Update TODO. Clean up schematic
    [input_output_board.sch]
2019-06-22 add connector to bypass mute switch and change rotary switch to 8pos model
    [front_panel_board.sch]
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2019-06-23 add jumpers to layout to bypass output relay. placement not yet final
    [input_output_board.kicad_pcb]
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2019-06-23 update switch symbol/footprint, add second relay control connector, and re-layout (LED not laid out)
    [front_panel_board.kicad_pcb, front_panel_board.sch]
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2019-09-14 Complete initial schematic for headphone amplifier
    Features present:
    - left and right channels
    - input connectors, output jack
    - balanced-to-unbalanced converters
    - power connector
    - bulk capacitance
    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
    [headphone_amp.sch]
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2019-09-14 change connectors to be horizontal, and add initial *rough* placement of parts to layout
    [headphone_amp.kicad_pcb, headphone_amp.sch]
2019-09-15 Update layout of input/output board
    - remove jumpers to bypass output relay. Jumper wires can be soldered
    onto relay footprint instead.
    - layout of output connectors complete
    - still need to finalize output connector choice & placement
    [input_output_board.kicad_pcb, input_output_board.sch]
2019-09-17 update schematic & layout so output connector is same as input connectors
    [input_output_board.kicad_pcb, input_output_board.sch]
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2019-09-21 update schematic symbols to NCJ6FA-H-0 (no release tab), update footprints to project-local versions
    [input_output_board.sch]
2019-09-21 update jack footprints in layout to project-local footprints from upstream pull request
    [input_output_board.kicad_pcb]
2019-09-21 move input/output connectors to line up with board edge, change output connector to XLR, adjust relay ground plane
    [input_output_board.kicad_pcb, input_output_board.sch]
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2019-09-22 update net labelling, change to SPDT switch for headphone selection, and clean up schematic
    [front_panel_board.kicad_pcb, front_panel_board.sch]
2019-09-22 initial layout for headphone amplifier. Still need to finalize mounting orientation and adjust connectors/mounting holes if necessary
    [headphone_amp.kicad_pcb]
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2019-09-26 Remove output resistors
    - remove output resistors for zero ohm output impedance
    - add 10k pulldown/bleeder resistors on output to prevent output cap
    charging with no load
    [headphone_amp.kicad_pcb, headphone_amp.sch]
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2019-09-27 update output cap footprint and bleeder resistor
    - update output cap footprint (20mm height vs 25mm to match actual part)
    - increase bleeder resistor value to 22k from 10k, to decrease corner
    frequency
    [headphone_amp.kicad_pcb, headphone_amp.sch]
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2019-09-28 fix footprint model paths for heatsinks
    [power_supply.kicad_pcb, power_supply.sch]
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2019-10-13 fix schematic/routing of headphone relay (reverse coil polarity)
    [input_output_board.kicad_pcb, input_output_board.sch]
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2019-10-13 Update Headphone Amp to fix opamp power supplies
    * fix opamp power supply connections. VCC was connected to V-, VEE to
    V+. Fixed.
    * re-layout opamp section to reflect above fix.
    * right and left input connectors swapped to allow above fix.
    * update schematic/layout date & revision in title block, and in board
    silk.
    [headphone_amp.kicad_pcb, headphone_amp.sch]
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

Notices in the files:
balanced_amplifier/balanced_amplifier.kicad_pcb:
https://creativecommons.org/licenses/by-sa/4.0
